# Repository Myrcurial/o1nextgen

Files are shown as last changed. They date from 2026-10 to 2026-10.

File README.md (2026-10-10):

# o1nextgen

A general-purpose Z80 bus interposer for the Osborne 1, built around the
Raspberry Pi Pico 2 W (RP2350 + CYW43439 WiFi), plus the research and
reverse-engineering work it enables — and, downstream, a modern-parts
Osborne 1 reproduction (the "O1 Next Generation").

## Goals

The Osborne 1 places all peripherals in memory-mapped banks and the Z80
has a simple, slow (4 MHz) external bus. A passive/active interposer
between the Z80 and its socket, connected to a Pico 2 over USB, enables:

1. **Bus analyzer** (passive): cycle-accurate capture of address/data/
   control traffic, streamed over USB — hardware equivalent of emulator
   machine-state introspection.
2. **Peripheral synthesizer** (active): emulate period hardware —
   RT-60A real-time clock, SCREEN-PAC 80/104-column video, IEEE-488
   "Drive C" ramdisk/storage, CoPower-88 mailbox interface.
3. **CPU emulation shim**: virtual CoPower-88 (8088) so original SWP
   software runs on machines without the (rare) physical board.

### Networked peripherals (Pico 2 W)

C64 Ultimate-style: rich browser UI on the Pico 2 W's HTTP server, plus a
small CP/M-side utility for in-machine control — no local mods required.

4. **Floppy interposer / image library** (Gotek / FlashFloppy analogue):
   interrupt the Shugart bus between motherboard and drives; mount
   `.IMD`/`.HFE` images to either drive bay, or to "Drive C" as a
   persistent RAM disk. Image library managed over WiFi (browser) or via
   a CP/M `MOUNT.COM` talking to the Pico through a mailbox port.
5. **WiFi modem** (Zimodem-style): Hayes-compatible AT command set +
   telnet, presented via the Osborne's memory-mapped 6850 ACIA registers
   (bank 2). Works with period comm programs (Kermit, XMODEM, etc.).
   **Extended scope (#56):** SSH transport (ESP32-class Zimodem fork) and
   baud-rate buffering — also designed as a *severable module* usable
   standalone on the MODEM (P1) port. Ref: https://github.com/bozimmerman/Zimodem
6. **Virtual printer**: capture Centronics-mode output on the IEEE-488
   port and render to PDF emulating a period 9-pin Epson MX-80 —
   two fonts, double-wide, italics, bold, underline; *no* graphics
   printout (ESC K/L) support. PDFs served over the HTTP interface.

> Timing note: CYW43 radio activity adds jitter. Bus capture and MFM
> floppy emulation run pinned to core1/PIO with WiFi IRQs fenced off,
> or WiFi is gated during capture/flux windows.

## Projects this supports

- **SWP CoPower-88 driver recovery for Osborne 1** — Kaypro and Zorba
  drivers exist; the Osborne version does not. Diff the known drivers,
  extract the host↔8088 protocol, port to the Osborne BIOS.
- **IEEE-488 mass storage** — Pico-based GPIB device emulating the
  "Drive C" ramdisk / period hard-disk products, with an updated O1
  boot disk.
- **Real-time clock** — emulate the RT-60A so original software works
  on unmodified machines.
- **USB keyboard adapter (#47)** — standalone RP2040 board on the P4
  keyboard connector: plug in any USB HID keyboard, no other mods.
  Doubles as the matrix-injection firmware for the interposer's
  web-KVM personality (#45).
- **O1 Next Generation (#49/#52)** — modern-parts Osborne 1
  reproduction running original ROMs/software, in two form factors:
  a 1:1 mainboard replacement for a stock chassis, and a ~8 cm thick
  "lunchbox" portable (O1A blue/grey industrial design, 8" 4:3 LCD,
  USB-C PD / 18650 power). See `hardware/o1ng/`.
- **FATCOPY (#51)** — native CP/M↔MS-DOS FAT12 (360K) file-copy
  utility; a PIP sibling for exchanging files with PC diskettes.

## What's changed since this README was first written

Phase 0 research (#1) has largely landed; see `docs/` and `research/`:

- **O1 mainboard memory + I/O map extracted** from the Rev E schematic
  (#40/#41) — `docs/o1-memory-io-map.md`.
- **Rev E schematic set indexed and extracted** (#64): the 12-page scan is
  actually *two* drawings — disk electronics (DWG 1A3004) plus the mainboard
  (DWG 1A2011-00 Rev E, sheets 1–9). The Z80 socket and the P8 floppy connector
  are now read from the primary source, and a native-resolution region renderer
  makes the rest readable — `docs/o1-mainboard-schematic.md`.
- **The O1 runs headless as an oracle** (#64): MAME's `osborne1` driver plus a
  small Lua harness boots CP/M and reads the screen straight out of video RAM,
  and `tools/check_o1_map.sh` goes further — it interrogates the running machine
  over its own bus and asserts the documented memory and I/O map. That is how we
  found that the bank latch does not persist across instruction fetches —
  `docs/o1-mainboard-schematic.md` §6–7a.
- **MODEM (P1) port documented** (#57): it is **TTL, not RS-232** —
  DE-9P feeding the 6850 ACIA directly, with an asymmetric *bipolar*
  RXD input — the clean attach point for the WiFi modem module.
- **P4 keyboard pinout corrected** (#48): O1A plug has 24 holes (inner
  20 mate); **pin 19 = +12V** via jumper J6 + R21 — power source for
  the USB keyboard adapter.
- **Logic family settled** (#54): all O1s are NMOS Z80s → **74AHCT/HCT**
  level shifting (replaces the earlier 74LVC245 note below). Interposer
  gets its **own dedicated 5 V feed** (sized for WiFi bursts).
- **Clocking documented** (#55): one-oscillator design + the "2x
  business turbo" option (and why baud buffering in #56 matters).
- **Disk tooling built** (#2/#34): TD0 decompressor + CP/M filesystem
  extractor in `tools/`; Kaypro CoPower-88 disks extracted; CoPower-88
  host protocol inferred from Kaypro vs Zorba (#36). Upstream cpmtools
  kpiv misread tracked in #35.
- **Peripheral analyses done**: Drive C GPIB ramdisk (#33), RT-60A RTC
  (#37), OCC1 ACT-1982 Z80-interposer winchester (#32).
- **Interposer prior-art survey** (#31) and **photo survey** of the
  host machine (#38) complete.
- **Osborne1FloppyAdapter KiCad project archived** with provenance (#50)
  — `research/osborne1/floppy-adapter/`.
- **Lunchbox concept render** (#53) — `docs/design/`.
- New scope filed: web-KVM console (#45), char-gen ROM capture (#44),
  G2 multi-format diskette support (#30), 1:1 replacement board +
  lunchbox case/power research (#52), FATCOPY (#51), SSH modem (#56).

## Repository layout

- `research/` — collected documentation, disk images, schematics
  - `research/copower88/kaypro/` — Kaypro CoPower-88 CP/M + MS-DOS disks,
    extracted CP/M contents + disassemblies
  - `research/copower88/zorba/`  — Zorba SWP disks, schematics (611-0003),
    system guide, advertisement
  - `research/drive_c/`          — Drive C IEEE-488 ramdisk image + manual
  - `research/rtc/`              — RT-60A real-time clock disk + manual
  - `research/harddisk/`         — OCC1 hard disk driver disk image
  - `research/osborne1/`         — O1 Technical Manual, mainboard schematic
    (Rev E), modem/serial + keyboard pinout sources, archived
    Osborne1FloppyAdapter KiCad project
  - `research/screenpac/`        — SCREEN-PAC service manual
  - `research/pictures/`         — high-res photos of the host machine
    (mainboard w/ double-density upgrade, SCREEN-PAC, CoPower-88 top/bottom,
    interposer)
- `docs/` — working notes and analysis: O1 memory/I/O map, modem/serial
  pinouts, CoPower-88 protocol + schematics, Drive C protocol, RT-60A
  register map, OCC1 hard disk analysis, interposer prior-art survey,
  photo survey, research-gap decisions, lunchbox concept renders
- `hardware/` — hardware device definitions (see `hardware/README.md`):
  Z80 interposer, front-panel UI pod, USB keyboard adapter, severable
  WiFi modem module, floppy adapter, O1 Next Generation reproduction
- `firmware/` — on-device firmware, one folder per component (see
  `firmware/README.md`): RP2350 interposer personalities (bus analyzer,
  RTC, printer, floppy, Drive C/GPIB, ScreenPac video, KVM, CoPower-88
  shim, web UI), ESP32 Zimodem fork, RP2040 keyboard matrix
- `software/` — Osborne-side CP/M software (see `software/README.md`):
  MOUNT.COM, FATCOPY, CoPower-88 driver, updated boot disk; plus the
  no-new-code deliverables (existing period drivers/configs, docs only)
- `tools/`   — disk image pipeline: TD0 decompressor + CP/M filesystem
  extractor (`cpmfs.py`, `edsk2raw.py`, `extract_all.sh`);
  `tools/trace-analyzer/` (planned) host-side bus trace capture;
  `tools/research/` for keep-worthy research/one-off code

## Hardware notes

- Z80 @ 4 MHz; RP2350 samples synchronously off the CPU clock via PIO.
- Target board: **Pico 2 W** (RP2350 + WiFi) — networked peripherals
  need the radio; the analyzer/synth personalities work on either.
- Level shifting: Z80 bus is 5V, RP2350 is 3.3V. **Settled: 74AHCT /
  74HCT** — all O1s are NMOS Z80s (production ended 1983; CMOS Z84C00
  didn't ship until 1985). AHCT/HCT is correct in both directions
  against NMOS I/O; 74LVC-class is marginal on tired NMOS outputs.
- Power: interposer gets its **own dedicated 5 VDC feed** near the Z80
  socket, sized for Pico 2 W WiFi bursts (~300 mA+).
- Filter /RFSH refresh cycles from traces.
- Must be stackable/coexist with SCREEN-PAC and CoPower-88 interposers
  on the fully-loaded machine.

## Sources

Full per-file provenance: `research/README.md`.

- Osborne 1 schematics and technical/service manuals: bitsavers.org (`pdf/osborne`)
- Drive C, RT-60A, OCC1 hard disk, diagnostics, Osmosis, Nuevo DD manual: bitsavers.org (`bits/Osborne/Osborne1/`)
- Shipped application library (14 disks): Dave Dunfield's ImageDisk archive, `dunfield.classiccmp.org`
- ROM images (stock revisions, vid8): Don Maslin's archive, retroarchive.org/maslin
- ROM 1.44 + CBIOS source, OZROM 1E, ScreenPac Rev A: github.com/BrettHallen/Osborne_1
- Adaptec ACB-4000 hard-disk software: archive.org/details/md-utilities-adaptec-4000-controller-ver.-1.93-osborne
- Kaypro CoPower-88 images: retroarchive.org/maslin
- Zorba SWP docs/schematics: zorba.z80.de/swp.htm (ZEPS)
- Osborne 1 Technical Manual (interface pinouts): kev.pulo.com.au
- GPIB reference implementation: NODISKEMU (nils-eilers) / cbmSD (cbmsteve.ca)

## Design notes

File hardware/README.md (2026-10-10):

# hardware/

Hardware device definitions for the o1nextgen project. Each subfolder is
one physical device contemplated in the GitHub issues, holding its
interface spec, design decisions, and (eventually) KiCad design files.
Status ranges from "concept definition" to "ready for schematic entry" —
no PCB layouts exist yet (Phase 1, issue #11).

## Devices

| Folder | Device | Issues | Status |
|---|---|---|---|
| `interposer/` | Z80 bus interposer — the core board. **Rev A engineering sample** (`interposer/reva/`, 2-off, SMD): active interposer w/ SMT Z84C00, /BUSRQ bus mastering (memory R/W + code injection), Pico 2 + ESP32-C3, W25Q library flash. Rev 0 passive probe superseded (kept for record) | #11, #12, #13, #15 | Rev A ES schematic generated, ready for KiCad capture review + routing |
| `front-panel-ui/` | Front panel faceplate & UI pod — SD/USB storage, VGA/HDMI out, OLED, FlashFloppy-style controls, modem LED bank | #14 | Concept |
| `usb-keyboard-adapter/` | Standalone RP2040 USB-HID → P4 keyboard adapter ("jam a USB keyboard into an O1"); two power variants: internal +12V (J6) or external powered-hub for no-open-case use | #47 | Reference design defined; spec validation pending |
| `wifi-modem-module/` | Severable WiFi modem (ESP32 Zimodem fork: telnet + SSH, baud buffering) for the MODEM (P1) TTL port; ships with COMM PAC-look case STLs for the left storage pocket | #56, #21, #57 | Concept; P1/DE-9 pinout + levels documented |
| `floppy-adapter/` | Switchable Gotek/physical-drive daughter card on the mainboard floppy connector — both physical drives *or* Gotek-as-drive-A + physical B, remote switch, switched Gotek 5 V; no cable cutting | #62, #20, #30 | Rev A schematic captured (`floppy-adapter.kicad_sch`); open questions settled (design doc §8); ready for footprint/routing review |
| `o1ng/` | O1 Next Generation — modern-parts Osborne 1 reproduction: faithful 1:1 replacement mainboard (socketed DIP-40 Z80, interposer as upgrade path; block-level KiCad skeleton in `o1ng/o1ng-lff/`) + fully integrated "lunchbox" portable (8 MHz turbo-capable, onboard flash library), shared USB-C PD power architecture | #49, #52, #53, #55 | LFF schematic skeleton generated; concept render exists |

## Cross-cutting decisions (settled)

- **Level shifting:** 74AHCT/74HCT for anything touching the Z80 bus —
  all O1s are NMOS Z80s (research-gaps #2, resolved 2026-10-09).
- **Interposer power:** dedicated 5 VDC feed near the Z80 socket, sized
  for Pico 2 W WiFi bursts (~300 mA+).
- **Stacking:** the interposer must coexist with SCREEN-PAC and
  CoPower-88 interposers on the fully-loaded host machine.
- **MODEM port (P1) is TTL, not RS-232** — but its RXD is a bipolar
  input; the modem module must swing TX-toward-O1 negative for a clean
  mark. See `docs/o1-modem-serial.md`.
- **P4 keyboard connector:** pin 19 = +12V via jumper J6 + R21 — usable
  to power small adapter boards (see `usb-keyboard-adapter/`).

## Conventions

Each device folder contains a `README.md` with: purpose, host
interfaces, electrical/mechanical constraints, open questions, and links
to the tracking issues and supporting docs. KiCad projects land in the
same folders as `<device>.kicad_pro` when design begins.

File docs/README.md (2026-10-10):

# docs/ — the analysis

Everything we have **concluded** about the Osborne 1, one Markdown document per
area. This file is the index and the house style for the directory.

## The three-way contract

| Where | Holds | Test |
|---|---|---|
| `research/` | **sources** — manuals, ROMs, disk images, photographs, with provenance | "would we lose the ability to do this work if the upstream link died?" |
| `docs/` | **conclusions** — what we worked out, and how we know | "can someone build against this without re-reading the raw material?" |
| GitHub issues | **work** — what is left, who is doing it, what closes it | "is there a unit of work here that can be finished and verified?" |

A doc should cite the `research/` files it derives from and the issues it
serves. An issue should cite the doc that will carry its result. Nothing should
exist in only one of the three.

## House rules

1. **Cross-references must resolve on the branch being merged.** If you cite
   `docs/foo.md` or `research/bar/`, that file has to exist on the branch the PR
   merges from — see AGENTS.md. Do not cite a doc you are about to write in a
   different PR.
2. **Never duplicate the archive.** Link into `research/` rather than copying
   scans, ROMs or images into `docs/`. The archive is provenance-tracked; a copy
   here is just drift.
3. **Say how you know.** Distinguish *measured* (a MAME run, a byte comparison),
   *read from a primary source* (schematic, ROM source, manual) and *inferred*
   (naming, convention, someone's forum post). The Z80 pinout table in
   `o1-memory-io-map.md` §6 was wrong for a day because an inference was written
   down as a fact.
4. **Cite the issue numbers** you serve, in the text (`#40`, `#62`), so the
   issue and the doc point at each other.
5. **Mermaid is welcome** for bus/state/timing diagrams.
6. **Tables beat prose** for pinouts, port maps, register maps and inventories —
   and give units and addresses in the same base throughout.

## Status vocabulary

Each doc should carry a one-line status near the top, using these words, so the
gap review (`research-gaps.md`) and the issues can be cross-checked quickly:

| Status | Means |
|---|---|
| **Solved** | The question is answered and the answer is checkable from the doc |
| **Partially solved** | The main shape is known; a named sub-question is not |
| **Open** | Not answered |
| **Superseded** | The question stopped mattering (better route found, hardware decision taken) |

## The docs

| Doc | Answers | Issues | State |
|---|---|---|---|
| `o1-memory-io-map.md` | Memory banks, I/O decode, bank switching, interrupts, connector pinouts, free I/O windows | #40, #62, #64, #72 | Solved (port map confirmed by the ROM source; decode *granularity* is schematic-level) |
| `o1-mainboard-schematic.md` | Sheet-by-sheet index of the Rev E schematic set, device list, pinouts, the machine-level oracle | #62, #64 | Solved |
| `o1-rom-variants.md` | Every ROM image, CRC32s, the three MAME machines' ROM requirements, third-party ROM survey | #70, #44 | Solved |
| `o1-rom-source.md` | Index of the ROM 1.44 / CBIOS source, and the port map and interfaces it confirms | #72, #40 | Solved |
| `mame-emulation.md` | Running the three machines, ROM requirements, boot-disk compatibility, headless testing | #79, #24, #29 | Solved |
| `drive-c-protocol.md` | Drive C (IEEE-488 RAM disk) command set and handshake | #6, #22 | Partially solved — command set from `DCL`/`DFD.SPR` still to finish |
| `occ1-harddisk-analysis.md` | The Osborne 1 hard-disk products: interface, files, command set | #8 | Partially solved — two distinct products now identified; controller command sets open |
| `copower88-protocol.md` | CoPower-88 host protocol from the Kaypro + Zorba drivers | #3, #4, #5, #23 | Partially solved — residual doorbell/IRQ semantics |
| `copower88-schematics.md` | Walkthrough of SWP drawing 611-0003 (4 sheets) | #5 | Solved |
| `rt60a-analysis.md` | RT-60A register map, reconstructed from the manual | #7, #18 | Partially solved — needs a read against real hardware |
| `o1-modem-serial.md` | MODEM (P1) and RS-232 (P2) interfaces, 6850 ACIA | #21, #56 | Solved |
| `floppy-adapter-design.md` | Switchable Gotek / physical-drive daughter card | #20, #62 | Design |
| `interposer-survey.md` | Prior art: open-source Z80 bus interposers, sniffers, ICEs | #11, #17 | Survey |
| `virtual-peripherals-block-diagram.md` | Bus and address-space allocation for the virtual peripherals | #12, #16 | Design |
| `photo-survey.md` | Index of the project's own machine photographs | #9, #39 | Reference |
| `research-gaps.md` | **The status review**: every gap, where it stands, what is left | #1 | Living document |

## Subdirectories

| Path | Holds |
|---|---|
| `design/` | Generated artefacts — the "lunchbox" concept PDF/SVG (#52) |
| `mame-screens/` | Evidence screenshots from MAME runs, referenced by `mame-emulation.md` |

## Adding a doc

1. **Check whether an existing doc owns the area.** Extend it rather than adding
   a near-duplicate; `docs/` grew one document per *area*, not per question.
2. **Name it `<device>-<kind>.md`** — `protocol` (the contract a device speaks),
   `analysis` (what we worked out from a source), `design` (what we intend to
   build), `survey` (prior art). Kebab-case, lower case.
3. **Open with the status line**, then what the doc answers, then the sources.
4. **Add a row to the table above** in the same PR.
5. **If it closes a gap**, update `research-gaps.md` in the same PR.

## Relationship to the book

`#75` is the plan to assemble these documents into one coherent Osborne 1
reference once the research issues are closed. These docs stay the working
notes; the book is a consolidation pass, not a second source of truth. Write
them so they can be lifted into it — self-contained, sourced, and honest about
what is still unknown.

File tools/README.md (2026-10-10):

# tools/ — disk images, CP/M filesystems, scanned schematics, machine checks

## Pipeline

```
.td0 --[SAMdisk 4]--> .dsk (EDSK) --[edsk2raw.py]--> .raw --[cpmfs.py]--> files
.imd --[disk-analyse]--> .raw --[cpmfs.py]--> files
```

Run everything: `tools/extract_all.sh [path-to-samdisk]`

## Components

- **edsk2raw.py** — EXTENDED CPC DSK (SAMdisk output) to raw CP/M
  sector image. Sorts sectors by R id (handles interleave and Kaypro's
  side-continuous sector numbering: side0 = 0-9, side1 = 10-19).
  `--pad SECTRK,SECLEN` emits fixed-geometry images from partial dumps
  (missing sectors -> 0xE5).
- **cpmfs.py** — read-only CP/M 2.x list/extract (`ls`, `get`,
  `getall`). Explicit geometry presets: `osb1sssd` (Osborne 1 SD:
  40x10x256B FM, boottrk 3, 2K blocks), `kp2x`/`kpiv` (Kaypro DSDD:
  80 logical trk side-per-track x 10 x 512B, boottrk 1, 2K blocks).

## Reading scanned schematics (`schematic_render.sh`, `schematic_atlas.sh`)

Renders sheets — or a zoomed region of one sheet — from a scanned schematic
PDF. The archive schematics are 600 dpi bilevel scans; scaled to a screen the
pin numbers are unreadable, and the PDF's own text layer is a 1990s OCR pass
full of garbage, so they have to be read one region at a time at native
resolution.

```
tools/schematic_atlas.sh PDF [OUTDIR]                     # overview + tile grid, all sheets
tools/schematic_atlas.sh PDF build/atlas --sheet 5 --cols 3 --rows 3
tools/schematic_render.sh PDF --info                      # sheet size in px, page count
tools/schematic_render.sh PDF OUTDIR --sheet 12 --dpi 600 # one sheet, native res
tools/schematic_render.sh PDF OUTDIR --sheet 12 --dpi 600 --crop X Y W H
```

`schematic_atlas.sh` writes `OUTDIR/index.md` mapping every tile to the pixel
box it covers, plus `OUTDIR/sheet-NN/overview.png` and `rRcC.png` tiles. It
defaults to `build/atlas/` — gitignored, because the tiles are regenerable and
the *coordinates* are the durable part, so a region found by eye once can be
re-rendered exactly with `schematic_render.sh --crop`. Both tools require
poppler (`pdftoppm`, `pdfinfo`) — already needed by `ocr_pdf.sh`.

**Part numbers must be read at native resolution.** At 300 dpi `LS00`/`LS08`
and `LS138`/`LS139` are indistinguishable; an overview pass over the O1
mainboard got both wrong. The sheet index, the regions read this way, and what
that caution means for the device lists are in
`docs/o1-mainboard-schematic.md`.

## Machine checks (`check_o1_map.sh`)

Boots an Osborne 1 headlessly under MAME and interrogates it over its own bus,
then asserts what `docs/o1-memory-io-map.md` claims — which pages are RAM,
where the ROM is and how it mirrors, what the bank-switch ports do, and which
bank-2 I/O windows answer.

```
tools/check_o1_map.sh                    # 12 checks, exits non-zero on failure
O1_ROMPATH=... O1_FLOPPY=... O1_MACHINE=... O1_SECONDS=180 tools/check_o1_map.sh
```

`tools/o1_mame_probe.lua` holds the assertions and the method (RAM is told from
ROM by writing back the complement of the byte that was there and restoring it).

Requires `mame` and a ROM path. If the ROMs sit loose in one directory rather
than in an `osborne1/` directory or an `osborne1.zip`, the wrapper builds a
temporary rompath containing an `osborne1` symlink rather than making you
rearrange them.

**The boot image's name is a label, not a driver.** The `52-`/`80-`/`104-`
prefix records the video mode an image was prepared for, but it does **not** gate
what the image can boot: measured against MAME, all three of
`emulator-setup/floppies/*.imd` boot on `osborne1`, `osborne1sp` **and**
`osborne1nv`. What gates bootability is the CBIOS on the disk. The wrapper still
derives the machine from the prefix (52 → `osborne1`, 104 → `osborne1sp`,
80 → `osborne1nv`) and warns when it selects anything but the stock machine, but
pass `O1_MACHINE` explicitly when it matters. The measured matrix, and why the
Nuevo system disk is a separate problem, are in `docs/mame-emulation.md` §4.

It is the counterpart to `check_schematics.py`: that one checks our own boards,
this one checks our *understanding of the machine* against the machine. It has
already earned its keep — see `docs/o1-mainboard-schematic.md` §7a.

## Emulator setup (`emulator-setup/`)

The ROM sets and blank boot images the MAME checks need, committed so the
harness is reproducible without hunting for dumps:

- `emulator-setup/roms/` — **one `osborne1.zip` serves all three machines**
  (`osborne1`, `osborne1sp`, `osborne1nv`): `rev1.40.ud11`, `rev1.43.ud11`,
  `3a10082-00rev-e.ud11`, `char.ua15`, `7a3007-00.ud15`,
  `monrom-rev1.51-12.ud11`. `mame osborne1nv -verifyroms` reports *good*;
  `osborne1` and `osborne1sp` report *best available* because the only missing
  ROMs are the four BIOS revisions that have never been dumped (A, 1.2, 1.2.1,
  1.3). Per-machine requirement table: `docs/mame-emulation.md` §3; CRC
  inventory: `docs/o1-rom-variants.md`.
- `emulator-setup/floppies/` — `52-blank.imd`, `80-blank.imd`, `104-blank.imd`.
  Despite the name they are **not blank**: each is a double-density CP/M 2.2
  system disk (CBIOS 1.4, MBASIC, SYSGEN, PIP, SETUP, XDIR, XREF …), and the
  three differ by exactly two bytes in the boot area. All three boot on all
  three machines — see the correction above.

The ROMs duplicate `research/roms/` deliberately: `research/` is the
provenance-tracked archive, this directory is a working rompath. If the two
ever disagree, `docs/o1-rom-variants.md` is the tie-breaker.

Full setup, launch, disk-tool and headless-testing instructions:
**`docs/mame-emulation.md`**.

## Schematic checking (`check_schematics.py`)

Regenerates each board's netlist with `kicad-cli` and asserts the electrical
invariants the design depends on. Run it before committing any `.kicad_sch`
or `gen_*_sch.py` change:

```
python3 tools/check_schematics.py          # all boards
python3 tools/check_schematics.py -v       # per-net detail
```

Why it exists: a schematic can pass structural ERC and still be electrically
wrong. The interposer generators placed every pin mirrored (`y + py` where
KiCad needs `y - py`), and reva had a '595 sitting directly on top of a '165 —
ERC reported only `label_dangling` / `pin_not_connected`, nothing that named
the fault. Reading the netlist pin by pin found both. What it checks:

- **Datasheet pinouts.** Z80 DIP-40 (pin 11 = +5V, 29 = GND, 30 = A0) on every
  connector/CPU that mates with the O1's socket.
- **Connector pin usage.** The Gotek header carries exactly Loxley's 11 signal
  lines and never a power rail or 4 MHz; drive B is never switched.
- **Sheet geometry.** No two symbol bodies overlap, and no two differently
  named labels sit on the same point (that is a short).
- **No `NC` net.** Labelling unused pins "NC" ties them all together — on reva
  that joined four unused 74AHCT595 totem-pole outputs. Use no-connect flags.
- **ERC budget.** Per-type ceilings; any new violation type or any increase
  fails, so regressions cannot hide in the warning noise. Keyed on the type
  only — KiCad renames checks and moves them between error and warning across
  releases (KiCad 9's `label_dangling` error is KiCad 10's `isolated_pin_label`
  warning), so a severity-keyed budget would pin the gate to one KiCad version.
- **Generator drift.** Regenerates each board and compares netlists, so a
  committed `.kicad_sch` cannot silently diverge from its generator.

CI runs it on every change to `hardware/**/*.kicad_sch` or `gen_*_sch.py`
(`.github/workflows/schematic-check.yml`). Requires `kicad-cli` (KiCad 7+);
set `KICAD_CLI` if it is not on PATH. Standard library only.

## Tool evaluation notes (why this exists)

- **SAMdisk 4** (Simon Owen; built from source, macOS: cmake) —
  decodes TeleDisk TD0 including advanced compression. Cannot write
  IMD; refuses raw output for non-sequential sector ids -> we bridge
  via EDSK. `samdisk copy in.td0 out.dsk`.
- **disk-analyse** (Keir Fraser, Disk-Utilities) — does NOT read TD0,
  but converts IMD -> raw img cleanly and reports per-track format
  (great for unknown disks).
- **libdsk dsktrans** — failed on the Kaypro TD0 ("Bad format" after
  decompression checks) and on SAMdisk EDSK output.
- **cpmtools 2.23** (homebrew cpmls/cpmcp) — worked perfectly for
  Osborne SSSD (`osb1sssd`) raws, but silently misread the Kaypro DSDD
  image (stock `kpiv` def has blocksize 2048 vs actual directory
  structure; even corrected defs produced garbage, cause not fully
  diagnosed — possibly sides/boottrk handling). cpmfs.py replaces it
  for extraction; cpmtools remains handy for quick probes.
- **z80dasm 1.2.0** (brew) — OK for spelunking; linear sweep misaligns
  around data tables.

## Disk format cheat sheet (learned during #2)

- Osborne 1 SD: FM, 40 cyl, 10x256B sectors, R=1..10, boottrk 3,
  dir 64 entries (2K blocks).
- Kaypro 2X/4/10: MFM, 40 cyl x 2 heads, 10x512B per side, R 0-based
  continuous across sides (0-9 / 10-19), physical interleave in R,
  dir at logical track 1 (= cyl 0 head 1), 64 entries, 2K blocks.
- RT-60A.TD0 (bitsavers) is a DAMAGED dump: 27 no-id sectors ignored
  by SAMdisk, most tracks fragmentary; filesystem extraction fails.
  Needs a re-dump (see #7).

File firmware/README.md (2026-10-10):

# firmware/

Firmware deliverables for the o1nextgen project, one folder per
component. Three target platforms: **RP2350** (Pico 2 W on the
interposer), **ESP32** (WiFi modem, shared between the severable module
and the interposer-onboard option), and **RP2040** (keyboard matrix
injection, shared between the standalone adapter and the KVM/second-
keyboard path).

See `software/` for code that runs on the Osborne itself (CP/M) and
`tools/` for host-side utilities.

## Components

| Folder | Platform | Component | Issues | Difficulty |
|---|---|---|---|---|
| `bus-analyzer/` | RP2350 | Passive cycle-accurate bus capture → USB/WiFi; includes the shared memory-map snoop/poke engine all personalities build on | #17 | Hard (timing-critical) |
| `rt60a-rtc/` | RP2350 | RT-60A real-time clock register emulation | #18, #37 | Easy |
| `virtual-printer/` | RP2350 | Virtual Epson MX-80: Centronics-on-IEEE-488 capture → on-device 9-pin raster → PDF (with tractor-feed page edges) over HTTP | #19 | Medium |
| `floppy-emulator/` | RP2350 | MFM flux interposer + `.IMD`/`.HFE` image library ("Drive C" RAM disk option) | #20 | Hardest |
| `drive-c-gpib/` | RP2350 | Drive C IEEE-488 ramdisk/storage device personality, incl. the **TurboPac** variant (Drive C as cache in front of a Trantor hard disk) | #22, #6 | Medium |
| `occ1-harddisk/` | RP2350 | ACT 1982 Z80-interposer winchester personality — original driver set already in hand, no Osborne-side code needed | #8, #32 | Medium |
| `screenpac-video/` | RP2350 | SCREEN-PAC 80/104-col video + HDMI/VGA out; char-gen socket tap, reads installed font ROM at init | #24, #44 | Medium-hard |
| `kvm-console/` | RP2350 + RP2040 | Web KVM: video snoop (reuses screenpac-video) + keyboard matrix injection (reuses keyboard-matrix) | #45 | Medium (composition) |
| `copower88-shim/` | RP2350 | Virtual CoPower-88: 8088 emulation + host mailbox protocol so SWP software runs without the physical board | #23, #3-#5 | Hardest; sequence last |
| `web-ui/` | RP2350 | C64 Ultimate-style HTTP interface: image library, modem, printer PDFs, status, control | #16, #27 | Medium |
| `zimodem-fork/` | ESP32 | Zimodem fork: Hayes/telnet baseline + SSH + double-sided baud-rate buffer | #21, #56 | Medium (fork-and-extend) |
| `keyboard-matrix/` | RP2040 | TinyUSB HID host → 8×8 matrix injection; shared by the standalone adapter, KVM, and front-panel USB port | #47, #45, #14 | Easy-medium |

## Project rule

**If we hold the drivers for a piece of period hardware, we plan a
personality for it.** Existing drivers mean zero Osborne-side software
work and a known-good test suite — these personalities are pure win.
(Current examples: Drive C, ACT/OCC1 hard disk, RT-60A.)

## Cross-cutting constraints

- **Radio jitter:** CYW43 activity adds jitter — bus capture and MFM
  flux emulation run pinned to core1/PIO with WiFi IRQs fenced off, or
  WiFi is gated during capture/flux windows.
- **One modem codebase:** the ESP32 Zimodem fork serves both the
  severable module and (leaning) an interposer-onboard ESP32; see
  `hardware/interposer/README.md` for the decision record.
- **Level shifting** is a hardware concern (74AHCT/HCT) — firmware
  assumes clean 3.3 V logic at the RP2350 pins.

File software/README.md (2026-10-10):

# software/

Software that runs on the Osborne 1 itself (CP/M 2.2, 64 KB Z80) plus
its packaging. Host-side tooling lives in `tools/`; on-device code
lives in `firmware/`.

## Components

| Folder | Component | Issues | Difficulty |
|---|---|---|---|
| `mount-com/` | `MOUNT.COM` — mount disk images from the Pico-hosted library via mailbox port | #27 | Medium |
| `fatcopy/` | `FATCOPY.COM` — CP/M ↔ MS-DOS FAT12 (360K) file copy, PIP-sibling syntax | #51 | Medium |
| `copower88-driver/` | Osborne 1 host driver for CoPower-88 (real board or interposer shim) | #26, #3-#5 | Hard |
| `rt60a-clock/` | RT-60A host software replica: CLOCK.COM/CLKSET reimplemented from the manual (original TD0 dump is damaged) | #7, #37 | Medium |
| `boot-disk/` | Updated O1 boot disk: storage + RTC integration, G2 multi-format DPBs, bundled utilities | #28, #30 | Medium (integration) |

## No-new-code deliverables (documentation only)

Where existing period software does the job, the deliverable is a
setup/usage doc shipped in `docs/` and on the boot disk — not new code:

- **Drive C ramdisk / interposer hard disk on native CP/M** — the
  original Drive C driver and OCC1 hard disk driver work as-is once the
  corresponding personality is running (#22, #8); write usage notes.
- **Stock Zimodem** — until the fork (`firmware/zimodem-fork/`) lands,
  stock ESP32 Zimodem covers telnet; document known-good config.
- **FlashFloppy/Gotek** — publish a known-good `FF.CFG` for the O1 and
  the switchable floppy adapter (`hardware/floppy-adapter/`).
- **cpmtools / disk-analyse recipes** — image in/out workflows for
  development (upstream kpiv fix tracked separately as #35).

## Constraints

- 64 KB Z80 CP/M 2.2: tiny TPA footprint; assembly or compact C
  (e.g. z88dk/Hi-Tech) only.
- Everything must fit the updated boot disk (#28) alongside the
  period drivers.
- Utilities use the BIOS disk path and must coexist with the G2
  multi-format disk-table changes (#30).

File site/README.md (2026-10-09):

# site/ — project blog (GitHub Pages)

Source for the project's GitHub Pages site: the story of how this
project came to be, hardware-mod write-ups for the author's Osborne
machines, and the ongoing build log.

## Publishing

Jekyll, minimal config. Two supported ways to publish (pick one in
repo Settings → Pages):

1. **GitHub Actions** (recommended): the standard "Deploy Jekyll site"
   workflow with the source directory set to `site/` — publishes on
   every merge to `main`.
2. **Branch deploy**: an Action (or manual step) that pushes `site/` to
   a `gh-pages` branch.

(The usual `/docs` Pages source is unavailable — our `docs/` is the
engineering-notes tree and stays as-is.)

## Layout

- `_config.yml` — Jekyll config (title, theme, permalinks)
- `index.md` — landing page
- `_posts/YYYY-MM-DD-title.md` — blog entries
- `assets/` — images; keep photos reasonably sized and prefer links to
  `research/pictures/` where the same photo already exists in-repo

## Planned articles (tracking issue)

- My first computer
- How I met Lee Felsenstein
- Finding the CoPower-88
- My battery-powered Osborne 1
- Modification to support Gotek drives with 3D-printed floppy-disk
  faceplate
- Why this project at all
- Build log (1/n)

Also planned: write-ups of the hardware modifications made to two of
the author's three Osborne machines (one extensive).

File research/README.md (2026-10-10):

# Research archive — sources and safety copies

This directory is the project's **research archive**: the documentation,
disk images, and photographs that the reverse-engineering and design work
under `docs/` and the GitHub issues depend on.

**These files are reserved as safety copies of the documentation necessary
to complete this project.** They are committed in-repo on purpose: upstream
archives move, go offline, or drop files, and this project cannot finish
without these specific documents. If an upstream link dies, the in-repo
copy is authoritative. Please do not "clean up" large PDFs or disk images
from this tree — their presence here is the point.

Where each item was sourced is recorded below, so provenance is preserved
alongside the copies.

**OCR convention:** most of the scans here have no text layer. When a
document is OCR'd for research, the text is committed **adjacent to the
PDF** as `<filename>.ocr.txt` (e.g.
`drive_c/Drive_C_Users_Manual.ocr.txt`) so it never has to be
regenerated. Regenerate with `tools/ocr_pdf.sh` if a better pass is
needed.

## osborne1/ — Osborne 1 mainboard documentation

| File | What it is | Sourced from |
|---|---|---|
| `2F00153-01_Osborne1TechnicalManual_1982.pdf` (19 MB) | Osborne 1 Technical Manual, 1982. No text layer — image-only scan. Theory of operations, banking, I/O, video, disk, keyboard. | [bitsavers](https://bitsavers.trailing-edge.com/pdf/osborne/osborne1/2F00153-01_Osborne1TechnicalManual_1982.pdf) |
| `OCC1_1A2011-00_Schem_RevE.pdf` (1.2 MB) | **Two drawing sets in one 12-page scan.** Pages 1–3: DISK ELECTRONICS, DWG 1A3004-00/01 Rev C (sheets 1–3 of 3 — the *drive's* own board). Pages 4–12: MAIN PC BOARD, DWG 1A2011-00 Rev E (sheets 1–9 of 9). 600 dpi bilevel; the embedded text layer is a useless early-90s OCR pass. Indexed, and the Z80 socket and P8 floppy pinouts extracted, in `docs/o1-mainboard-schematic.md` (#62). | [bitsavers](https://bitsavers.org/pdf/osborne/osborne1/OCC1_1A2011-00_Schem_RevE.pdf) (also mirrored as `Osborne_1_Schematics_1A2011-00_Rev_E.pdf` on RetroTechCollection/Internet Archive) |
| `OCC1_1A2011-00_Schem_RevE.ocr.txt` | OCR text layer for the above (per the convention below), generated 2026-10-10 at 400 dpi. Good enough to grep for component references; **not** reliable for pin-level detail — read sheets visually with `tools/schematic_render.sh`. | — |
| `keyboard/osborne_keyboard_pinout.html` + `keyboard/PROVENANCE.md` | Verbatim capture of the pinouts.ru Osborne 1 keyboard page: P4 pinout (incl. pin 19 = +12V via J6+R21) and the full key matrix map. Used by #45/#47. | [pinouts.ru](https://old.pinouts.ru/InputCables/osborne_keyboard_pinout.shtml), captured 2026-10-08 (provenance in the folder) |
| `floppy-adapter/` (README, LICENSE, `.sch`, `.kicad_pcb`, PROVENANCE.md) | Snapshot of WayneVisser's Osborne1FloppyAdapter KiCad project — passive Gotek adapter documenting the O1's "Shugart-like" floppy interface (power over the cable's unused pins). Used by #20/#49. | [github.com/WayneVisser/Osborne1FloppyAdapter](https://github.com/WayneVisser/Osborne1FloppyAdapter), captured 2026-10-09 (provenance in the folder) |
| `modem/o1techman-interface-extract.pdf` (1 MB, 10 pp) | Chapter 4 "Osborne 1 Interface Design" extract of the O1 Technical Manual: §4.1 IEEE-488 (P3), §4.2 RS-232 (P2), **§4.3 MODEM (P1)**. Authoritative source for the MODEM DE-9P pinout — **TTL levels, not RS-232** — incl. pin 4 MSB, pin 5 CTS, pin 8 MCB, pin 9 RI, pin 7 +12V via 22Ω. Used by #56 (and #21/#12). | [kev.pulo.com.au/osborne1](https://www.kev.pulo.com.au/osborne1/documents/o1techman.pdf), captured 2026-10-09 |

Basis for `docs/o1-memory-io-map.md` (#40) and
`docs/o1-mainboard-schematic.md` (#62). Both scans are image-only; extraction
is manual — OCR for text pages, and for schematics a native-resolution region
render (`tools/schematic_render.sh`) read by eye. The mainboard map is
independently cross-checked against the running machine in MAME; see
`docs/o1-mainboard-schematic.md` §7 (#64).

## inspired-by/ — adjacent projects

`inspired-by/README.md` — other Osborne 1 reinventions (MAME cyberdeck,
Raspberry Pi brain transplant, Loxley's Gotek mod): what they did, and
what we take from each. Contrast defines the project: **we keep the
original machine intact**.

## mx80/ — Epson MX-80 printer references

| File | What it is | Sourced from |
|---|---|---|
| `mx80/Epson_MX-80_Operations_Manual.pdf` | Epson MX-80 operation manual; Appendix 4 (PDF p. 97+) has the character-font tables (6×9 matrix) and ESC code reference. | [Internet Archive / manualsbase](https://dn790002.ca.archive.org/0/items/manualsbase-id-381505/381505.pdf), captured 2026-10-09 |
| `mx80/EPSON_MX-80_Fonts_v1.0.zip` + `mx80/fonts/` | Michael Walden's MX-80 font pack (CC BY-NC-SA 4.0). Convenience cross-check; see the folder README for the double-strike/2×-width caveat. | [mw.rat.bz/MX-80](https://mw.rat.bz/MX-80/), captured 2026-10-09 |

Also: `drive_c/Drive_C_Users_Manual.ocr.txt` — OCR text layer for the
image-only Drive C manual scan (generated 2026-10-09 per the OCR
convention above; source of the TurboPac details used by
`firmware/drive-c-gpib/`).

References for the virtual Epson MX-80 printer personality (#19).

## screenpac/ — OCC ScreenPac (80-column upgrade)

| File | What it is | Sourced from |
|---|---|---|
| `2F00040_service_2ndEd_1983.pdf` (12 MB) | Osborne Field Service Manual, 2nd Edition, 1983. Covers the ScreenPac upgrade (Z80 + char-gen socket taps, dual-port video RAM). §6.12 documents the ScreenPac IC-harness fly-lead solder connections (used by `firmware/screenpac-video/`). | [bitsavers](https://bitsavers.trailing-edge.com/pdf/osborne/2F00040-00_Service2ndEdition_1983.pdf) |
| `2F00040_service_2ndEd_1983.ocr.txt` | OCR text layer (per the convention above), generated 2026-10-09 | — |

The ScreenPac is the mechanical/electrical template for the interposer and
for the video-output (HDMI) personality (#24, #9 photos).

## copower88/ — SWP CoPower-88 (Z80-coprocessor board being reverse-engineered)

| Path | What it is | Sourced from |
|---|---|---|
| `zorba/Co-Power-88guide.pdf`, `zorba/Co-Power-88advert.pdf`, `zorba/611-0003-1..4.pdf` | SWP CoPower-88 user guide, advertisement, and SWP technical document scans (Zorba-flavored set) | [zorba.z80.de](http://zorba.z80.de/files/swp/) — the Zorba Portable Computer archive site |
| `zorba/*.td0`, `kaypro/*.td0` | TeleDisk images of CoPower-88 CP/M-86 / DOS boot disks (Zorba and Kaypro versions) | zorba.z80.de (exact path not recorded in repo history) |
| `zorba/extracted/`, `kaypro/extracted_cpm/`, `*/disasm/` | CP/M files extracted from those images by the project pipeline (#2), and disassemblies of the CoPower RAM-disk/DOS drivers | Derived in-project — not external sources |
| `swp/Copower_User_guide.pdf`, `swp/Swp_ad.jpg` | Fuller CoPower-88 user guide (4.7 MB, not the Zorba set) and an SWP advert scan | [kayprojournal.com `Swp_copower_88`](https://kayprojournal.com/index.php/Swp_copower_88) — `File:Copower User guide.pdf`, `File:Swp ad.jpg` |
| `swp/1600px-73356_8088_card.jpg`, `swp/1600px-73356_mem_card.jpg`, `swp/866px-73356_cpu_card.jpg` | Board photographs of the CoPower-88 8088 card, memory card and CPU card — held as MediaWiki thumbnails (1600 px / 866 px) of `File:73356 8088 card.jpg`, `File:73356 mem card.jpg`, `File:73356 cpu card.jpg` | Same page: [kayprojournal.com `Swp_copower_88`](https://kayprojournal.com/index.php/Swp_copower_88) |

The whole `swp/` set is from that one page. Confirmed 2026-10-10 by querying the
wiki's API (`list=allimages` and `prop=images&titles=Swp copower 88`) and matching
all five `File:` names exactly — not by reading the rendered page text. The wiki
also carries `File:Copower sch 1..4.pdf`, a second copy of the SWP schematics we
hold from zorba.z80.de.

Basis for #3/#4/#5 (CoPower-88 protocol analysis). The board's own 8088 ROM is
`roms/swp-p88.rom` — see `roms/` below and #70.

## drive_c/ — Drive C (IEEE-488 ramdisk, #6)

| Path | What it is | Sourced from |
|---|---|---|
| `Drive_C_Users_Manual.pdf` | Drive C user manual (IEEE-488 virtual disk drive) | [bitsavers `bits/Osborne/Osborne1/Drive_C/`](https://bitsavers.org/bits/Osborne/Osborne1/Drive_C/) (upstream name `Drive_C_-_Users_Manual.pdf`) |
| `DRIVE_C.IMD` | ImageDisk image of the Drive C utility disk (label comment `Drive C for the Osborne 1 computer`) | same folder — **not** imaged in-project; corrected 2026-10-10 |
| `Drive_C_disk_label.jpg` | Photo of the physical disk label | same folder (15 044 B, byte-identical) — **not** a project photo; corrected 2026-10-10 |
| `extracted/` | Files extracted from `DRIVE_C.IMD` by the project pipeline (#2) | Derived in-project |

## rtc/ — RT-60A real-time clock (#7)

| Path | What it is | Sourced from |
|---|---|---|
| `RT-60A_Manual.pdf` | RT-60A RTC manual (JG Communications) | [bitsavers `bits/Osborne/Osborne1/Osborne_1_Real_Time_Clock/`](https://bitsavers.org/bits/Osborne/Osborne1/Osborne_1_Real_Time_Clock/) (upstream name `RT-60A_Real_Time_Clock_Manual_-_Osborne_1.pdf`) |
| `RT-60A.TD0` | TeleDisk image of the RT-60A utility disk — **a damaged dump** (27 no-id sectors); filesystem extraction fails, see `tools/README.md` | same folder |

## harddisk/ — ACT/OCC1 hard disk (#8)

| Path | What it is | Sourced from |
|---|---|---|
| `OCC1_HARDDISK.IMD` | ImageDisk image of the OCC1 hard-disk system disk (label comment `act-osborne / hard disk software / rev 2`) | [bitsavers `bits/Osborne/Osborne1/_floppy_images/`](https://bitsavers.org/bits/Osborne/Osborne1/_floppy_images/) — **not** imaged in-project; corrected 2026-10-10 |
| `extracted/` | Files extracted from the image, incl. `hardbios.hex` | Derived in-project |

## adaptec/ — Adaptec ACB-4000 hard-disk software (2026-10)

Raw Osborne 1 SSSD floppy images (102 400 B = 40 tracks × 10 sectors × 256 B,
**no IMD header**) each with a photo of the disk's label. Source: Internet
Archive, [`md-utilities-adaptec-4000-controller-ver.-1.93-osborne`](https://archive.org/details/md-utilities-adaptec-4000-controller-ver.-1.93-osborne).

| File | What it is |
|---|---|
| `MD Utilities Adaptec 4000 Controller Ver. 1.93 Osborne.img` | Adaptec ACB-4000 utilities |
| `MD Utilities Adaptec 4000 Controller Ver. 1.93 Osborne - MD-10 MD-20.img` | Same, for the MD-10/MD-20 drive pair |
| `Osborne Hard Disk Control Software Version 2.01 (1984).img` | Osborne's own hard-disk control software |

Together with `acb4000a.rom` (Maslin's archive) this identifies the controller
behind `harddisk/OCC1_HARDDISK.IMD` — issue #8.

## diagnostics/ — Osborne 1 confidence tests (2026-10)

| File | Label comment |
|---|---|
| `DIAG_2.04.IMD` | `2.04 / diagnostics` |
| `OCC1_DIAG_2.1.IMD` | `occ diag / ver 2.1 / 12/31/84` |

Source: [bitsavers `bits/Osborne/Osborne1/_floppy_images/`](https://bitsavers.org/bits/Osborne/Osborne1/_floppy_images/).
These are the known-good boot images the validation matrix (#29) needs.

## nuevo/ — Nuevo Electronics double-density upgrade (2026-10)

| File | What it is | Sourced from |
|---|---|---|
| `Nuevo_Electronics_DD_Upgrade_Manual.pdf` (13 MB) | DD upgrade manual | [bitsavers `bits/Osborne/Osborne1/`](https://bitsavers.org/bits/Osborne/Osborne1/) (13 810 755 B, exact match) |
| `OS1NUEVO.IMD` | `Osborne 1 with DD and 80 col mods` boot disk, re-imaged 2026-10-10 with Disk-Utilities | derived in-project |

> **Removed 2026-10-10: `NUEVO151.BIN`.** It was a byte-identical duplicate of
> `tools/emulator-setup/roms/monrom-rev1.51-12.ud11` — same 4096 bytes, SHA-256
> `aec8f5be127fdff5d30cae0b7f45ee48d13a8c1d5745a262b944b9ba67778906`, CRC32
> `298da402` — verified with `cmp` before deletion. It carried no provenance of
> its own, so the tracked emulator-set copy, which has a recorded source, is the
> one we keep. The BIOS strings are unchanged by this: `COPYRIGHT 1983, OSBORNE
> COMPUTER CORP. / COPYRIGHT 1984, NUEVO ELECTRONICS CORP.`

Nuevo shipped **two** products — a DD upgrade and an 80-column board — and
neither matches Osborne's own implementation of that function; see #73.

`OS1NUEVO.IMD` **is** the Nuevo 80-column system disk: its system area carries
`CBIOS vers 1.5` and the text *"THIS IS AN EIGHTY (80) COLUMN DISPLAY FOR THE
OSBORNE ONE"*. It does **not** currently boot under MAME — it prints the CBIOS
banner and stops (measured over 260 emulated seconds; the pristine upstream copy
behaves the same), which blocks validating the Nuevo video path in the emulator.
See #79 and `docs/mame-emulation.md` §4.

## osmosis/ — Osmosis Computer upgrades (2026-10)

Source: [bitsavers `bits/Osborne/Osborne1/Osmosis_Upgrades/`](https://bitsavers.org/bits/Osborne/Osborne1/Osmosis_Upgrades/) — all seven files byte-for-byte identical.

`Osmosis_CPM_Disk_Emulator.pdf`, `Osmosis_80_Column_Board.pdf`,
`Osmosis_SSDD_Upgrade.pdf`, `OSMO-EMU.TD0`, `OSMOS-DD.TD0`, plus two disk-label
photos. Osmosis likewise shipped two products (a CPM disk emulator and an
80-column board). **The 1983 CPM Disk Emulation System is direct prior art for
this project** — see #73 and `inspired-by/`.

## gotek/FF/ — working Gotek configuration (2026-10)

`FF.CFG` + `IMG.CFG` — the project's own Gotek configuration for the O1:
`interface = shugart`, `pin02`/`pin34` = `nc`, and an `IMG.CFG` default of
40 cylinders × 1 head × 16 × 128 B, FM, 125 kbit/s — i.e. O1 SSSD. Captured
from the physical Gotek, so these are primary sources, not downloads.
Used by #62 and #20.

## roms/ — ROM images (2026-10)

Canonical inventory, CRC32s and the third-party ROM survey are tracked in #70.
Files here come from two sources:

- `os1-143.rom`, `os1-144.rom`, `os1-vid8.rom`, `os1vid80.rom`, `swp-p88.rom` — [Don Maslin's ROM archive](http://www.retroarchive.org/maslin/disks/roms/) on retroarchive.org
- `OZROM-1E/OZROM_1E.BIN`, `OZROM-1E/OZROM_1E_Manual.pdf`, `OCC1_ScreenPac_RevA.BIN` — [github.com/BrettHallen/Osborne_1](https://github.com/BrettHallen/Osborne_1) `ROM/`

`swp-p88.rom` is **8088 code, not Z80**: the SWP co-processor board's own ROM.
The board and interposer card are common to every host machine (only the driver
varies), so this is the 8088-side firmware of the CoPower-88 family — #3/#4/#5.

`OZROM-1E/OZROM_1E_Manual.ocr.txt` — OCR text layer for the OZROM manual
(image-only scan; generated 2026-10-10 at 300 dpi with `tesseract`, per the OCR
convention above). Good enough to grep for the technical appendices — which is
how the IEEE-488 removal and the 3 KB video window were found (#81) — but not
reliable for exact code or pin detail.

## shipped-software/ — the shipped application library (2026-10)

Fourteen ImageDisk images of the disks that shipped with (or were published
for) the Osborne 1. The ImageDisk label comment is quoted because it is the
disk's own identity. Source: **Dave Dunfield's ImageDisk archive**
(`dunfield.classiccmp.org`, which rotates its directory to discourage deep
links) — `d/osborne1.zip` and `d/o1ddsys.zip`, byte-identical to these copies.

| File | Label comment |
|---|---|
| `O1CPM.IMD` | `Osborne-1 CP/M System Disk / Double Density` |
| `O1CBMB.IMD` | `Osborne 1 - CBASIC/MBASIC / Double Density` |
| `O1SCALC.IMD` | `Osborne 1 - SuperCalc 1.12 / Double Density` |
| `O1WSMM.IMD` | `Osborne 1 - WordStar/MailMerge 2.26 / Double Density` |
| `OS1SYSD.IMD` | `CP/M-2.2 system disk for Osborne 1 w/ DD drives / SSDD 1024 byte sector` |
| `OS1SYSS.IMD` | `CP/M 2.2 System Disk for Osborne 1 / SSSD 256 byte sector` |
| `OS1BASIC.IMD` | `CP/M 2.2 Basic Disk for Osborne 1` |
| `OS1DBASE.IMD` | `dBase II for the Osborne 1 on sysgened disk` |
| `OS1DIAS.IMD` | `CP/M 2.2 Diagnostics Disk for Osborne 1` |
| `OS1MCAL.IMD` | `CP/M 2.2 Mocro-Call Disk for Osborne 1 (Communications)` |
| `OS1MDM7.IMD` | `Modem 740 communications for Osborne 1` |
| `OS1UTLS.IMD` | `CP/M 2.2 Utilities Disk for Osborne 1` |
| `OS1XUTLS.IMD` | `Extended utilities for Osborne 1 w/ 80 column video card` |
| `OS1WRDST.IMD` | `CP/M 2.2 WordStar 3.0 Disk for Osborne 1` |

The corpus for the image library (#20), the updated boot disk (#28) and the
validation matrix (#29). Dunfield also publishes a 2005 single-density set
(`O1CPMS.IMD`, `O1CPMU.IMD`, …) which is deliberately **not** copied here.

## source-code/ — Osborne's own firmware source (2026-10)

| Path | What it is | Sourced from |
|---|---|---|
| `BIOS-144-source/` (18 files) | **The original Osborne ROM source**: `rom144.asm` (DOUBLE DENSITY ROM REV 1.44, Roger W. Chapman, 2/4/1983), `occbio05..95.asm` (OCC CBIOS Rev 1.41), `occram15/25.asm`, `occtxt6.ast` (ACT80 assembler equates), `bios141.gen`, `release.txt`, `tran.txt`. Basis for #72. | [github.com/BrettHallen/Osborne_1](https://github.com/BrettHallen/Osborne_1) `ROM/Source_Code_v144/` (all 18 file sizes match) |
| `OCCCBIOS.IMD`, `OCCROM.IMD`, `OCCUTIL.IMD`, `OSBIOSSR.IMD`, `OSBROM.IMD`, `OSROM13.IMD`, `OSUTLSRC.IMD` | OCC engineering **source disks** (1981–82): CBIOS, ROM rev B, utility programs, ROM 1.3. The ImageDisk comments carry the OCC part numbers (`4d2007-00 occbi00a.asm`, `rev b 9/12/81`). | bitsavers |

**Licensing:** `release.txt` is Osborne's 1985 letter permitting the First
Osborne Group to reprint the schematics and the BIOS listing, on condition that
any money goes to the non-profit FOG and that the trademark/copyright notices
are retained. FOG is long defunct and this material is already public in
several places — this copy came from a public GitHub repository. The notice is
retained verbatim; if the terms ever need re-examination, that is the file.

## pictures/ — machine photographs

`IMG_4856.jpeg` … `IMG_4871.jpeg` — disassembly/mainboard/upgrade-board
photos of the project's own machines (mainboard, double-density upgrade,
ScreenPac, CoPower-88). Taken in-project for #9; these are primary sources,
not copies. Further photo sets are tracked in #39.

## Provenance

The two long-standing **provenance gaps are closed**: the Drive C manual and
the RT-60A manual/TD0 both come from bitsavers'
[`bits/Osborne/Osborne1/`](https://bitsavers.org/bits/Osborne/Osborne1/)
(`Drive_C/` and `Osborne_1_Real_Time_Clock/`), as does `OCC1_HARDDISK.IMD` and
the two diagnostic disks (`_floppy_images/`). Four rows that had been recorded
as in-project work or as unknown URLs were corrected on 2026-10-10.

**Both remaining TODOs are closed (2026-10-10, #74):**

- `copower88/swp/` — kayprojournal.com's
  [`Swp copower 88`](https://kayprojournal.com/index.php/Swp_copower_88) page; all
  five files matched by `File:` name through the wiki API (CoPower-88 table above).
- `nuevo/NUEVO151.BIN` — removed as a byte-identical duplicate of the tracked
  `tools/emulator-setup/roms/monrom-rev1.51-12.ud11` (nuevo/ table above).

No provenance TODOs remain.

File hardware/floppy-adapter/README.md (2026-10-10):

# floppy-adapter — switchable Gotek/physical-drive daughter card

A daughter card that mounts over the mainboard / double-density board
floppy connector and makes **three drives available, two active**: both
original drives, *or* drive A + Gotek, selected by a user-accessible
switch. All interception happens at the mainboard-end connector — the
OEM floppy IDC cable is never cut or modified.

Inspiration (not a copy): Richard Loxley's Osborne restoration series —
[part 14](https://www.richardloxley.com/2018/04/24/osborne-restoration-part-14-usb-floppy-emulator-a-semi-permanent-solution/)
and [part 15](https://www.richardloxley.com/2018/04/25/osborne-restoration-part-15-usb-floppy-emulator-finishing-off/)
(also a YouTube series) — which proved the concept with a spaghetti of
hand-cut Dupont cables, an extension cable with a severed drive-select
line, and a DPDT switch + 5 V relay soldered onto the Gotek itself.
This design moves all of that work onto a PCB at the connector end of
the cable, where it belongs.

Tracking: **#62** (design spec + schematic). Feeds #20 (floppy
interposer personality) and #30 (G2 multi-format support). Prior art
archived by PR #50. Full design in
[`docs/floppy-adapter-design.md`](../../docs/floppy-adapter-design.md);
its seven open questions were **settled 2026-10-10** (§8 there) and the
**Rev A schematic is captured** (below).

## Design

- **Mezzanine mount:** plugs onto the mainboard (or DD-board) 34-pin
  floppy header; the OEM floppy cable re-plugs into a pass-through
  34-pin connector on the daughter card. Fully reversible, no
  modifications to the machine or its cables.
- **Second 34-pin connector:** routes the floppy bus out to a Gotek
  (FlashFloppy) mounted in one of the floppy storage pockets.
- **Switching:** drive-select A (pin 10) is routed on-card either to
  the OEM-cable pass-through (physical drive A) or to the Gotek
  connector. The remote switch lead carries only a low-current logic
  select line to an on-card switch element (relay or 74CBT-class bus
  switch) — the switch itself is a plain panel-mount SPST, trivially
  mounted next to the Gotek in the storage pocket.
- **Gotek power:** dedicated 5 VDC connection on the Gotek connector,
  fed via an on-card switch so the Gotek can be fully depowered in
  "both physical drives" mode. Both +5 V **and** GND are switched —
  switching one rail alone fails (`docs/floppy-adapter-design.md` §4.2).
- **Drive B is never switched** — it stays on the pass-through, so the
  machine always boots from a physical disk if desired. The Gotek takes
  drive A's place.
- **DS-A pull-up:** the O1's 150 Ω term pack lives on drive A, so the
  card adds a pull-up on the Gotek-side DS-A net (1 kΩ default) —
  `docs/floppy-adapter-design.md` §4.5.

## Signals carried to the Gotek

(Per the blog's audit — 11 lines plus power; the card routes the full
bus to be safe.)

| 34-pin | Signal |
|---|---|
| 8 | Index |
| 10 | Drive select A (**switched**) |
| 18 | Direction |
| 20 | Step |
| 22 | Write data |
| 24 | Write gate |
| 26 | Track 0 |
| 28 | Write protect |
| 30 | Read data |
| odds | Ground |
| — | +5 V (switched, on-card) |

## Lessons from the reference build (designed in, here)

- **Power-switching a Gotek is subtle.** Switching only +5 V fails —
  the O1's pulled-up signal lines parasitically power the board;
  switching only GND makes the *other* drive unreliable (shared +5 V
  reference with floating ground). The blog's fix was switching both
  rails with a DPDT plus a 5 V relay for drive select. We solve this
  properly on-card: high-side load switch for Gotek 5 V and a
  bus-switch/relay for drive select, so the remote switch handles no
  power at all.
- **Gotek physical fit:** with its top cover removed a Gotek fits a
  floppy storage pocket; top-facing headers make it too tall — plan a
  right-angle/side connection or direct-wire pads on the ribbon.
- **Cable egress:** a 34-pin ribbon won't pass the pocket ventilation
  slots; the daughter card should output the Gotek run on a slimmer
  cable (only the needed signals + power) that does.
- OLED display mods and FlashFloppy display-detect quirks are the
  user's Gotek-side choice, out of scope for the card.

## KiCad capture (Rev A)

- `floppy-adapter.kicad_sch` (+ `.kicad_pro`) — structural Rev A schematic.
- `gen_floppy_adapter_sch.py` — generator; edit the net tables and re-run
  (`python3 gen_floppy_adapter_sch.py`), then open/re-save in KiCad to
  normalise.
- **J1** female 2x17 socket (O1 logic-board P8), **J2** pass-through header to
  the OEM cable, **J3** Gotek signal header, **J4** switched Gotek power,
  **J5** panel switch, **K1** 4PDT relay, **D1/R1** flyback + coil pull-down,
  **R3/R4** DS-A pull-up, **R2+D2** optional indicator.
- Validated with `kicad-cli sch export netlist` (netlist matches the design
  doc's net table) and `kicad-cli sch erc` (0 errors).
- Layout follow-ups: the relay pin numbers are **DIP-14 logical placeholders**;
  assign footprints at layout (KiCad ships no G6A-434P footprint).

## Settled decisions (2026-10-10)

The seven design questions are closed — see
[`docs/floppy-adapter-design.md`](../../docs/floppy-adapter-design.md) §8 for
the evidence behind each. Highlights:

- O1 floppy header is **male** (logic-board P8), so **J1 is a female socket**.
- **Relay** (not solid-state) for Rev A.
- Switch **DS-A + both power rails** only — Loxley's proven minimum.
- **1 kΩ** DS-A pull-up default, **150 Ω** alternative footprint.
- Gotek drive-select jumper: **S1 first, S0 fallback** (bench-verify).
- Gotek sits in the **right-hand** pocket on a reduced ~12-line pigtail.

## Open items (not blocking capture)

- Mounting: piggyback footprint vs. standoffs over the DD board; confirm
  keep-outs against the mainboard schematic
  (`research/osborne1/OCC1_1A2011-00_Schem_RevE.pdf`) and host photos
  (`research/pictures/`).
- Interaction with the interposer's floppy personality (#20): document
  which device owns the bus in each configuration.
- G2 upgrade (#30): believed BIOS/DPB-only, nothing at the connector —
  confirm.

## References

- `research/osborne1/floppy-adapter/` — archived Osborne1FloppyAdapter
  KiCad project (connector/pinout prior art; **not** this design)
- `research/osborne1/OCC1_1A2011-00_Schem_RevE.pdf`
- Richard Loxley, Osborne Restoration parts 13–15 (concept origin)

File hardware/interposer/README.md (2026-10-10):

# interposer — Z80 bus interposer (core board)

The centerpiece of the project: a board that sits between the Osborne 1's
Z80 and its socket, carrying a Raspberry Pi Pico 2 W (RP2350 + CYW43439).

Tracks: #11 (Phase 1 hardware design), #12 (electrical/mechanical
interface spec), #13 (Rev A schematic + PCB), #15 (Rev B SMD).

## Personalities hosted (firmware, Phase 2 #16)

- Passive bus analyzer (#17) — cycle-accurate capture → USB/WiFi
- RT-60A RTC emulation (#18)
- Virtual MX-80 printer, IEEE-488 Centronics capture → PDF (#19)
- Floppy interposer + image library (#20)
- WiFi modem via 6850 ACIA snoop (#21)
- Drive C / IEEE-488 storage device (#22)
- Virtual CoPower-88 8088 emulation shim (#23)
- SCREEN-PAC 80/104-column video + HDMI (#24; taps the char-gen socket
  UA15, reads whatever font ROM is installed — #44)
- Web KVM console (#45): video snoop + keyboard matrix poke

## Electrical definition (settled decisions)

- **CPU interface:** standard Z80 DIP40 socket + socket-safe pin header;
  4 MHz bus sampled synchronously via PIO.
- **Level shifting:** 74AHCT (or 74HCT) both directions — all O1s are
  NMOS Z80s; AHCT/HCT matches NMOS I/O thresholds. (Decision
  2026-10-09, research-gaps #2; supersedes "74LVC245-class".)
- **Power:** own dedicated 5 VDC feed from a rail near the Z80 socket,
  sized for Pico 2 W WiFi bursts (~300 mA+). (Decision 2026-10-09.)
- **Modes:** passive-tap vs active-drive switching; mode jumpers.
- **Stacking:** must coexist with SCREEN-PAC and CoPower-88 interposers
  on the fully-loaded machine; pass-through height matters.

## Modem: personality vs. onboard ESP32 (decision to make)

Two ways to deliver the WiFi modem (#21/#56) from the interposer:

- **(a) Pure firmware personality:** the Pico 2 W's CYW43439 provides
  WiFi; the modem is a Zimodem-style reimplementation on the Pico SDK /
  lwIP, snooping/driving the memory-mapped 6850 ACIA. Fewer parts, but
  SSH is not realistic on the Pico 2 W and the radio shares the RP2350
  with timing-critical PIO work (WiFi IRQ fencing needed).
- **(b) Onboard ESP32 adjacent to the Pico 2 W:** the interposer
  carries the same ESP32 module as the severable modem
  (`../wifi-modem-module/`), running the Zimodem fork with SSH +
  baud buffering; the Pico 2 W just bridges ACIA traffic to it. More
  BOM, but SSH works today, the modem firmware is shared with the
  severable module, and RP2350 timing stays clean.

Current leaning: **(b)** — one modem firmware codebase across both
devices, SSH capability, and cleaner real-time behavior. Confirm
before Rev A schematic (#13).

## Onboard storage: built-in diskette library

**Decision: include onboard library flash in addition to removable
media.** SD/USB (via the front-panel pod) is the bulk store, but the
interposer should carry enough onboard flash to hold a **built-in
library — at minimum the boot diskette** — so the machine is useful
with no card or stick inserted (and the o1ng lunchbox can boot
"factory" images out of the box).

- Option A: SPI NOR flash (W25Q-class, 16–64 MB) — trivially enough for
  dozens of O1 images (a DD image is ~400 KB); cheap, easy.
- Option B: eMMC or a second SD — overkill; not needed at O1 image
  sizes.
- Leaning: **A** — a handful of SOIC-8 flash chips' worth of library is
  effectively free. Exact sizing settled with #20's image format.

## Mechanical / revision plan (revised 2026-10-09)

- **Rev 0 "test probe"** — **superseded** (kept in `rev0/` for the
  decision record, incl. the '165 snapshot front end that Rev A
  inherits). Parts lead time for a passive probe was within days of an
  engineering sample of the active board, so the passive step is
  skipped.
- **Rev A engineering sample (`reva/`, 2-off, almost all SMD):**
  active interposer — SMT Z84C00 on board (pull the original CPU, drop
  the interposer in), /BUSRQ bus mastering, 595/165 shift-register
  drive+capture fabric, Pico 2 module + castellated ESP32-C3 for WiFi,
  W25Q library flash. Design goal: **the dev partner controls the
  hardware** — memory R/W, ROM dumping (incl. the CoPower-88 monitor
  ROM, resolving research-gaps #4 by direct read), code injection +
  execute. See `reva/README.md`.
- Rev A production (#13): incorporates ES errata.
- **Rev B (#15) — a separate product, not a revision:** Rev A is the
  mastering/debug instrument; Rev B is the **live-cycle personality
  engine**. Full RP2350B pin allocation in `revb/README.md`. The
  enabling decisions:
  - **Zero direct address pins:** a 74AHCT688 window comparator
    (595-programmable match) + **/WAIT cycle stretching** — the
    period-correct slow-peripheral mechanism — replaces 16 direct
    address lines with 2 (ADDR_HIT, /WAIT drive).
  - Timing-critical direct set is only: D0–7, /MREQ, /IORQ, /RD, /WR,
    /M1, CLK, DATA_OE/DIR — 13 pins.
  - **HSTX is fixed to GP12–19** on RP2350 → HDMI there, either/or
    with VGA on the same range.
  - **Status/LED bank moves to the ESP32** (charlieplexed or I²C
    expander); SD on SPI (4-bit SDIO-via-PIO deferred); I²C pair
    reserved for front-panel OLED/encoder/expansion.
  - The Rev A 595/165 fabric carries over wholesale and remains the
    pressure-relief valve for any slow line.
- Ribbon-cable header to the front-panel UI pod (`../front-panel-ui/`),
  which also carries the second-keyboard USB-A path (see
  `../front-panel-ui/`).
- Optional second tap: 24-pin char-gen socket (UA15) for the video
  personality — pinout confirmation from ScreenPac install pages +
  mainboard schematic (research-gaps #3).

## Open questions

- Exact free I/O decode windows — resolved in `docs/o1-memory-io-map.md`;
  verify chosen peripheral port bases against it.
- /RFSH refresh-cycle filtering strategy for traces.
- Physical 2×5 IDC orientation for the modem P1 connection (same
  validation class as the P4 keyboard pinout).

## References

- `docs/o1-memory-io-map.md`, `docs/interposer-survey.md`,
  `docs/virtual-peripherals-block-diagram.md`, `docs/research-gaps.md`
- Host machine photos: `research/pictures/`

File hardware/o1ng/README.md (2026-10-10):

# o1ng — O1 Next Generation (modern-parts Osborne 1 reproduction)

A new PCB built from currently-available components that runs the actual
Osborne 1 ROMs and (nearly) all original software — with a Cherry MX
mechanical keyboard, the interposer's floppy/modem/printer/storage
personalities onboard, and composite video out (HDMI optional).

Tracks: #49 (feasibility + build), #52 (case + power research),
#53 (concept render: `docs/design/o1ng-lunchbox-concept.*`).

**Verdict from #49: feasible, medium complexity.** The O1 is almost
entirely memory-mapped commodity MSI/LSI — no custom silicon. CPUs are a
non-issue: CMOS **Z84C00 is in current production** (the replica
deliberately uses modern CMOS silicon where the interposer interfaces
AHCT to the original NMOS part).

## Machine decomposition (by difficulty)

| Block | Approach | Difficulty |
|---|---|---|
| CPU + RAM + ROM | Z84C00 (new), 64 KB SRAM (replaces 16× 4116 DRAM + refresh), 27C128/Flash BIOS | Trivial |
| Video | Char-gen + CRTC-class logic; composite out, HDMI option (interposer video personality reusable) | Moderate |
| Floppy | 360K half-height drive + onboard DD data separator (enables PC 360K MFM reads → FATCOPY, #51) | Moderate |
| I/O (serial/GPIB/RTC) | 6850 ACIA, IEEE-488, RTC — interposer personalities onboard | Moderate |
| Keyboard | Cherry MX matrix; O1-compatible scan encoding | Low–moderate |

## Shared power architecture (#52)

- **USB-C PD trigger board** as primary input: 15 VDC (or 19–20 V) PD →
  clean on-board +5V and +12V rails. Replaces the entire original PSU —
  and gets the RIFA caps out of the mix.
- **Battery option:** a ~15–19 V input rail suits an 18650 pack (4S).

## Form factors (share the power design)

1. **1:1 mainboard replacement** — drops into an otherwise-stock O1/O1A
   chassis. **As true to the original as possible**: a faithful
   reproduction of the stock machine, including a **40-pin DIP socketed
   Z80** (Z84C00) — deliberately socketed so the **interposer
   (`../interposer/`) is the upgrade path**: anyone wanting the advanced
   features (bus analyzer, virtual peripherals, WiFi modem, Gotek
   switching) installs the interposer onto this board exactly as they
   would on a 1982 original. **L-shaped board**: skinny arm services
   left-hand-side ports (front-left screw boss); chunky short side
   mounts front/rear right bosses. Stock port locations (front ports,
   power, internal video, floppy connectors) and only **four mounting
   screws** constrain layout.
2. **"Lunchbox" (O1 Next Generation)** — Dolch / Compaq Portable III
   idiom in **O1A blue/grey** industrial design; "keyboard seals the
   unit" aesthetic retained. Unlike the 1:1 board, this is a **fully
   integrated single board** — the interposer's capability set (video,
   storage, modem, keyboard input) is thoroughly grafted in rather than
   stacked on, following the original design language. One reason:
   integration keeps the timing margins needed for the **clock-doubled
   8 MHz "business turbo"** (#55) — limited usefulness, but everyone
   will be fine with it. **Onboard library flash** (SPI NOR, per
   `../interposer/` decision): a built-in diskette library with at
   least the boot diskette, so the lunchbox boots "factory" images with
   no SD/USB inserted; removable media remains the bulk store.
   ~8 cm thick: mainboard + 8" 4:3 LCD
   (composite/HDMI in) + 18650 pack, detachable flip-up keyboard.
   Optional rear "backpack" for a physical 5.25" half-height drive.

## Open questions

- Final video pipeline choice (discrete TTL vs small FPGA helper).
- LCD panel + input board sourcing for the lunchbox.
- Chassis fabrication route (sheet metal vs printed) for the lunchbox.
- Which interposer personalities are *onboard* vs *optional modules*.

## References

- `docs/design/o1ng-lunchbox-concept.pdf` / `.svg` (#53)
- `docs/o1-memory-io-map.md` (the machine's whole address space)
- Issues #49 (reproduction), #52 (case/power), #51 (FATCOPY)

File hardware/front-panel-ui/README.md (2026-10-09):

# front-panel-ui — faceplate & UI pod

COMM-PAC-style faceplate covering one floppy storage pocket, providing
local physical UI for the interposer without opening the case.

Tracks: #14.

## Contents

- SD card / USB stick socket (disk-image library media)
- **Second USB-A port: keyboard input via the interposer** — a USB HID
  keyboard plugged in here is injected into the O1's keyboard matrix by
  the interposer (reusing the `../usb-keyboard-adapter/` RP2040 matrix
  firmware, #45/#47). The **original keyboard stays plugged in and fully
  functional**; the USB keyboard is an optional second input that just
  works, both live simultaneously.
- VGA or HDMI video out (SCREEN-PAC personality, #24)
- Small OLED status display
- Rotary encoder or 5-way d-pad (FlashFloppy-style menu UI)
- Hayes/USR-style LED bank: CTS/RTS/TX/RX/RING etc. (modem personality)
- Ribbon cable back to the interposer (`../interposer/`)

## Constraints

- Must route through the existing front-panel ventilation / IEEE-488
  openings — no case cutting on the host machine.
- All electronics on the interposer side of the ribbon where possible;
  the pod is mostly connectors + display + LEDs to keep the cable
  simple and the front end 5 V/3.3 V logic only.

## Open questions

- OLED controller choice (I²C vs SPI over the ribbon).
- Exact pocket geometry vs. COMM-PAC faceplate dimensions (measure
  against host machine photos, `research/pictures/`).
- Whether video out is HDMI (RP2350 HSTX/DVI) or VGA (resistor DAC) —
  decided with the #24 firmware personality.

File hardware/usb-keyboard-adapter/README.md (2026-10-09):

# usb-keyboard-adapter — RP2040 USB-HID → P4 adapter

**A USB port on the Osborne 1 you can jam a normal USB HID keyboard into
and have it work.** Standalone, always-on upgrade: no interposer, no
WiFi, no BIOS changes. Also the matrix-injection firmware base for the
interposer's web-KVM personality (#45).

Tracks: #47 (split out of #45). Target: PCBway build.

## Reference design

- **MCU:** RP2040 running a USB HID host stack (TinyUSB host mode) →
  8×8 matrix state. Chosen over Pico 2 W deliberately: no radio needed,
  lowest cost, standard chip for retro USB-HID-host adapters.
- **I/O:** watch 8 host row-drive lines (inputs), drive 8 column lines
  open-collector (matching the stock 74LS05 stage) — 16 GPIO.
- **Level shifting:** O1 keyboard lines are 5 V TTL; RP2040 is 3.3 V.
  Rows need 5 V-tolerant input handling; columns driven via open-drain
  buffer (74LVC07-class) so the adapter never fights the host.
- **Power (variant A — internal):** from **P4 pin 19 = +12V** (wired
  through jumper J6 + R21 22Ω; bridge J6 — a documented, reversible
  mod). On-board 12V→5V (or 12V→3.3V) buck; the 22Ω drop is negligible
  at RP2040 currents (~25–60 mA). Do **not** draw logic power from the
  column pull-ups.
- **Power (variant B — no-open-case):** powered from outside the
  machine so it works for users who don't want to open their Osborne 1
  at all. The adapter's USB-A port pairs with a **powered USB hub** (or
  a power-tee / 5 V feed on the adapter's upstream side): the RP2040
  draws its 5 V from the hub's external supply rather than from P4.
  J6 stays factory-open; the machine is untouched. The design should
  expose a power-source jumper (P4-12V vs external 5 V) so one PCB
  serves both variants. Note: in variant B the column lines are driven
  against a machine the adapter doesn't share power with — ensure
  common ground comes through P4 pins 1/20 and the open-drain column
  drivers tolerate the unpowered-machine / powered-adapter (and vice
  versa) states.

## Host interface — P4 keyboard connector (O1A)

Later O1A "blue/grey" machines: coiled cable, 24-hole plug, only the
inner 20 pins mate. Documented pinout (O1 Technical Manual via
pinouts.ru, 4/4 corroborating reports; corrected by #48):

- 1 = GND; 2–9 = rows A4, A0, A3, A6, A2, A5, A1, A7
- 10–17 = columns D0–D7; 18 = NC; **19 = +12V (via J6+R21)**; 20 = GND

## Spec validation required BEFORE layout

- [ ] Confirm pinout against `research/osborne1/OCC1_1A2011-00_Schem_RevE.pdf`
      and continuity-check a real O1A (rows vs columns, GND, pin 19
      +12V with J6 bridged; J6/R21 present on target board revisions).
- [ ] Confirm rows are driven low one-hot via open-collector inverters,
      columns pulled up to +5V via a 3.3K resistor pack.
- [ ] Scan timing: measure stock scan rate to size the RP2040 polling
      loop / PIO snoop.

## References

- `research/osborne1/keyboard/` (pinout source + provenance)
- `docs/research-gaps.md`, issue #45 (KVM personality reuse)

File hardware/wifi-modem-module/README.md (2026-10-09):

# wifi-modem-module — severable WiFi modem (ESP32, Zimodem fork)

Hayes-compatible WiFi modem for the Osborne 1, designed as a **severable
module**: usable standalone on the MODEM (P1) port, or as part of the
interposer (where the Pico 2 W personality #21 does the same job via
memory-map snooping instead).

Tracks: #56 (extension of #21). Physical interface documented by #57.

## Definition

- **Base:** Zimodem fork targeting **ESP32** (not ESP8266) — the ESP32
  build already carries the SSH client (`INCLUDE_SSH`), SD shell, FTP,
  SLIP/PPP; ESP8266 lacks the headroom.
- **New O1-specific work on top:**
  1. **SSH as first-class transport** — keys, host verification, session
     management via the web UI; `ssh` from the O1 into a modern host.
  2. **Baud-rate buffering/correction** — decouple O1-side ACIA rate
     from the far-end link rate; makes the 2× business turbo (#55)
     usable and quietly corrects the factory 600/2400 → 650/2600 quirk.

## Host interface — MODEM port (P1, DE-9P)

**TTL levels, not RS-232** — the port feeds straight into the 6850 ACIA
(status `2A00H` / data `2A01H`), bypassing the RS-232 level shifters.

- 1 GND · 2 TXD (TTL) · 3 NC · 4 MSB (open-collector) · 5 CTS ·
  6 RXD (**bipolar input**, −0.5…−10 V = 1) · 7 +12V via R21 22Ω ·
  8 MCB (TTL, low = suppress output) · 9 RI (TTL)
- **Asymmetric levels:** TXD/MCB/RI are plain TTL, but **RXD is bipolar**
  (LM1458 + 1N5231B zener front-end) — the module must swing
  TX-toward-O1 **negative** for a clean mark. Needs in-hardware
  validation; a small charge-pump or transistor level stage is expected.
- On-board P1 header carries DE-9 pin numbers straight through
  (schematic sheet 7); 2×5 IDC orientation to be confirmed on a real
  board (same validation class as #47's P4).

## Power

+12V available on DE-9 pin 7 (via R21) — same power trick as the
keyboard adapter; on-board regulator to 3.3 V for the ESP32.

## Enclosure

The module ships with STLs for a **"COMM PAC-look" case** that fits in
the **left floppy storage pocket** — period-authentic Osborne
industrial design so it reads as original kit, not a modern dongle.
Deliverables: `case/*.stl` (top/bottom shells, LED light-pipe window)
alongside the PCB. Case design should accommodate the DE-9P pigtail and
leave the pocket usable with the keyboard closed.

## References

- `docs/o1-modem-serial.md` (authoritative pinout + levels)
- `docs/o1-memory-io-map.md` §"6850 ACIA detail"
- Upstream: https://github.com/bozimmerman/Zimodem

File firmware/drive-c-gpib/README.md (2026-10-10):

# drive-c-gpib — Drive C IEEE-488 storage personality (RP2350)

Pico-based GPIB device emulating the "Drive C" ramdisk and period
IEEE-488 hard-disk products. When this personality runs, the **original
period driver works unmodified** on the CP/M side — no new Osborne-side
code beyond usage docs (`software/README.md` no-new-code list).

Tracks: #22; protocol from #6 / `docs/drive-c-protocol.md`; OCC1 hard
disk analysis `docs/occ1-harddisk-analysis.md` (#8/#32).

## Definition

- Implement the Drive C GPIB device state machine per
  `docs/drive-c-protocol.md` (extracted from `DRIVE_C.IMD`, #33).
- Storage backing: RAM disk (persistent where possible) and/or image
  files from the library, shared with `../floppy-emulator/`.
- Reference GPIB implementation: NODISKEMU (nils-eilers) / cbmSD
  (cbmsteve.ca).
- Optionally present the OCC1 ACT-1982 winchester behavior as a second
  personality once its protocol write-up is complete (#8).

## Variant: TurboPac (Drive C + Trantor hard disk)

Per the Drive C user manual (`research/drive_c/Drive_C_Users_Manual.pdf`,
OCR stored alongside as `Drive_C_Users_Manual.ocr.txt`): **TurboPac** is
the Drive C / Trantor hard-disk system in which *Drive C becomes a
hi-speed cache buffer in front of the hard disk* — "increasing the hard
disk throughput by as much as five times."

- The hard disk attaches to the Drive C **PRINTER/HARD DISK/8088 port** —
  no mechanical modifications to the O1.
- **192K TurboPac:** all of Drive C is cache. **384K TurboPac:** 256K
  cache + 128K fixed print buffer.
- CP/M parameters differ: 8K blocks, 512 directory entries per logical
  drive, 10/20/33 MB capacities (manual §7-3).
- Detaching the hard disk returns Drive C to normal portable
  RAM-disk/print-buffer operation.

Emulation note: a TurboPac personality = this Drive C emulation **plus**
a hard-disk backing device on the downstream port, with the cache layer
implemented in firmware (or trivially: serve the hard disk image
directly and treat "cache" as a no-op — we have no rotational latency
to hide; but implement the software-visible partitioning faithfully so
the original TurboPac software behaves).

## Deliverables

- GPIB device emulation module (snoop/poke engine)
- Backing-store integration + web-UI controls
- Compatibility test notes against the original Drive C driver disk
  (`research/drive_c/`)

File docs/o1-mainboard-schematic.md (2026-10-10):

# Osborne 1 mainboard schematic — extraction, sheet index and pinouts (#64)

`research/osborne1/OCC1_1A2011-00_Schem_RevE.pdf` is the primary source for
the O1's logic board. Until now it was read by eye, page by page, in a PDF
viewer: the scan is dense, the PDF's own text layer is unusable, and the 12
pages are actually **two different drawing sets**, which is easy to get wrong.
This document is the map of that archive item: what is in it, how to read it,
and what has been extracted from it so far.

## 1. What the file actually contains

12 pages. Each page is a single 1-bit JBIG2 scan at roughly 600 dpi
(6582 × 5137 px on a 785 × 610 pt sheet) — genuinely high quality; every pin
number is legible at native resolution.

Each page *also* carries a text layer, but it is an early-1990s OCR pass and is
garbage: the disc-controller sheet's title reads `J'U~ I 'IIS IO/OO-tOOnl`.
Ignore it. (It is left in the PDF; the fresh pass in §3 is the one to search.)

The 12 pages are **two drawing sets**:

| Pages | Drawing | Rev | Sheets |
|---|---|---|---|
| 1–3 | **DISK ELECTRONICS**, DWG 1A3004-00/01 | C | 1–3 of 3 |
| 4–12 | **MAIN PC BOARD**, DWG 1A2011-00 | E | 1–9 of 9 |

This distinction matters. The disk-electronics set (1A3004) is the *drive's
own* board — read amplifier, data separator, write driver, head connectors.
The mainboard set (1A2011) is the machine this project extends. Notes in this
repo have cited "DWG 1A3004" for mainboard facts, including the floppy
connector pinout; that citation is wrong (§5).

`research/README.md` describes the split as "sheets 1–3 are the disk analog
board (DWG 1A3004), sheet 4+ the main logic board" — correct in outline; the
exact drawing numbers and sheet counts are as tabulated above.

## 2. Sheet index

Titles are the drawing's own title-block text (sheet 1 of the mainboard set
has no block title; its function is read off the circuit).

| PDF page | Drawing / sheet | Function | Devices read off the sheet |
|---|---|---|---|
| 1 | 1A3004 1/3 | Disk read electronics: head pre-amp and peak detection, ALC, head connectors P1/P2 | U9, U10, U15, U16, U18, U19, U20 |
| 2 | 1A3004 2/3 | Disk data separator: index/sector, read data, drive connector P2 | U8, U12–U22 |
| 3 | 1A3004 3/3 | Disk write driver, erase, motor control, ±12 V/+5 V rails | U1, U2, U3, U6, U11, U12, U13 |
| 4 | 1A2011 1/9 | CPU clock (4 MHz), reset, data buffers, power entry | UD11, UD13, UE3, UE20, UC7, **UC11 = 74LS161** clock counter, UA6, UA8, J5, P6 (battery) |
| 5 | 1A2011 2/9 | Address decode, ROM/RAM/I-O select, WAIT generation | UC1, UC2, UD1, UD2, UD3, UD9, UD12, UE3, Q1/Q2 (reset timing) |
| 6 | 1A2011 3/9 | **CPU**: Z80-A, monitor EPROM, address latches | **UC11 = Z80-A**, **UD11 = 2732**, UD4, UD6–UD10, UE6, UE10, UE11, UA4 |
| 7 | 1A2011 4/9 | **RAM** array, address multiplex/buffer, **character generator ROM and its serialiser** | **UA15 = 2716** char-gen ROM and **UA14 = 74166** pixel serialiser (§4a), **UA18 = 74LS273** character latch (drives UA15 `A0–A6`), UA17/UA18 and the UA23–UA48 array (2114/2112 static RAMs per sheet 1's parts list), UE13–UE15 (74LS244), UE16–UE18 (74LS153), UD16 (74LS374) |
| 8 | 1A2011 5/9 | **VIDEO**: PIA, scan counters, video timing, brightness/contrast | **UC15 = 6821**, **UD17/UD18 = 74LS161** scan-line counters (preset from PIA `PB0–PB3`, outputs `SCAN0–SCAN3` → UA15 on sheet 4/9), UC16–UC21 (74166/74165), UA11–UA13, UB14/UB15 (74LS161), UE20–UE24 (7406), R40 (brightness), R44 (contrast). **UA14, UA15 and UA18 are on sheet 4/9, not here** — §4a. The rest of this row is still the first pass (§3) |
| 9 | 1A2011 6/9 | IEEE-488 interface (P3): PIA + open-collector bus drivers | **UC7 = 6821**, UD1 (74LS30), UD5 (74LS32), UD6/UD8–UD11 (7406), UE6/UE10 (74LS04), RN7/RN11–RN16 (3.3 K pull-ups) |
| 10 | 1A2011 7/9 | **SERIAL I/O**: ACIA + RS-232 level shifting, modem and CRT connectors | **UC4 = 6850**, UC14 (6551), UD1, UE1 (555), UE2 (1488), UE3 (1489), P1 (MODEM), P2 (9"/12" RS-232 CRT) |
| 11 | 1A2011 8/9 | **KEYBOARD**: row/column matrix, column drivers | UE12 (81LS95), UE13/UE14 (74LS05), RN10 (1.5 K), P4 (KEYBOARD) |
| 12 | 1A2011 9/9 | **DISC CONTROLLER** + the 34-pin floppy header | **UB7 = MB8877**, U7, U8, U9, U10 (7408/7406), U15 (74LS161), UD6 (74LS74), RN2 (150 Ω terminator), **P8** |

Sheets 4–12 are numbered 1–9 of 9 in their title blocks; the mainboard set is
complete in this scan.

> **Read the device lists at native resolution before citing them.** The
> *functions* in the last column are reliable; the part numbers came from a
> whole-sheet pass and at least two are known wrong (§3). `UC11` in particular
> appears twice — as the Z80 (sheet 3/9, verified at 600 dpi) and as a 74LS161
> (sheet 1/9, overview pass); only one can be right.

## 3. How to read a sheet

Whole-sheet views are useless — scale a 6582 px sheet onto a screen and the pin
numbers vanish. Read it one region at a time at native resolution. Two tools:

```
# browse: an overview plus a grid of native-resolution tiles for every sheet
tools/schematic_atlas.sh research/osborne1/OCC1_1A2011-00_Schem_RevE.pdf
#   -> build/atlas/index.md          tile map: page -> tile -> pixel box
#   -> build/atlas/sheet-05/r1c0.png native-res tiles you can just open

# then re-render any region exactly, once the index says where it is
tools/schematic_render.sh research/osborne1/OCC1_1A2011-00_Schem_RevE.pdf /tmp/s \
    --sheet 5 --dpi 600 --crop 2600 1250 1450 1050
```

`tools/schematic_atlas.sh` writes into `build/atlas/` — gitignored, because the
atlas is regenerable and the *coordinates* are the durable part. Its index maps
every tile to the pixel box it covers, so a region found by eye once can be
re-rendered exactly later. `--info` on the render tool prints the sheet size in
pixels at a given dpi. Both need poppler (`brew install poppler`), which
`tools/ocr_pdf.sh` already depends on.

**Read part numbers at native resolution, never from an overview.** At 300 dpi
`LS00` and `LS08` are indistinguishable, and so are `LS138` and `LS139`. The
first pass over this scan was done from whole-sheet views and got both of those
wrong on sheet 2: at 600 dpi it plainly reads **`UC1 LS00`** (quad NAND) and
**`UB1 LS139`** (dual 2-to-4 decoder — its pin numbers 15/14/13 for
enable/A/B and 12/11/10/9 for Y0–Y3 are exactly the second half of a '139).
The §2 device lists came from that first pass: treat the *functions* as
reliable and the part numbers as needing a native-resolution check before
anything is built on them. One conflict is already visible in them — `UC11`
is listed as both the Z80 (sheet 3/9, read at 600 dpi, and it matches a
standard DIP-40) and a 74LS161 (sheet 1/9, overview pass). The Z80 is the
verified one.

`research/osborne1/OCC1_1A2011-00_Schem_RevE.ocr.txt` is a fresh OCR pass (per
the `research/README.md` OCR convention) so the scan is greppable for component
references. It is useful for *finding* things — "which sheet has the MB8877?" —
and not trustworthy for pin-level detail. Everything in §4 and §5 was read by
eye at 600–1200 dpi instead.

`research/osborne1/OCC1_1A2011-00_Schem_RevE.ocr.txt` is a fresh OCR pass (per
the `research/README.md` OCR convention) so the scan is greppable for component
references. It is useful for *finding* things — "which sheet has the MB8877?" —
and not trustworthy for pin-level detail. Everything in §4 and §5 was read by
eye at 600–1200 dpi instead.

## 4. Extracted: the Z80 socket (UC11) is a standard Z80 DIP-40

Read from sheet 3 of 9 (PDF page 6) at 600 dpi. The symbol is drawn as
**UC11, Z80-A**.

| Pin | Signal | Pin | Signal | Pin | Signal | Pin | Signal |
|---|---|---|---|---|---|---|---|
| 1 | A11 | 11 | +5 V | 21 | RD | 31 | A1 |
| 2 | A12 | 12 | D2 | 22 | WR | 32 | A2 |
| 3 | A13 | 13 | D7 | 23 | BUSAK | 33 | A3 |
| 4 | A14 | 14 | D0 | 24 | WAIT | 34 | A4 |
| 5 | A15 | 15 | D1 | 25 | BUSRQ | 35 | A5 |
| 6 | CLK | 16 | INT | 26 | RESET | 36 | A6 |
| 7 | D4 | 17 | NMI | 27 | M1 | 37 | A7 |
| 8 | D3 | 18 | HALT | 28 | RFSH | 38 | A8 |
| 9 | D5 | 19 | MREQ | 29 | GND | 39 | A9 |
| 10 | D6 | 20 | IORQ | 30 | A0 | 40 | A10 |

Read directly off the sheet: A1 = 31 … A10 = 40, A11 = 1 … A15 = 5, A0 = 30,
D0 = 14, D1 = 15, D2 = 12, D3 = 8, MREQ = 19, RFSH = 28, IORQ = 20, WR = 22,
M1 = 27, RD = 21, +5 V = 11, GND = 29, BUSRQ = 25, NMI = 17. The unread rows
are the standard Zilog DIP-40 pinout, consistent with every pin that was read.

**This closes the Z80 half of `docs/research-gaps.md` gap #3 from the primary
source.** The O1's socket is wired as a plain Z80 DIP-40, so any board that
mates with it can use the datasheet pinout — which is what
`tools/check_schematics.py` asserts and what the interposer generators were
corrected to use (#62). It also corroborates that fix: the generators had the
pin table off by one across all 40 pins and were corrected to +5 V = 11 /
GND = 29 / A0 = 30 from the databook — the sheet says exactly that.

**Correction — both halves of that paragraph were wrong.** It read *"the
char-gen socket (UA15) half of gap #3 is still open. UA15 is a 74S244 on sheet
5 of 9."* UA15 is neither a 74S244 nor on sheet 5, and that mis-direction is
why #24's second tap point sat unresolved. UA15 is the **2716
character-generator ROM on sheet 4 of 9** (PDF page 7, title block `RAM`).
Read it at 1200 dpi — §4a.

## 4a. Extracted: the character-generator ROM socket (UA15) — gap #3 closed

Found at 600 dpi on sheet 4 of 9 (PDF page 7), read at 1200 dpi. The socket is
`UA15`, silkscreened **2716**, drawn with the address pins on the left and the
data pins on the right. The pinout is the **standard Intel 2716**, pin for pin:

| Pin | Signal | Where it comes from / goes |
|---|---|---|
| 1–8 | A7–A0 | `A0–A6` = character code (7 bits, 128 chars) from **UA18 (74LS273)**; `A7` = `SCAN0` |
| 9, 10, 11, 13–17 | O0–O7 | the pixel row, to the parallel inputs of **UA14 (74166)** |
| 12 | GND | **bussed with pins 18 and 20, then to ground** |
| 18 | `/CE` | **grounded** — the ROM is permanently selected |
| 19 | A10 | `SCAN3` |
| 20 | `/OE` | **grounded** — the ROM always drives its outputs |
| 21 | (A11 on a 2732) | **strapped to +5 V** |
| 22 | A9 | `SCAN2` |
| 23 | A8 | `SCAN1` |
| 24 | Vcc | +5 V |

### Address map

`SCAN0–SCAN3` arrive as labelled nets (`5C1 — SCANn`): they are the outputs of
the scan-line counters **UD17/UD18 (74LS161) on sheet 5 of 9**, which the video
PIA `UC15` presets from `PB0–PB3`. With `A7 = SCAN0` and the character code on
`A0–A6`, the address is

```
address = (scan << 7) | char       scan = {SCAN3,SCAN2,SCAN1,SCAN0}
        = 128 characters x 16 scan rows = 2048 bytes = exactly one 2716
```

The displayed cell is 8 wide x 10 high (24 rows x 10 = the 240-line video all
three MAME drivers produce), so scan rows 10–15 of every character are stored
but never shown.

### Output path — the assumed one was wrong too

`O0–O7` do **not** leave the sheet as eight parallel `CHAR0–CHAR7` lines. They
drive the parallel inputs of **UA14 (74166)**, an 8-bit shift register on the
same sheet, which serialises the pixel row and exports it as the single net
`VIDEO → 5D4` to the video sheet. UA14 is clocked by `DOT CLK` (from sheet 1/9)
and its `SI` and `/CE` are wired together — the usual trick that shifts in 1s
as the inter-character blank. The video sheet's own `4D1 → VIDEO` reference
(sheet 4, zone D1 — where UA14 sits) corroborates the direction.

This matters to #24: the char-gen socket is a **font source, not a pixel bus**.
Reading the font through the tap is enough — the pixels are re-rendered from
shadow VRAM.

### What the strapping means for a tap

`/CE` (18) and `/OE` (20) are **hard-grounded on the mainboard**, so the ROM is
always selected and always driving `O0–O7`. A socket tap may buffer and *read*
those pins freely, but it cannot tristate the ROM to inject its own font
without intercepting pins 18 and 20 between socket and ROM. Any future
"supply your own font" mode needs that interception, and the pin-21 strap held
at +5 V (the socket is wired 2732-style, so a 4 KiB part would fit physically).

## 5. Extracted: the P8 34-pin floppy connector — and a correction

Read from sheet 9 of 9 (PDF page 12, DISC CONTROLLER) at 600–1200 dpi. Every
pin label on the P8 symbol was read individually:

| Pin | Signal | Pin | Signal | Pin | Signal | Pin | Signal |
|---|---|---|---|---|---|---|---|
| 1 | GND | 10 | DRV SEL 1 | 19 | GND | 28 | WRT PROT |
| 2 | GND | 11 | +12 V | 20 | STEP | 29 | GND |
| 3 | GND | 12 | DRV SEL 2 | 21 | +5 V | 30 | READ |
| **4** | **TG43** | 13 | +12 V | 22 | WRT DATA | 31 | GND |
| 5 | GND | 14 | *(not drawn)* | 23 | +5 V | 32 | SIDE SEL |
| **6** | **EARLY** | 15 | +12 V | 24 | WRT GATE | 33 | GND |
| 7 | *(not drawn)* | 16 | CLOCK (4 MHz) | 25 | +5 V | 34 | LATE |
| 8 | INDEX | 17 | +12 V | 26 | TRACK 00 | | |
| 9 | GND | 18 | DIR | 27 | GND | | |

**Pins 4 and 6 are not ground.** Pin 4 is **TG43** and pin 6 is **EARLY**; both
are driven by the FDC (UB7) through 7406 open-collector buffers (U9/U10) and
routed to the connector. Pins 7 and 14 are not drawn on P8 at all.

This contradicted `docs/floppy-adapter-design.md` §2, which listed
`1,2,3,4,5,6,7,9,19,27,29,31,33` as GND "per DWG 1A3004". Two things were
wrong with that:

- **The citation.** DWG 1A3004 is the *disk electronics* drawing (§1). P8 is on
  the mainboard drawing, 1A2011-00 sheet 9. The right source was being
  overlooked and the wrong one cited.
- **The content.** The transcription that went into the generator and the doc
  came from the archived Wayne Visser adapter
  (`research/osborne1/floppy-adapter/FloppyAdapter.sch`), which ties pins
  4, 6 and 7 to GND. That is safe for a passive Gotek-only adapter — a 7406
  open-collector output pulled low is not damaged and a Gotek ignores TG43 and
  EARLY — but it is not what the machine does, and this adapter switches the
  OEM cable through to the physical drives, so it must not clamp two live
  signals.

**Fixed** in `hardware/floppy-adapter/gen_floppy_adapter_sch.py`: pins 4 and 6
are now `FLP_TG43` / `FLP_EARLY` and pass straight through J1 → J2 like every
other signal. Grounding TG43 is not merely untidy: it is the FDC's track > 43
output, which is the drive's *write-current-reduce* input on 96 tpi drives, so
clamping it low would assert reduced write current permanently.

### The 2-versus-7 discrepancy (harmless, recorded for completeness)

DWG 1A3004 sheet 1 shows connector **P2** — the drive end of the same ribbon
cable — with `GND = 1,3,5,7,9,19,27,29,31,33` and `CASE = 32`, i.e. **pin 7**
grounded and pin 2 not listed. Mainboard P8 shows **pin 2** grounded and pin 7
not drawn. The digits were checked at 1200 dpi against the `27`/`29`/`31`/`33`
glyphs in the same font to rule out a misread, so the two drawings really do
disagree.

It does not matter electrically: neither pin carries a driven signal on the O1
(every signal the interface has is accounted for on other pins), so both are
safe to tie to ground. The adapter ties both, which is correct whichever
drawing is right.

## 6. Running it as a machine

A scan cannot be "run": there is no vector netlist in it, only pixels, so there
is nothing to hand to a simulator. Reading a schematic and *executing* the
machine it documents are two different jobs. The machine itself, however, runs
very well — and it is the better oracle anyway, because it exercises the design
rather than our reading of it.

MAME has an `osborne1` driver, and this machine already has everything needed:

- MAME (`brew install mame`)
- the O1 ROMs in `~/Documents/Osborne1/roms/`, including
  `3a10082-00rev-e.ud11` — the **Rev E** monitor ROM, i.e. the same board
  revision as this schematic (`ROM_DEFAULT_BIOS("ver144")` in MAME's driver)
- a headless harness in the sibling project:
  <https://github.com/Myrcurial/o1prsnt/tree/main/utilities/headless-testing-harness>

That harness is a small Lua library MAME runs via `-autoboot_script`. It
injects keystrokes through MAME's natural-keyboard device and reads the
**screen straight out of video RAM at `0xF000`** (128 bytes/row × 32 rows), so a
test asserts on what the machine is *displaying*. Run it with:

```
cd .../headless-testing-harness
O1_ROMPATH=/tmp/o1roms O1_RUNDIR=/tmp \
  ./run-test.sh mytest.lua ~/Documents/Osborne1/floppies/<image>.imd 90
```

`O1_RUNDIR` keeps MAME's `cfg/`/`snap/` litter out of the repo. `O1_ROMPATH`
must point at a directory laid out the way MAME expects — `rompath/osborne1/`
or `rompath/osborne1.zip` — not a directory of loose ROM files:

```
mkdir -p /tmp/o1roms/osborne1 && cp ~/Documents/Osborne1/roms/* /tmp/o1roms/osborne1/
```

**Verified working, 2026-10-10.** A three-line script (`H.boot_cpm()`,
`H.dump()`, `H.finish()`) booted CP/M headless and reached `A>` in 9 emulated
seconds with this on screen, read out of VRAM:

```
PIP     .COM   8k        Disk A:  1K blocks
SETUP   .COM   6k        Size=  185K, 13 Files, Used=  140K, Space=   45K
SYSGEN  .COM   2k        A>
XDIR    .COM   3k        Loading CP/M
XREF    .COM   7k        Extended Directory version 3.5
```

With `-nothrottle` the 4 MHz Z80 runs at ~20–25× real time, and because MAME
counts *emulated* seconds the timings a test measures are valid 4 MHz Z80
timings. That is what makes this useful for #29: it is a machine-level oracle
for the memory map, the I/O decode and bus timing, available before any
hardware exists.

## 7. Cross-checks against the running machine

The emulator is not just a way to run the O1; it independently confirms parts
of the extraction. MAME's driver
(`src/mame/osborne/osborne1.cpp`) encodes the hardware, and the running machine
agrees with `docs/o1-memory-io-map.md`:

- **Banks.** Driver memory map: `0x0000–0x3fff` a ROM view whose low half is the
  4 KB monitor ROM `.mirror(0x1000)` and whose `0x2000–0x2fff` window is the I/O
  area `.mirror(0x1000)`; `0xf000–0xffff` an attribute-RAM view. That is exactly
  §2 of the map doc (ROM 0000–0FFF mirrored into 1000–1FFF, I/O 2000–2FFF
  mirrored into 3000–3FFF, video at F000).
- **Bank switching.** Driver I/O map is `map.global_mask(0x03)` with a single
  `0x00–0x03` write handler, dispatching exactly as §4 of the map doc says:
  0 → select ROM+I/O bank, 1 → back to main RAM, 2 → map attribute RAM at F000,
  3 → unmap it. The doc's four I/O writes are the four driver cases.
- **I/O decode.** The driver's window tests — floppy `(off & 0x900) == 0x100`,
  IEEE-488 `(off & 0x900) == 0x900`, keyboard `(off & 0xa00) == 0x200`,
  serial `(off & 0xa00) == 0xa00`, video PIA `(off & 0xc00) == 0xc00`,
  ScreenPac `(off & 0xc00) == 0x400` — match the doc's `2100/2900/2200/2A00/2C00`
  bases and show the decode is *partial*: peripherals alias widely and their
  outputs are ANDed together when more than one responds, which is why the doc
  calls it a "memory-mapped I/O window" rather than a decoded bus.
- **Floppy controller variant (gap #11).** The doc says "Fujitsu MB8877 ≡
  WD1793 (UB7)". MAME's driver carries the same uncertainty as a source
  comment: *"Schematics specify a WD1793 floppy controller, but we're using the
  Fujitsu equivalent MB8877 here. Is it known that the original machines used
  one or [the other]?"* Two independent readings of the same drawing, same
  conclusion — the schematic's symbol is a WD1793-compatible part, the fitted
  chip may be either.
- **Rev E alignment.** The BIOS MAME loads by default for this machine is
  `3a10082-00rev-e.ud11` (BIOS 1.44), the Rev E monitor ROM — so the emulator,
  the archived ROM and this schematic are the same board revision.

### 7a. Asking the machine directly — `tools/check_o1_map.sh`

Reading the driver is still reading someone else's model of the hardware.
`tools/check_o1_map.sh` boots the machine headlessly and interrogates it over
its own bus, then asserts what `docs/o1-memory-io-map.md` claims. RAM is told
from ROM by writing back the complement of the byte that was there and restoring
it — a RAM cell follows, a ROM cell does not. Eleven checks, all passing:

```
$ tools/check_o1_map.sh
program space: mask=0xFFFF width=8   io space: mask=0x0003 width=8
booted to A> after 9.0 emulated seconds
PASS  B1    CP/M reaches the A> prompt in the emulated machine
PASS  C1    0xF000 behaves as RAM (video RAM is in the RAM bank)
PASS  C2    0x4000-0xEFFF is RAM (176/176 pages)
PASS  C3    I/O write to port 0x00 selects the ROM bank
PASS  C4    I/O write to port 0x01 selects the RAM bank
PASS  C5    the data byte on a bank-switch write is ignored
PASS  C6    I/O ports 0x04/0x05 alias 0x00/0x01 (only A0/A1 decoded)
PASS  C10   the selected bank is re-derived on instruction fetch, not latched
PASS  C7    I/O port 0x02 maps the 1-bit bank-3 plane over 0xF000
PASS  C8    ROM at 0x0000-0x0FFF mirrors 0x1000-0x1FFF
PASS  C9    nominally-dead bank-2 addresses alias real devices (sloppy decode)
== 11 passed, 0 failed ==
```

The page maps it prints are §2 of the map doc in machine form: in bank 2,
ROM across `0000-1FFF`, devices across `2000-3FFF`, RAM from `4000` up; in
bank 1, RAM across all 64K. Four things it established that the documents do
not currently say:

- **The bank latch is real but does not persist.** `OUT (1),A` puts the machine
  in the RAM bank immediately, and 10 ms of emulated time later it is back in
  the ROM bank — the bank is re-derived on every instruction fetch from the
  M1/IRQACK flip-flops, and the video PIA interrupts at 60 Hz. The map doc §4
  says the selection is "qualified by M1 and IRQ-acknowledge conditions"; this
  is what that means in practice, and it is why a naive peek at `0x0000` while
  CP/M runs returns ROM bytes. Interposer logic that assumes a static bank state
  is wrong.
- **The I/O space decodes two address bits** (`io space: mask=0x0003`), so all
  256 Z80 I/O ports are `0x00-0x03` repeated 64 times — the map doc's "only the
  two low address bits are decoded", measured.
- **The ROM is live while CP/M runs.** Sampling the Z80's PC during a working
  `DIR` finds it inside the ROM (`0x0377-0x0387`, `0x0EF7-0x0EFC`) as well as in
  RAM, so the ROM is paged in and out during normal operation; "the ROM is only
  used at boot" is not true.
- **Bank-2 aliasing is measurable, not theoretical.** `0x2500` reads the floppy
  register that `0x2100` reads, `0x2601` the keyboard row that `0x2201` reads,
  `0x2c04` the video PIA port that `0x2c00` reads. Addresses that decode to two
  devices at once return the AND of both — `0x2301` is keyboard *and* floppy,
  `0x2f00` is video PIA *and* serial ACIA.

## 8. Can the schematic be turned into something runnable?

**Automatically, no — and that is a property of the file, not of effort.** Every
page is a single 1-bit JBIG2 raster at 600 dpi:

```
$ pdfimages -list research/osborne1/OCC1_1A2011-00_Schem_RevE.pdf
page   num  type   width height color comp bpc  enc  x-ppi y-ppi size
   5     0 image    6582  5137  gray    1   1  jbig2  600   600 69.1K
   6     0 image    6592  5150  gray    1   1  jbig2  600   600 86.2K
   ...
```

No vector data at all — no lines, no symbols, no netlist, nothing to walk. The
only text object is a `HiddenHorzOCR` layer from an early-1990s pass that
renders a sheet title as `J'U~ I 'IIS IO/OO-tOOnl`. Whatever "extraction" means
here, it starts from pixels.

**Re-OCRing the labels does not work either.** Tesseract on native-resolution
tiles mangles exactly the tokens that matter — `UC1 LS139` came back as
`uct LSiss`, `LS32` as `L$3e2`, `LS00` as `tS0e` — and a 1200 dpi pass returned
nothing usable at all. A harvested label index would mislead more than it
helped, so the reading stays manual and §3 is about making that fast and
accurate.

**The honest route to a netlist is manual capture**, and the only part worth
capturing is the discrete glue. Most of these sheets are Z80, DRAM, FDCs and
PIAs whose behaviour is already known; the unknowns are the small-scale logic —
above all the **wait-state generator on sheet 2/9** (`UC1`, `UC2`, `UD1`–`UD3`,
`UD9`, `UD12`, `UB1`, `UB7`, `UB12`, `UE1`–`UE3`, `UA4`, `UA5`, Q1/Q2), which is
what MAME does *not* model and what issue #29 needs. Capturing that one sheet
into KiCad gets ERC and netlist checking from the tooling `hardware/` already
has; capturing it into Verilog additionally lets it be *run*.

**What "run it as a machine" can mean, in order of fidelity:**

| Approach | Status | What it validates |
|---|---|---|
| MAME, booting CP/M headless | works (§6) | the machine, behaviourally |
| `tools/check_o1_map.sh` asserting the documented map | works (§7a) | our *reading* of the map, against the machine |
| Hand-captured glue logic as Verilog, simulated | not started | the schematic itself — the wait states MAME omits |
| The above, driven by bus traces logged from MAME | not started | the same, against real Z80 traffic |
| Whole-board gate-level simulation | not sensible | MAME already is the machine |

The last two rows are a design, not a wish: MAME's Lua can log every read and
write through an address space, so a captured decode/wait model can be driven
with real traffic and its chip-select and `WAIT` outputs compared against what
the machine actually did. A disagreement is then either a misreading of the
schematic or a MAME shortcut, and both are worth knowing. It is a multi-hour
careful job, and doing it badly would produce a wrong document — the failure
mode this whole exercise exists to avoid.

## 9. What is not extracted yet

- **What the `CHAR0–CHAR7` nets carry.** They cross to the video sheet carrying
  a `4C1` reference (sheet 4, zone C1 — the RAM array), so they are *not* the
  char-gen ROM's outputs (§4a). Presumably the character-code bus out of video
  RAM; not yet read.
- **What UC16–UC21 do on the video sheet.** The pixel row is serialised by UA14
  on sheet 4 (§4a), so the six shift registers §2 lists on sheet 5 need a
  second look before #24 relies on the phrase "character shifters".
- **Sheet 4 (1A2011 1/9) parts list.** That sheet carries the board's
  REF/DESCRIPTION table. It is partly legible in the scan and is the fastest
  route to a full IC inventory.
- **Per-sheet component inventories** for sheets 4, 5, 7 and 8, which §2 lists
  only from a first pass — see the part-number caution in §3.
- **The wait-state generator (sheet 2/9)** as a captured, simulatable model
  (§8).
- **A net-level extraction** of the whole board — not achievable from this scan
  without manual capture.

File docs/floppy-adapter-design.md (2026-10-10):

# Floppy adapter — switchable Gotek / physical-drive daughter card

Design spec for issue **#62**. Tracks the floppy interposer personality (#20)
and G2 multi-format support (#30). Derived from
`research/osborne1/floppy-adapter/` (Wayne Visser passive adapter + provenance),
Richard Loxley's Osborne Restoration parts 5 and 12–15, and
`hardware/floppy-adapter/README.md`.

> Status: **design settled 2026-10-10; Rev A schematic captured.**
> Open questions are resolved in §8 with the evidence behind each decision.
> Rev A KiCad capture lives in `hardware/floppy-adapter/`
> (`floppy-adapter.kicad_sch`, generated by `gen_floppy_adapter_sch.py`).

## 1. Purpose

Let the user choose, from a front-panel switch, whether the **drive A** position
is served by the physical drive or by a **Gotek** (FlashFloppy) emulator, with
**drive B always present** in both modes. The card sits between the O1
mainboard/DD-board floppy header and the OEM floppy cable; nothing in the machine
or its cable is cut.

Prior art, deliberately **not** copied:

- Wayne Visser's `Osborne1FloppyAdapter` is a **passive** tap — it puts a Gotek
  on the bus alongside the physical drives and switches nothing. We keep its
  pin/rail mapping as the O1 interface reference.
- Richard Loxley's hand-wired build (parts 12–15) proved the concept but needed a
  DPDT switch + a 5 V relay soldered onto the Gotek, plus hand-cut Dupont cable.
  This design moves all of that onto a PCB at the connector end of the cable.

## 2. Osborne 1 floppy interface (34-pin, Shugart-like)

The O1 uses a Shugart-like 34-pin interface, but with **+5 V and +12 V routed to
the drives over otherwise-unused cable pins** — there are no separate drive power
connectors. The pin functions below were first transcribed from the archived
Wayne Visser adapter (`research/osborne1/floppy-adapter/FloppyAdapter.sch`); they
agree with Loxley's signal audit and the standard Shugart ordering for the shared
signals. **Re-read from the O1 mainboard schematic itself, 2026-10-10** — DWG
1A2011-00 Rev E, sheet 9 of 9 (DISC CONTROLLER), the P8 symbol — see §8.2. That
reading corrected two pins and the GND row.

| Pin(s) | Signal | Notes |
|---|---|---|
| 1,2,3,5,9,19,27,29,31,33 | GND | pin 7 is GND on the drive-end drawing instead; neither 2 nor 7 is a driven signal, so both are tied to GND here |
| **4** | **TG43** | **not GND** (corrected 2026-10-10) — FDC-driven; the drive's write-current-reduce input on 96 tpi drives |
| **6** | **EARLY** | **not GND** (corrected 2026-10-10) — FDC-driven |
| 7 | GND (drive-end drawing) | see note on pin 1 row |
| 8 | INDEX | |
| 10 | DS-A (drive select A) | **the switched line** — Gotek replaces drive A |
| 11,13,15,17 | +12 V | power-over-cable (physical drives) |
| 12 | DS-B (drive select B) | not switched — drive B stays present |
| 14 | *(not drawn on P8)* | |
| 16 | 4 MHz | O1-specific clock; not used by Gotek |
| 18 | DIRECTION | |
| 20 | STEP | |
| 21,23,25 | +5 V | power-over-cable (physical drives; tapped for Gotek) |
| 22 | WRITE DATA | |
| 24 | WRITE GATE | |
| 26 | TRACK 0 | |
| 28 | WRITE PROTECT | |
| 30 | READ DATA | |
| 32 | SIDE SELECT | |
| 34 | LATE | |

Pins 4 and 6 carry live FDC outputs, so the card **passes them straight through
J1 → J2** rather than grounding them. The earlier transcription (from the Visser
adapter) tied 2, 4, 6 and 7 to GND; that is harmless for a Gotek-only adapter,
but this card switches the OEM cable through to the physical drives, and
clamping TG43 low would assert reduced write current permanently.
| 34 | LATE | O1-specific |

The Gotek needs only the static/step/data lines plus its drive-select (Loxley's
11-line audit). The card routes that subset to the Gotek header and leaves 4 MHz
and the spare power pins off it.
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

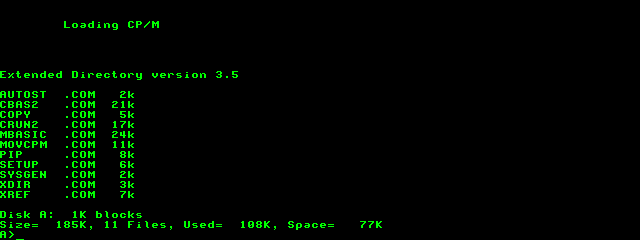
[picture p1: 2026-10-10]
docs/mame-screens/osborne1nv-80col.png

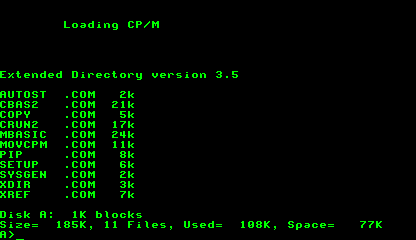
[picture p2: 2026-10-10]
docs/mame-screens/ozrom-1e-52col.png

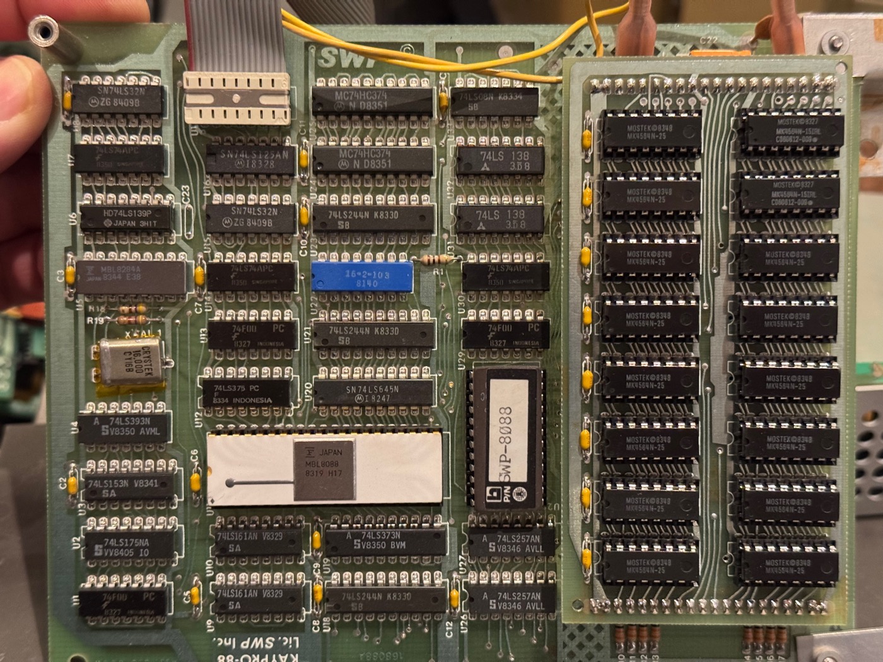
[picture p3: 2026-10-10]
site/assets/swp-8088.jpeg

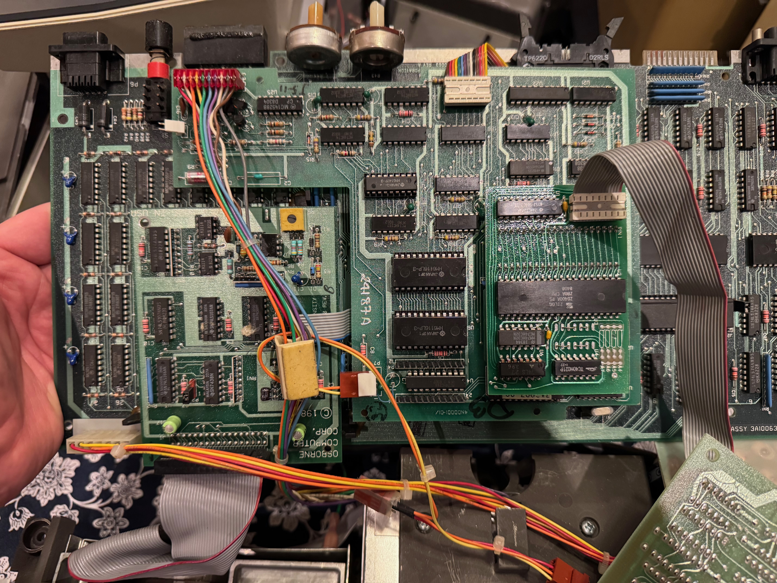
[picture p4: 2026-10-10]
site/assets/stack-of-boards-full.jpeg

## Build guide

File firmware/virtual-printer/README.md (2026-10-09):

# virtual-printer — Virtual Epson MX-80, capture → PDF on-device (RP2350)

The **Virtual Epson MX-80**: captures Centronics-mode output on the
IEEE-488 port and renders it to PDF emulating a period 9-pin Epson
MX-80. PDFs are served from the interposer's HTTP interface — no
external computer required.

Tracks: #19. References archived in `research/mx80/`.

## Definition

- **Capture:** snoop the IEEE-488/Centronics write path, buffer the
  byte stream per print job.
- **Renderer (runs on the Pico 2 W):** emulate the 9-pin printhead into
  a 1-bit raster page buffer — at ~60×72 DPI a full page is ~50 KB,
  well within the RP2350's 520 KB SRAM. Then wrap the bitmap in a
  minimal PDF (plain objects + xref, no compression required).
  - Supported: two fonts, double-wide, italics, bold, underline.
  - **Not supported:** graphics printout (ESC K/L) — period-documented
    limitation of this emulation.
- Written as **portable C** so the same renderer also builds as a host
  tool for development and golden-file testing.
- **Serving:** finished jobs appear in the web UI (`../web-ui/`) as
  downloadable PDFs.

## Page presentation: tractor-feed paper

Not photographic realism — just the hint that you might need to tear
the sides off each page on your screen. Ship a small embedded image
asset (or procedurally-drawn strip) of **fanfold tractor-feed edges**:
perforated margins with sprocket holes along left/right edges, optional
per-page perforation line. Rendered as the PDF page background with the
rasterized print overlaid, so WordStar output looks like it came off
the platen. Keep the asset tiny (1-bit, a few KB) and the effect
subtle; a config toggle in the web UI turns it off for clean PDFs.

## Glyph sources (research/mx80/)

- **Source of truth:** MX-80 operation manual, Appendix 4 character
  font tables (PDF p. 97+) — how glyphs fit the 6×9 matrix.
- **Cross-check:** Michael Walden's MX-80 font pack (CC BY-NC-SA 4.0).

## Open questions

- **Double-strike / density modes:** the Walden font renders ~2× wider
  than expected — hypothesis is a draft vs. high-quality mode where the
  head prints each character twice with a half-pin-width offset for
  density. Resolve against the manual's ESC density codes and Appendix 4
  column counts (and ideally a scan of real output in both modes)
  before locking glyph metrics. (More in `research/mx80/README.md`.)
- Exact ESC subset boundary: which control codes beyond the supported
  feature list get acknowledged-and-ignored vs. treated as errors.

## Deliverables

- Capture module (snoop/poke engine)
- `mx80/` portable renderer library (device + host builds)
- Glyph data transcribed from the manual's Appendix 4
- Tractor-feed page asset + web-UI toggle
- Test corpus: period CP/M print output (WordStar etc.)

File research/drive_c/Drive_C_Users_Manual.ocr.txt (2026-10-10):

Drive C

User's Manual
Drive C USER'S MANUAL
for Osborne 1 Computers

Drive C: 1690 65th Street Emeryvilte, CA 94608
(415) 652-3222 Telex: 75632QDRIVEC UD) _Easylink: 62533500
SECOND EDITION, June 1984

This User's Manual and the software programs it describes are:
Copyright (C) 1984

Drive C:, a joint venture
All Rights Reserved.

The following trademarks used in this manual are the property of these companies:

Drive C Drive C:
TurboPac Drive C:

QuickPac Drive C:

BackPac Drive C:

Trantor Trantor Systems Limited
Osborne 1 Osborne Computer Corp.
Executive Osborne Computer Corp.
cP/M Digital Research Inc.
WordStar MicroPro International Corp.
SuperCalc Sorcim, Inc.

dBASE IL Ashton-Tate, Inc.

ai
Thank You!

We thank you for becoming a Drive C owner.
We've made every effort to make your Drive C simple to learn and easy to use.

This manual is designed to help you learn how to use the many features of your
Drive C as well as how to derive the maximum benefits from your Osborne 1.

Most new computer owners have difficulty working with the apparent complexity of
their computer. It's simple if you take it one step at a time.

The Drive C User's Manual provides step-by-step instructions for installing and
using Drive C. Each step includes an actual practice exercise with your Drive C.

While it may appear that there are a lot of exercises, they take just a few minutes
to do. Just follow the step-by-step instructions and you'll have your Drive C up
and running very quickly.

You'll soon agree the easiest way to learn to use Drive C is simply by using it.

#h*R SPECIAL THANKS ****

This manual and the new Drive C software package were based largely on advice given
us by Drive C owners. We're very proud of all our Drive C products and we hope you
will continue to give us advice and feedback. Thanks to all of you who helped.

aii
2-1
2-2
2-3
2-4
2-5
2-6
2-7
2-8
2-9
2-10
2-11
2-12
2-13

SECTION 3

SECTION 5

Table of Contents

HOW TO USE THIS MANUAL PAGE

What's inside and where to find it......+,
Symbols and conventions used in this manual
Drive C featuresS.-+sereeeeecerececreereres

GETTING STARTED

Mechanical installation of Drive C....
Removing the Drive C unit.
Using display screens with Drive C.
Making your copy of the Drive C software.
For Users of Rev 1.2 Ols
Testing your Drive C installation
Trouble~shooting the Drive C installation.......
Installing Drive C with your printer
Trouble-shooting the parallel printer installation.
Putting your CP/M onto your DC USER Disk.
Testing your printer operation..
Trouble-shooting your printer, Part 2......+
Quick checklist of Drive C installation...

FITTING Drive C TO YOUR NEEDS

The automatic approach.....ss.e0+
The manual approach........
Using it both ways..

40

CP/M TUTORIAL

Operating systems. .secececsccccccccccscccccencecessreneees
Formatting disks+..sseesseseres Corre
Putting CP/M on disks using SYSGEN.....
Files and DIR.
XDIR.
Renaming files
Copying files with PIP.
Erasing files......+
cP/M Error messages.

LEARNING Drive C SKILLS

USING THE RAM DISK

5-1
5-2
5-3
5-4
3-35
5-6
5-7
5-8
5-9

Getting ready. 100 63
Installing the RAM-disk 00 66
Copying files onto the RAM-disk. 67
Saving files from the RAM-disk to floppy. 68
Installing the RAM-disk as drive A:..... +70

Installing Drive C with different drive names 1
Drive C and the RESET button....+sseesee
Renaming the RAM-disk after installation.
Running WS on Drive C - doing it manually...

iv
Table of Contents

USING THE PRINT BUFFER

5-10
5-11
5-12
5-13
5-14

Print Buffer operation....
Installing the Print Buffer.
The Fixed Print Buffer.
The Dynamic Print Buffer.
Using the Dynamic Print Buffer....

USING THE Drive C UTILITY PROGRAM

5-15
5-16
5-17
5-18
5-19
5-20

SECTION 6

DCU - the Drive ¢ Utility Program.
Using DCU S - the SPACE option..
Using DCU 0 - the OPTIMIZE option.
Using DCU to control the Print Buffer.
Using DCU without the menu..

DCU E - erasing the RAM-disk.........+

USING YOUR NEW Drive C SKILLS

USING QUICKPAC

6-1
6-2
6-3

SAVING
6-4
6-5
6-6
6-7
6-8
6-9
6-10
6-11
6-12
6-13

MAKING
6-14
6-15
6-16

SECTION 7

INDEX

iow!
7-2
7-3
7-4
7-5
7-6
7-7
7-8

+100
102
105

Making Drive C automatic.....+++s-
DCQINS - installing the QuickPac options.
Using QUICkPaC..sesssecsseseeeeeeenseenee

Drive C FILES

Gathing Leady, ssn dasoseesersseeyevetaces 109
Programs which copy files.....+- oa 111
UsdngsPIP acdaces ans dadaeascese vers 112
Archives iixasas cagesec ule ea, 113
Archive - choosing which files to store.. 114
Archive - storing files on floppy disk 116

118
119
120
123

The Archive diskette.......+
Using an Archive diskette set
Archive - saving all of Drive C.
RELTLCVes see eeeeeeerersereeecces

IT EVEN MORE AUTOMATIC
Using your function keys.....
The Remote Retrieve command..

ween e el 28
we eeee el 29

Remote Retrieve with QuickPac +130
APPENDICES
Using drive C with Ol System Utilities......... +131
Drive C hardware specifications. t gabeenhts +133
Drive C software specifications. Beene +134
Disk and RAM space usage with Drive C....... +135
Centronics parallel printer cable specifications. +136
Patching WordStar for improved printing. +137
Modifying QuickPac data files..... 2139
Using ZCPR with Drive C..+.....6. +141
142
7m)

How To Use This Manual

1-1 WHAT'S INSIDE AND WHERE TO FIND IT
1-2 SYMBOLS AND CONVENTIONS USED IN THIS MANUAL
1-3. Drive C FEATURES

1-1 WHAT'S INSIDE AND WHERE TO FIND IT

This manual is divided into several sections to make learning to use your Drive C
efficient and easy.

Each section is organized as a learn-as-you-go guide. Please don't try to start in
the middle of a section unless you're completely confident you already understand
all about Drive C.

Definitely read Section 1-2 next. There we explain all the symbols and
abbreviations used throughout this manual.

Section 1-3 gives you an overview of all Drive C features.

Please read Section 2 regardless of your level of skill with your Osborne. If you
follow our simple step-by-step installation procedure, you'll find installation
straightforward and pleasantly painless. There is a checklist/summary of the
installation procedure at the end of Section 2.

In Section 3 we explain how to make Drive C fit the way you use your computer. This
section was largely compiled from advice given us by Drive C users. You'll probably ©
want to re-read this section after you've learned how to use Drive C to “lock in”
what you've learned.

If you are a beginner with your computer or if you do not use CP/M commands and
utilities often, you'll probably want to read Section 4, the CP/M tutorial. If you
already use PIP, XDIR and other CP/M utilities feel free to skip this section.

In Section 5 we explain how to use each of the basic features of Drive C,
the RAM-disk, the Print Buffer and its Utility program.

Section 6 shows how to use QuickPac and our Archive/Retrieve program for fast-
loading and backing up of Drive C.

Section 7 contains several useful appendices. Everyone should read the first
appendix on using COPY, SYSGEN and SETUP with Drive C. Some of the other appendices
are more technical.
A
LN How To Use This Manual

1-2 SYMBOLS AND CONVENTIONS USED IN THIS MANUAL

Below are examples and explanations of the different symbols and conventions used in
this manual. Please acquaint yourself with these since they are used throughout

the manual.

When we refer to your Drive C unit we will use the term - Drive C

When we mean a logical drive name we will use the term - drive C:

THE RETURN KEY
<CR>, <RETURN>

EXPLANATION: Press the RETURN key.

CONTROL C
“¢c

EXPLANATION: Hold down the 'CTRL' key and press the 'C' key.

LOGICAL DRIVE INDICATOR

ES The 141 prope

EXPLANATION: The drive prompt that appears on your screen. The letter indicates
which logical drive is being used.

SINGLE LINE COMMANDS

DOCK CO RN «Install prive ¢ as c:

EXPLANATION: YOUR INPUT is always shown with a WHITE background. The SCREEN
DISPLAY for individual command lines is always shown with a GRAY
background.

In the above example, the A> is initially on the screen. You would
then type DCL followed by pressing the RETURN key.

Your input is always shown literally. If a space is shown in the
command, it must be included when you type the command.

To the right of each input is a brief explanation of the command. For
example, the command DCL<CR> installs the Drive C unit as the third
logical drive, drive C:.
How To Use This Manual

FULL SCREEN INPUTS

EXPLANATION: When a series of inputs are required as part of a program, the entire
sequence of inputs is shown.

Your inputs are shown with a WHITE background. The program display is
shown with a GRAY background.
SYSTEM STATUS ILLUSTRATION

cP/M SYS DISK A: B: WordStar Disk

EXPLANATION: Each System Status Illustration displays information-at-a-glance about
your Osborne, Drive C and floppy disk drives.

The logical drive NAMES for the Drive C unit and the floppy disk
drives are displayed above the floppy drives and below the Drive C
unit.

The diskette TITLES are shown next to the appropriate floppy disk drive.

The arrows on the diskettes indicate whether you should INSERT or
REMOVE a diskette for the next step in the manual.

In the above example, the CP/M Systems and Utilities diskette should
be inserted in your left-hand floppy drive named drive A:. The
WordStar diskette should be removed from drive B:. The Drive C unit
is installed and is named drive C:.

The message ‘Drive C: NOT INSTALLED’ is displayed whenever Drive C is
NOT installed as a third drive. It is NOT necessary to physically
remove Drive C when you see this message.

ee
A) How To Use This Manual

DC USER DISK WordStar Disk
AUTOST —-COM AUTOST —. COM
DCA CoM INSTALL .COM
DcL. -coM MERGPRIN .OVR
peq -coM SAMPLE «TXT
peg DAT ws -COM

WSMSGS -OVR
WSOVLY1 .OVR

DCQAUT —.COM
DCQINS — . COM

DCU +COM XDIR -COM
DFD -SPR
PIP -COM A
PRN -TST
XDIR + COM AUTOST -COM SAMPLE «TXT
DCN COM ws +COM
DCU +COM WSMSGS -OVR
Drive C: «SYS WSOVL1 -OVR
INSTALL .COM =- XDIR -COM

MERGPRIN .OVR
EXPLANATION: The System Status Illustration also lists the files on both Drive C
and the floppy diskettes.
When a specific file or program is being emphasized, the System Status
Illustration may show only that file rather than a complete listing.
TYPING YOUR INPUTS

ALL user inputs in the manual are shown CAPITALIZED. It is NOT necessary for you
to capitalize your inputs. Drive C software will accept both upper- and lower-case
inputs.
\_ ae
How To Use This Manual A

1-3 Drive C FEATURES

Drive C is an integrated hardware and software enhancement designed specifically for
your Osborne 1. Drive C not only dramatically improves performance and adds new
capabilities...it actually improves the way you use your Osborne 1.

RAN-disk
Your Osborne 1 has two floppy disk drives. The Drive C RAM-disk acts as a third
logical drive, drive C:. It is called a logical drive because, to your Osborne,
Drive C looks just like your floppy disk drives. Therefore, you can use Drive C
EXACTLY as you use floppy drives A: and B:.

While floppy disk drives are slow, noisy and prone to mechanical failure, Drive C is
fully electronic, silent and has no moving parts.

It can find information stored on it up to 20 times faster than a floppy disk drive.
As a result, you will experience a dramatic improvement in program performance.

= My ; we

/)

The Drive C RAM-disk is the third logical drive.
It accesses information and communicates with your Osborne much faster
than your floppy disk drives.

This increase in disk speed dramatically affects the way many programs respond.
WordStar frequently stops and starts as the floppy disk drives slowly access files.
With Drive C, WordStar works smoothly without lengthy disk interruptions and a
writer can, for the first time, write in a very natural way.

Drive C also adds additional on-line storage capacity. More programs and data can
be stored on your Osborne. This feature eliminates constantly changing diskettes.

For example, you can easily have WordStar, SuperCalc, text and data files on Drive C
and still have additional programs on your floppy diskettes. Large, complex
programs like dBase II requiring many different files that work together, can now be
resident on your Osborne at the same time.

ae
A How To Use This Manual

Many different programs that

Programs should work together
TOoErnEe cannot be on-line at the
= Ein pale
Your Osborne | has limited rien Checkes Files

disk capacity. The diskettes must

constantly be changed.

avec: mecnncemm ja) vee
cA Paint
Drive C's additional PROGRAMS
capacity lets many MS. ‘came
different programs Pn areas
be on-line at the z TF woraster
same time, working | pve G Text Files
together. ‘aunercale
Data Files

The Drive C RAM-disk acts as one big logical disk drive. As a result, ite full
capacity can be used for one large file.

Programs, documents and databases can be built on the 384K Drive C that are twice as

big as those created on double-density floppy disks and four times the size of those
on single-density disks.

ARAYA. I =mm mse
AU

Very big programs, documents and data bases can be created on your Drive C.

Files this large are not possible on your floppy disks.

While Drive C acts like a floppy disk drive, it does not use actual diskettes.
Files must be moved to and from Drive C using file copying programs like PIP, Sweep
or WordStar. Once files are copied onto Drive Cs, they will remain there until you
turn the power off, EVEN IF YOU PRESS THE RESET BUTTON.

The names of your floppy disk drives can be changed even though 'A’ and 'B' are
embossed on the Osborne front panel. Drive C software allows you to rename both
Drive C and the floppy disk drives. The Drive C RAM-disk, for instance, should be
renamed to drive A: in order to run WordStar.

i.
How To Use This Manual

The red drive indicator light on the front of Drive C works just like the red LEDs
on your floppy disk drives to let you know when the Drive Cé unit is active.

drive C: drive B:
= =F
wr

Copy files
onto Drive C:
(renamed drive A‘)
using PIP.

ARCHIVE AND RETRIEVE

Copy files
onto Drive C:
(renamed drive A:)
using PIP.

Drive C

drive A:

When your Osborne is turned off, Drive C will no longer be powered and files in
Drive C will be lost. Files on Drive C should be saved (backed up) on floppy disk
before turning your Osborne off. This can be done using PIP or file copying options
in programs like WordStar.

ARCHIVE (DCA.COM) automatically stores any or all of the files from Drive C onto
floppy diskettes. Files on Drive C that are larger than a single floppy diskette
can be stored on a set of diskettes. ARCHIVE algo labels and organizes each backup
set.

RETRIEVE automatically reloads and reconstructs the original Drive C files from your
Archival backup set.

BackPac, the optional Drive C power supply/battery backup system, fits in your
keyboard. BackPac maintains the contents of Drive C even if the Osborne is turned
off. Adding BackPac gives Drive C permanent storage capability, in essence letting
Drive C act as an ultra-fast hard disk.

No electrical or mechanical modifications of your Osborne are necessary with
BackPac.
SSS
LN How To Use This Manual

Backup (copy) individual Backup files as large
Drive C files onto as 376K onto a
floppy diskettes set of “Gh
using PIP. Ds] using Archive,

Tae, maximum sce Cl and reconstruct

ive or pores eee Dre the original contents
capacity of your ies y Retrieve
floppy diskette 2 ‘

BackPac supplies coupmyous _ ‘Files are retained
continuous power even when your

to Drive C PoweR —- Osborne is turned off.
BackPac
PRINT BUFFER

The Drive C Print Buffer lets you use your Osborne while simultaneously printing
files. Once installed, Print Buffer operation is automatic.

Your printer normally ties up your Osborne until it has completed printing a file.
The Print Buffer stores the print output from your Osborne at high speed and quickly
returns control of your Osborne to you. You may continue to run programs while the
Print Buffer automatically sends the print output to the printer.

THE PRINT BUFFER WORKS WITH BOTH RS-232 SERIAL AND CENTRONICS PARALLEL PRINTERS.

oe Siow
Print Output

ber

oe >) eum)

Fast
Print Output

‘osbome 1
CPU)

Put Outout —

ET 2

The Print Buffer quickly stores the print output.

Panter

Your Osborne can be used for computing
while the Print Buffer is printing.
How To Use This Manual

The Drive C unit is partitioned by its software into a RAM~disk space and a Print
Buffer space.
You can partition the Drive C for Print Buffer use in two different ways:

The FIXED BUFFER is a space on Drive C that is reserved solely for Print Buffer use.
Eight Fixed Buffer sizes are available, from 16K to 128K.

The DYNAMIC BUFFER uses any space on the Drive C which is not being used as RAM-disk
space. As you add or delete files from the RAM-disk, the Dynamic Buffer
automatically increases or decreases in size. Up to the full capacity of the Drive
C can be used as the Print Buffer using the Dynamic Buffer option.

Drive

er ia
a

Simultaneous use

=
at

wy
FIXED BUFFER DYNAMIC BUFFER
ay see
CPU ‘Printer
‘SS
J __A
aa ae

You can queue any number of files to be printed from both floppy disks and the RAM-
disk. Files to be printed are stacked in the Print Buffer and will be printed in

first-come, first-served order.
ete
A How To Use This Manual

The Drive C Utility program (DCU.COM) gives you a number of helpful tools to use
with the Print Buffer. With DCU you can determine and optimize the space available
for the Dynamic Buffer. You can also pause, restart and clear the Print Buffer.

QUICKPAC

QuickPac makes using Drive C even easier. A single keystroke starts QuickPac.
QuickPac installs Drive C, renames Drive C and installs your choice of Print
Buffers. It can also copy the contents of one or both of your floppy disks to Drive
C and automatically run a program.

The QuickPac Installation program is an easy-to-use, menu~selection program that
lets you choose from the various QuickPac options.
TURBOPAC

TurboPac is the powerful Drive C/Trantor hard disk system. TurboPac software turns
your Drive € into a hi-speed Cache Buffer for the Trantor hard disk.

TurboPac automatically keeps your most frequently used programs and data in the
Drive C Cache Buffer, increasing the hard disk throughput by as much as five times.

The 192K TurboPac system uses all of Drive C as a Cache Buffer. The 384K TurboPac
system partitions Drive € into a 256K Cache Buffer and a 128K Fixed Print Buffer.

The hard disk attaches to the Drive C PRINTER/HARD DISK/8088 port and no mechanical
modifications are necessary.

Drive C can still be used for portable operation by detaching the hard disk and
using the normal Drive C RAM-disk/Print Buffer software.

VERY [Deve C:
‘Osborne 1\ i mK ASTo q| — > Tantor Hard Disk
ao — =p, )
eg
‘Osborne 1
CPU VERY
rast

4 = eqynrr=

FAST =—
PRINT OUTPUT % pe
Aninipe=—__)

10
i”
Getting Started
F

CONTENTS

2-1 MECHANICAL INSTALLATION OF Drive ¢

2-2 REMOVING THE Drive € UNIT

2-3 USING DISPLAY SCREENS WITH Drive C

2-4 MAKING YOUR COPY OF THE Drive C SOFTWARE
2-5 FOR USERS OF REV 1.2 Ols

2-6 TESTING YOUR Drive C INSTALLATION

2-7 TROUBLESHOOTING THE Drive C INSTALLATION
2-8 INSTALLING Drive C WITH YOUR PRINTER

2-9 TROUBLESHOOTING THE PARALLEL PRINTER INSTALLATION
2-10 COPYING YOUR CP/M ONTO THE DC USER DISK
2-11 TESTING YOUR PRINTER OPERATION

2-12 TROUBLE-SHOOTING YOUR PRINTER, PART 2
2-13 QUICK CHECKLIST OF Drive C INSTALLATION

2-1 MECHANICAL INSTALLATION

** DO NOT INSTALL YOUR Drive C UNIT YET **

Housed in a stainless steel case, Drive C is a rugged, solid state device which fits
snugly into the right-hand floppy diskette storage pocket of the Osborne 1.

Drive C has been designed specifically for your Osborne 1. It generates very little
heat and needs no maintenance. Installation does not require any electrical or
mechanical modifications to your Osborne nor are any special tools required.

Two cables attach Drive C to the Osborne. One cable plugs into the Ext. Video edge
connector. The other cable plugs into the IEEE-488 edge connector. You can think
of these cables as “extension cords”.

The Drive C edge connectors located at the end of the “extension cord” cables

duplicate the Osborne Ext. Video and IEEE-488 edge connectors. You don't lose the
use of your Osborne connectors by adding Drive C.

11
7. Y
d J Getting Started
ys)

For instance, if your parallel printer was normally connected to the Osborne IEEE-
488 connector, you would instead connect it to the new edge connector at the end of
the “extension cord” cable on the Drive C, labeled PRINTER/HARD DISK/8088.

CABLE ADJUSTMENT

Drive C works with both brown and blue case Osborne 1's. There are minor mechanical
differences between these machines, but Drive C's design compensates for these
differences.

The Drive C “Extension Cord" cables reach down from the right-hand floppy diskette
pocket to the IEEE-488 and Ext. Video edge connectors on the Osborne 1. The
distance from the right diskette pocket to the edge connectors is different on Brow
and Blue case Osborne is.

Drive ©
SF hig distance
fol the brown case

96 Joe
y€ is Yel" greater
VY ¥ lt on the
bide case.

(EEE 488 Ext. Video

12
Ye
Getting Started d
’

Y ADJUST YOUR CABLE LENGTHS, VIEW YOUR Drive C FROM ITS FOAM COVERED
SIDE AND FOLD THE CABLES AS SHOWN.

BROWN CASE

Base of Drive C
Foam

BLUE CASE

Base of Drive C “SS
Foam

13
,

ry
/ : J Getting Started
be

BROWN CASE POCKET BEIGHT ADJUSTMENT
For owners of BROWN CASE Ols only (NOT for BLUE CASE OWNERS)

The height of the floppy diskette storage pocket varies widely among brown case
Osborne ls.

Two self-adhesive bumpers are enclosed with your Drive C unit. Attached to the top
surface of your Drive C, they provide a snug fit regardless of the height of your
Osborne's pocket.

Please peel the protective covering from each bumper and attach as follows:

ONE BUMPER SHOULD BE PLACED ALONG EACH UPPER EDGE OF YOUR Drive C UNIT

Locate the bumpers toward the rear
for deeper pockets.

Locate the bumpers forward
14 for narrower pockets.
.
Getting Started

yd

Drive C UNIT INSTALLATION
** MAKE SURE YOUR OSBORNE IS TURNED OFF **

Slide the Drive C unit into the right-hand floppy diskette storage pocket until the
Drive C front panel is seated flush with the Osborne 1 front panel.

Connect the short 20-conductor VIDEO "Extension Cord” cable from the Drive C to the
Osborne 1 Ext. Video edge connector.

Connect the long 26-conductor IEEE~488 “Extension Cord” cable from the Drive C to
the Osborne 1 IEEE-488 edge connector. The IEEE-488 cable should fit between the
RESET button and the BATTERY connector.

Enclosed with your Drive C is a self-adhesive plastic cable clamp for the IEEE-488
cable. Remove the protective covering and install the cable clamp between the 01
front panel Keyboard connector and the Brightness control knob. This clamp will
conveniently keep the Drive C signal cable in its proper position.

Se re EN
Ls oO =a

a ci Sa)

;

15
ee

ra
if ) Getting Started

2-2 REMOVING THE Drive C UNIT

To remove your Drive C unit, please follow these steps:
REMOVE the black cable clamp from the Osborne front panel and store for future use.

DETACH the long cable from the Osborne IEEK-488 edge connector. Use pliers (channel
lock pliers work best) to gently pull the black connector body at the Osborne end of
the cable. DO NOT PULL ON THE CABLE ITSELF.

DETACH the short cable from the Osborne Ext. Video edge connector. Use pliers to
gently pull the black connector body at the Osborne end of the cable. DO NOT PULL
ON THE CABLE ITSELF.

GENTLY, so you won't mar either Drive C or your Osborne, pry the front pwel of the
Drive C unit out from the floppy diskette storage pocket. Use a small screwdriver
as a lever until the Drive C unit is about 1/4 inch out of the pocket. Continue
pulling out the Drive C unit by hand, grasping the front panel between the two
“extension cord” cables.

16
Getting Started

IETS nrnEnEE ESI nEIEErEneeeesecmeee ==

2-3 USING DISPLAY SCREENS WITH Drive C

EXT. VIDEO/BATTERY PORT

The Drive C EXT. VIDEO/BATTERY edge connector above the short “extension cord” cable
is an exact duplicate of the Osborne Ext. Video edge connector.

TO USE YOUR OSBORNE INTERNAL MONITOR

Your 5" internal monitor is enabled by attaching the black VIDEO SHORTING PLUG
supplied with your Osborne. This plug has a label which says, "DO NOT REMOVE WHILE
POWER IS ON”.

When the Video Shorting Plug is plugged onto the Drive @ EXT. VIDEO/BATTERY edge
connector, video signals are directed to your internal monitor. With the Video
Shorting Plug installed on your Drive C, your Osborne keyboard can be attached and
the case closed without interference.

Please, DO NOT INSERT OR REMOVE the Video Shorting Plug with power ON.

TO USE THE OSBORNE EXTERNAL MONITOR WITH 52-COLUMN DISPLAY

Attach the cable from the Brown Osborne external monitor to the Drive C EXT.
VIDEO/BATTERY edge connector.

TO USE EXTERNAL VIDEQ MONITORS WITH 52-COLUMN DISPLAY.

Commercial external video monitors require composite video signals. If you have a
composite video monitor then you've been using an adapter connected to your Osborne
Ext. Video edge connector. Drive C has its own built-in video adapter and your
adapter IS NO LONGER NECESSARY.

The VIDEO jack on the front panel of the Drive C unit provides composite video
signals for your external monitor. These signals are always available regardless of
whether the Video Shorting Plug is installed or not.

Attach the cable from your external composite video monitor to the RCA VIDEO jack.
Turn the CONTRAST control on your Osborne 1 all the way UP, and re-adjust the
BRIGHTNESS control on your Ol (if you are using the internal display) to your taste.

You may have to readjust the BRIGHTNESS, CONTRAST and HORIZONTAL SYNC controls on
your external display to get @ clear picture centered in the screen.

If you use an external monitor and DO NOT want your internal monitor on, DO NOT
install the Video Shorting Plug on Drive C.

If you use an external monitor and want BOTH the external and internal monitors on,
DO install the Video Shorting Plug on Drive C.

7
f,
Getting Started
Fy)

TO USE 80-COLUMN DISPLAYS

If you have an 80-column display Adapter (such as Osborne's ScreenPac) installed, DO
NOT attach your external monitor cable to the Drive C VIDEO jack. Continue to use
the 80-column composite video RCA jack supplied with your 80-column upgrade.

Osborne 80-column upgrades require the Video Shorting Plug to be installed on the
Drive C EXT. VIDEO/BATTERY edge connector.

Drive C works with all 80-column upgrades made by independent manufacturers that DO
NOT use the IEEE-488 port. Follow the manufacturers instructions and use the new

80-column RCA jack provided with the upgrade. If any connections to the Osborne
Ext. Video connection were required, use the Drive C EXT. VIDEO/BATTERY connector

instead.
TO USE THE OSBORNE EXTERNAL MONITOR WITH 80-COLUMN DISPLAY
If you have an-Osborne external monitor with the special 80-column adapter, attach

the adapter to the Drive C EXT. VIDEO/BATTERY edge connector and the cable to the
80-column RCA jack.

External Monitor - 52 Column

Video Shorting Plug
(Optional)

External Monitor - 80 Column Osborne External Monitor -
es Sind Ea 52 Column

i ~
Getting Started

LL

2-4 MAKING YOUR USKR COPY OF THE Drive C SOFTWARE

First we'll cover how to check your

sure it contains the correct files.

Turn ON power to your computer.

If either your internal or external
previous Section, 2-3, to make sure

correctly.

#** IMPORTANT *#*

NOTE the Rev Number displayed in the rectangular box after turning on power but

before loading CP/M.

1.44.

Drive C LOADER & ARCHIVE DISK using XDIR to make

display is not just right, please return to the
you have connected and adjusted your display(s)

This number is two or three digits ranging from Rev 1.2 to Rev

You will need a blank diskette and a copy of your Osborne CP/M System and Utilities
diskette for the this Section.

Please label the blank diskette DC USER DISK.

Single density 01's sometimes have two CP/M System disks, one labeled
DISK and the other labeled CP/M UTILITY DISK.

Use the one called the

CP/M SYSTEM
SYSTEM DISK.

DO NOT REMOVE THE WRITE PROTECT TAB FROM YOUR ORIGINAL Drive C LOADER & ARCHIVE

Insert your CP/M system disk in drive A: and the Drive C LOADER & ARCHIVE DISK in

DISK!

drive B:.
ce/M SYS DISK
ASM +COM
AUTOST -COM
COPY -COM
DDT -COM
DUMP -COM
ED -COM
HELP COM
LOAD -COM
MOVCPM -COM
PIP -COM
SETUP COM
STAT -COM
SUBMIT «COM
SYSCEN -COM
XDIR -COM
XSUB -COM

Drive C NOT INSTALLED

LOADER & ARCHIVE

AUTOST
DCA
DCL
peq
beq
DCQaUT
DCQINS
peu
DED
PIP
PRN
XDIR

+COM
COM
+COM
COM
«DAT
-COM
-COM
-COM
«SPR
COM
«TST
-COM

19

f,
Getting Started
F’

Press <CR> to load CP/M. The A> should appear on your screen.

If you have AutoStart on your CP/M Systems and Utilities diskette, a menu will
appear on your screen. Press <ESC> to get the A>.

Run XDIR from A: to check B:

You should see the following screen:

If your LOADER & ARCHIVE DISK is DIFFERENT from this display (except for the version
number of XDIR, which will vary) please write or call Drive C for assistance.

Next, we'll explain how to copy the Drive C LOADER & ARCHIVE diskette using
COPY.COM. Type the Copy command as shown:

CNN ton cove son a:

Remove the CP/M SYSTEM DISK from drive A:.

CP/M SYS DISK A: B: LOADER & ARCHIVE

20
i” Y
Getting Started
F

Insert the DC USER DISK in drive A:.

DC USER DISK Az B: LOADER & ARCHIVE

Blank

Drive C NOT INSTALLED

Select the COPY option which copies All of the diskette (including the System
Tracks) FROM drive B: TO drive A:,

<CR> |
BE CAREFUL NOT to press <CR> when COPY asks if you want to copy another disk or to
return to CP/M. If you do press <CR> at that point you will probably get a boot
error later with this DC USER DISK.
DO NOT SYSGEN OR WRITE PROTECT YOUR DC USER DISK!

Remove your LOADER & ARCHIVE DISK and save it in a safe place for future reference.

DC USER DISK A B: LOADER & ARCHIVE
AUTOST COM
DCA -COM
DCL -COM
Deg + COM
DeQ DAT
DegaUT =. CON
DCQINS COM
Deu COM
DFD +SPR
PIP =COM
PRN -TST
XDIR +COM

Press the [RESET] button.

= 21

T.
Getting Started
F)

2-5 FOR USERS OF REV 1.2 Ols ONLY

If you have a single density computer AND the Rev Number (the number in the
rectangular box after power up or Reset) of your 01 is 1.2, then you MUST put CP/M
onto your DC USER DISK next.

If your Ol's Rev Number is any other number (such as 1.3 or 1.44) please skip this
step and proceed to Section 2-6.

Remove the DC USER DISK from drive A:.

DC USER DISK A: B: NO Diskette

Drive C NOT INSTALLED
Tarn OFF power to your computer, then turn it back ON.

Put your CP/M System Disk in drive A: and your DC USER DISK in drive B:

ce/M SYS DISK A: B: DC USER DISK

Drive C NOT INSTALLED
Getting Started

"|
<)

SECTION 2.5 ONLY FOR USERS OF REV 1.2 Ols (continued)

Press <CR> and, if necessary, <ESC> to boot up to the A>.

S YSGEN: Run SYSGEN from drive A:

You will need to check the set up of your CP/M system so make sure the printer port
is assigned correctly.

| sm Run SETUP from A: to check B:

You should check to make sure your system is setup as follows:

A PRINTER CENTRONICS (Unless you have an RS-232 Serial printer)

B BAUD RATE 1200 (assuming your Serial printer is set to 1200 baud.
Baud rate has no effect on Centronics printer)

C SCREEN 128 (or whatever size you usually use)

D AUTO SCROLL ON

E FUNCTION KEYS: have no effect on this test procedure, don't use them.
F ARROW KEYS CP/M

Save the correct setup configuration onto the DC USER DISK in drive B:.

23

Re ee

wr
d ) Getting Started
t y

2-6 TESTING YOUR Drive C INSTALLATION

** DO NOT INSTALL YOUR PARALLEL PRINTER CABLE YRT **
Just as you cannot use a program like WordStar until you have loaded it into your
Osborne, you cannot use Drive C until you have installed (loaded) the Drive C
software.

With our set of programs called QuickPac installing Drive ¢ as a RAM-disk is very
simple and requires only a single key stroke.

The DC USER DISK should be in drive A:.

DC USER DISK Az B: NO Diskette

Drive C NOT INSTALLED

Press the [RESET] button.

Press <CR> to start QuickPac.

QuickPac will:

1. install the Drive C RAM-disk software

2. rename the Drive C unit to drive A: and the left-hand floppy to drive C:.
3. copy the contents of the DC USER DISK to the Drive C unit using PIP.

4. run XDIR on the Drive C unit, now renamed to drive A:

QuickPac displays messages as it is running. When the QuickPac operation is
completed it will alert you with a beep and a message. The entire operation should
take about one minute.
Sa
é
Getting Started d
F)

DC USER DISK c: B NO Diskette

DCA ~COM DCU +COM
DCLOADED .-SYS Drive C: .SYS
DCN -COM PIP -COM
DCQAUT -COM PRN TST
DCQINS -COM XDIR COM

The Drive C RAM-disk should now be installed as a third logical drive, drive A:.
You should see the following display:

IF YOU HAVE A 192K Drive C UNIT:

25

a ser
’,
Getting Started
>]

IF YOU HAVE A 384K Drive C UNIT:

If your screen shows the correct information, your Drive C is now successfully
installed. Please continue to Section 2-8 to install and test your printer.

If your screen does NOT show the CORRECT information, please continue to the next
Section, Trouble-shooting the Drive C Installation.

26

v.
Getting Started d
F)

2-1 ‘TROUBLE-SHOOTING THE Drive C INSTALLATION
Before trouble-shooting the RAM-disk installation, REMOVE the DC USER DISK from the
floppy disk drive and turn the Osborne's power OFF.

1. Check that Drive C's EXT VIDEO and IEEE-488 cables are securely connected to
the Osborne edge connector contacts.

2. If the contacts on your Osborne edge connectors are not clean, there may not be
a reliable electrical connection between Drive C and your Osborne.

Gently wipe the contacts clean, using a cotton swab slightly wetted with rubbing
alcohol.

3. Osbornes with silver colored (solder coated) edge contacts can become
contaminated with time. This can be a source of continuing electrical problems with
both Drive C and printer cables. Gold-plated replacement contacts are commercially
available to remedy this problem.

4. YOUR CENTRONICS-STYLE PRINTER CABLE SHOULD NOT BE CONNECTED DURING INITIAL RAM-
disk INSTALLATION AND TEST. Disconnect it if it was connected and run the
installation tests again.

5. Make sure that the test was run with the DC USER DISK.

6. If you have a single density 01 with Rev Number 1.2, make sure that you put
CP/M on your DC USER DISK using SYSGEN as detailed in Section 2-5.

7. Make sure your DC USER DISK is NOT write protected with a tab.

8. If you are re-running the DC USER DISK QuickPac test:

First: ALWAYS REMOVE the DC USER DISK and turn OFF the 01 power,
Second: Wait five seconds,

Third: ‘Turn power back ON,

Fourth: Put the DC USER DISK in drive A:

THEN: Press <CR> to restart QuickPac.

If re-running the test still doesn’t work, you should start over by recopying the
Drive C LOADER & ARCHIVE Diek onto your DC USER DISK step by step.

27
eS
i ‘#
d Getting Started
|

SS

2-8 ‘INSTALLING Drive C WITH YOUR PRINTER

IF YOU HAVE A SERIAL PRINTER

Skip this Section and Section 2-9 which cover installing and trouble-shooting
Centronics printers and go to Section 2-10, Putting your CP/M on the DC USER DISK.

IF YOU HAVE A CENTRONICS PARALLEL PRINTER
** DO NOT ATTACH YOUR PRINTER CABLE YET **

Installing your parallel printer with Drive C requires no special software or
hardware. Printers and printer cables, however, are very individualized producte,
often eccentric in their design and even cantankerous in their performance. This
Section will guide you through the installation of your printer with Drive C to make
sure that it is working properly. The Print Buffer will not be installed yet.

Your parallel printer is normally attached to the IEEE-488 edge connector on your
Osborne. The PRINTER/HARD DISK/8088 edge connector on the Drive C duplicates the
parallel port function of the Osborne IEEE-488 port. To use your parallel printer
with Drive C, your printer cable will be connected to the Drive C PRINTER/HARD
DISK/8088 connector instead of the Osborne IEEE-488 connector.

‘** =~ TEEE-488 COMMUNICATIONS PROTOCOL IS NOT SUPPORTED **
ON THE Drive C PRINTER/HARD DISK/8088 EDGE CONNECTOR

Incorrectly wired cables may interfere with Drive C operation. This Section will
test your cable and explain how to easily fix it if is incorrectly wired.

Most Centronics parallel printers change the electrical conditions of the cable when
they are turned OFF, causing problems for the Drive C unit similar to those caused
by incorrectly wired cables.

YOUR CENTRONICS-SYLE PRINTER SHOULD ALWAYS BE ON FOR PROPER Drive C OPERATION IF ITS
CABLE IS PLUGGED INTO THE Drive C. Neither your printer nor Drive C will be harmed
by keeping your printer turned ON during Drive C use.

Also, the printer cable should be attached to or removed from the PRINTER/HARD
DISK/8088 port on the Drive C unit ONLY when your 01 computer's power is OFF.
Getting Started

INSTALLING YOUR CENTRONICS PARALLEL PRINTER CABLE

Remove the DC USER DISK and turn the 01 power OFF.

DC USER DISK A: B: NO DISK

Drive C NOT INSTALLED

Attach the parallel printer cable to the PRINTER/HARD DISK/8088 edge connector.
Connect it in the same way it was connected to the Osborne IEEE~488 port, i.e. with
the pin 1 of the cable to the right.

Turn ON the power to your printer.

Turn ON the power to your Osborne 1 and put the DC USER DISK back in drive A;.

DC USER DISK AD B: NO DISK

Drive C NOT INSTALLED

Press <CR> to run QuickPac again, You should see the same sequence of events as
before when you loaded QuickPac without the printer.

T£ QuickPac completed its operation exactly as before, then skip the next Section
and proceed to Section 2-10, Putting your CP/M on the DC USER DISK. Actual printer
operation will be tested in Section 2-11.

If your QuickPac test did not function exactly as before, or the QuickPac XDIR

display gave different information about the files on the Drive ¢ unit, please
proceed to the next Section, Trouble shooting the Parallel Printer Installation.

29
-
ly J Getting Started

ys

2-9 TROUBLESHOOTING THE PARALLEL PRINTER INSTALLATION

1. Remove the DC USER DISK and turn the Osborne power OFF. This will clear the
results of the previous test.

DC USER DISK A: B: WO Diskette

Drive C NOT INSTALLED

2. If you tested your parallel printer installation with the printer OFF, please
try it again with the printer power ON.

3. Make sure your printer cable is firmly plugged into the Drive C PRINTER/HARD
DISK/8088 port edge connector, AND into the printer.

4. Make sure your printer is ON-LINE (selected).

5. If you have SYSGEN'd the DC USER DISK for Rev Number 1.2 computers as we
instructed in Section 2-5, please check the disk's setup by using your copy of
SETUP.COM (as explained in Section 2-5). Make sure the disk is set up for
Centronics printer, NOT serial or IEEE-488.

6. Drive C works correctly with all Osborne-standard parallel printer cables.
Some parallel printer cables do not conform to standard Osborne specifications and
have an extra unnecessary wire. If you have such a cable, both your printer AND
Drive € will not work correctly.

An incorrectly wired cable is a VERY COMMON problem. To check your parallel printer
cable, open the housing at the PRINTER END of the cable. The housing can usually be
opened with a screwdriver or popped open with your fingernails.

There should NOT be a connection to pin 12 on the 36-pin connector at the printer
end of the cable. If there is a wire attached to pin 12, it must be disconnected.

Disconnecting this wire has no effect on your printer when used either with OR
without Drive C.

DO NOT MAKE ANY MODIFICATIONS TO THE OSBORNE END OF YOUR PRINTER CABLE.

30
7.
Getting Started "Le

7. Replace the cable housing and turn the Osborne power ON.
8. GO BACK TO SECTION 2-8 AND RERUN THE QuickPac TEST.

9. If you stili do not get the proper results, call Drive C for assistance.

31
Getting Started

2-10 COPYING YOUR CP/M ONTO THE DC USER DISK

IF YOU HAVE A REV NUMBER 1.2 OSBORNE 1

If you have a Rev Number 1.2 Osborne 1 you should have already copied CP/M onto your
DC USER DISK back in Section 2-5. If you have not, go back to 2-5. 00 NOT USE THIS
SECTION. If you copied CP/M in Section 2-5, PLEASE SKIP THIS SECTION and go to

Section 2-11, Testing Your Printer Operation.
I YOU HAVE A REV NUMBER 1.3 - 1.44 OSBORNE 1

Before trying the next test you will need to copy CP/M from one of the disks you

normally use to boot up onto the DC USER DISK. For this operation you'll use the

SYSGEN and SETUP utilities. Your versions of these two programs may give a slightly

different display from that shown below, but the procedure to follow is the same.

Remove the DC USER DISK and turn the 01 power OFF.

Dc USER DISK A: B: NO Diskette

Drive C NOT INSTALLED

Turn ON the power to your Osborne 1. Put the CP/M SYS DISK in drive A: and the DC
USER DISK back in drive

DC USEB DISK

CP/M SYS DISK =

Drive C NOT INSTALLED

32
7 Y
Getting Started

r
Press the [RESET] button.
Press <CR> (and, if necessary, <ESC>) to boot up CP/M and get the A>.
Run SYSGEN from A: (get system from B:)

33

v.
d Getting Started
s

You now need to check the setup of your CP/M system on the DC USER DISK to make sure
the printer port is assigned correctly.

Run SETUP from A: to check B:

You should check to make sure your system is set up as follows:

A PRINTER CENTRONICS (or SERIAL if you have an RS-232 Serial printer)

B BAUD RATE 1200 (assuming your Serial printer is set to 1200 baud.
Baud rate has no effect on Centronics printer)

C SCREEN 128 (or whatever size you usually use)
D AUTO SCROLL ON (or OFF if you are using OCC's ScreenPac)
E FUNCTION KEYS: have no effect on this test procedure, don't use them

F ARROW KEYS CP/M (or WORDSTAR if you prefer)

If you have changed the setup please BE SURE TO SAVE THE NEW SETUP ONTO drive B:.

When you have finished checking and saving your setup press CR> to exit to CP/M.

Remove the CP/M SYSTEM DISK from drive A: and insert the DC USER DISK in drive A:.

‘ prompt

DC USER DISK Az B: NO Diskette

Drive C NOT INSTALLED
7. Y
Getting Started
F’

2-11 TESTING YOUR PRINTER OPERATION

Now let's make sure your printer (whether Centronics parallel or RS-232 Serial)
works properly with Drive C.

Make sure:

1. that your printer is ON

2. its cable is connected properly

3. the printer has at least SIX continuous pages of paper
4. it's ready to print (on-line)

DC USER DISK A: B: NO Diskette

— —- oe

Drive € NOT INSTALLED
Press the [RESET] button.

Press <CR> to start QuickPac.

After QuickPac runs XDIR (as before in Sections 2-6 and/or 2-8) and gives you the
cP/M A> prompt, proceed as follows:

To see exactly what the print output should look like, display the file PRN.TST on
your screen by typing this command:

PRN. TST<CR> Display file PRN.TST on screen.

You should see a pattern repeating over and over. The beginning seven lines of this
pattern are shown below:

35
Sane
(A
d Getting Started
t)

To actually print the test file, type this command:

Print PRN.TST using PIP

Your printer should now be printing the same pattern you previously saw onscreen
with the TYPE command.

The PRN.TST file contains approximately three pages of this test pattern.

If you can print even a few lines your installation is working just fine and you can
stop the test if you want to.

To STOP the print test: Type “C to clear PIP back to the CP/M A>.
NOTE: we are not using the Drive C Print Buffer feature for this test, so you will
not see the next A> prompt until the file is completely printed or until you stop
the test with “C. If your printer has an internal buffer or if you are using an
external print buffer box, the printer may keep printing for a while after the
computer has finished sending characters to the buffer.

IF YOUR SYSTEM HAD PROBLEMS PRINTING PRN.TST
I€ you had problems printing PRN.TST go on to Section 2-12, Trouble-shooting your
printer, Part 2.

IF YOUR SYSTEM PASSED THE TESTS

If your system successfully passed all the tests so far, you're ALMOST done with
installation!

DC USER DISK c: B: HO Diskette

Please remove the DC USER DISK and turn OFF the 01 power.
f.
Getting Started d
y

2-12 TROUBLE-SHOOTING PRINTER OPERATION, PART 2

1. Please check that the DC USER DISK is properly configured for your printer
(CENTRONICS or RS-232 Serial) using SETUP.COM, Check your DG USER DISK's setup
against the list at the end of Section 2-10.

2. Check that your printer is on-line and has paper.

3. If you are re-running the DC USER DISK printer operation test:

Firs

ALWAYS REMOVE the DC USER DISK and turn OFF the 01 power,
Second: Wait five seconds,
Third: Turn power back ON,
Fourth: Insert the DC USER DISK in drive A: and press <CR> to rerun QuickPac.
THEN: § Retype the PIP LST:=PRN.TST command to retry the test.
4, I£ you are still experiencing difficulties, please contact the Drive C Service
Department for assistance. We will need to know the following if you call or write
us to get help fixing your problem.
a. Is your 01 in a brown or blue case?
b. Is your 01 eingle- or double~density?
c. What is your Ol's Rev Number (from the rectangular box on the screen)?
d. What is your Drive C serial number?
e. What size is your Drive C (192K or 384K)?
IF YOUR SYSTEM PASSED THE TESTS

If your system successfully passed all the teats so far, you're ALMOST done with
installation!

ERA UTOST.COM<CR> Erase AUTOST.COM from C: (DC USER DISK)

DC USER DISK B: NO Diskette

Please remove the DC USER DISK and turn OFF the 01 power.

37
+

Getting Started

2-13 QUICK CHECKLIST OF Drive C INSTALLATION

This list is for your convenience if you ate already thoroughly familiar with your
computer and CP/M. Please don't use this checklist in place of the step-by-step
installation guide.

The procedures in Section 2 were developed to GUARANTEE a satisfactory Drive C
installation EVERY TIME. To make trouble-shooting easier, this checklist refers to
specific detailed parts of Section 2.

Step 1. Adjust Drive C cable lengths to fit your computer [Section 2-1]
Step 2. Mechanically install your Drive C unit [Section 2-1]
Step 3. Reconnect cables and Video Shorting Plug to your display [Section 2-3]

Step 4. Check files on Drive C ARCHIVE & LOADER Disk supplied with your unit
[Section 2-4]

Step 5. Copy LOADER & ARCHIVE Disk to DC USER Disk [Section 2-4]

Step 6. [Only for ROM Number 1.2 single-density machines] SYSGEN your CP/M system
onto DC USER Disk [Section 2-5]

Step 7. Run QuickPac, i.e. Drive C's AUTOST.COM program which calls DCQ.COM,
DCQ.DAT, PIP.COM and XDIR.COM, to test Drive C installation. [Section 2-6]
If you have problems here, trouble-shoot with (Section 2-7]

Step 8. If you have a Centronics parallel printer, turn off power, reconnect your
printer cable, rerun QuickPac [Section 2-8]
If you have problems here, trouble-shoot with [Section 2-9]

Step 9. Put your version of CP/M onto DC USER Disk using SYSGEN [Section 2-10
Step 10. Check the setup of your DC USER DISK using SETUP.COM [Section 2-10]
Step 11. Test your entire installation by printing PRN.TST from the Drive C unit
using PIP.COM and your version of CP/M [Section 2-11]
If you have problems here, trouble-shoot with [Section 2-12]

The Trouble-shooting Sections (2-7, 2-9 and 2-12) were written to give you the
ability to easily correct the most common installation problems.

If you run into trouble, make sure you go through the detailed installation
procedure step-by-step. 99 times out of 100 you can fix just about any problem you
might encounter very quickly without calling Drive C for help.
Fitting Drive C To Your Needs

CORTERTS

3-1 THE AUTOMATIC APPROACH
3-2 THE MANUAL APPROACH
3-3. USING IT BOTH WAYS

Your Drive C software is very comprehensive. It has been designed for Osborne
owners of all levels of experience, from the first time enthusiast to the
professional programmer. If you are a beginner, you'll find it easy to understand
and simple to use. If you're an old pro, you'll find it versatile and powerful.

Similarly, your Drive C can enhance any application. This section is a brief
overview of how the different Drive C software features can be used. As you learn
about your Drive C in the rest of the manual, you might keep in mind which features
best fit your needs.

3-1 «THE AUTOMATIC APPROACH

QuickPac is the easiest way to use your Drive C. The QuickPac program can install
ALL of the Drive C features, copy files from one or both of the floppy diskettes in
your disk drives onto Drive C and run a program simply by pressing the <RETURN> key.

If you are a relatively new user we suggest you use QuickPac. The QuickPac
Installation program is menu-driven and requires no technical knowledge. It lets
you configure QuickPac to automatically install Drive C with the features you need
each time you start your Osborne.

QuickPac has the unique feature of remembering if it has copied files onto your
Drive C so that if you press the RESET button, QuickPac will re-install the Drive C
features you've chosen (like a new drive name or the Print Buffer) without recopying
files.

If you're a more experienced user who does the same procedures on a regular basis
(like loading your accounting or data base program each day), you'll find it very
convenient to setup and use QuickPac to automatically configure your system. The
QuickPac Installation program creates a data file which QuickPac uses to find out
which Drive C options you want to install (for instance, what program to run).

If you routinely use several programs, you can create a different QuickPac setup for
each diskette set. As an example, one QuickPac setup might rename Drive C to drive
3, copy WordStar and your document files onto your Drive C unit and run WordStar
automatically. A different QuickPac setup might copy your accounting data files
onto Drive C and run your General Ledger program from your floppy disk.

Finally, if you're an experienced Osborne owner working with an inexperienced user

(for instance, a new employee), you might want to setup QuickPac to automatically
configure your system for frequently required jobs.

39

| Ni ae
>.

de Fitting Drive C To Your Needs
¥)

3-2 ‘THE MANUAL APPROACH

The Drive C commands have a very simple structure. ALL the Drive C features can be
installed manually with a one-line statement (maximum length - 9 characters plus
<RETURN>). If you do many different operations with your Osborne or if you are a
programmer, you'll probably find it more convenient to use Drive C manually.

Because the Drive C commands are simple and short, you can put many alternate
Drive C commands on your function keys. For instance, one function key might
install Drive C as drive A: with the Dynamic Print Buffer. A second function key
might install Drive C as drive C: with a 16K Fixed Print Buffer.

THE DCA program (ARCHIVE and RETRIEVE) can store and reconstruct the contents of
Drive C, including files larger than the capacity of a floppy disk. DCA is also
much faster than the standard QuickPac file copy function, which uses PIP.

Storing commonly used sets of files onto an Archive diskette set can be a very
efficient way to use Drive C. The RETRIEVE portion of DCA can be used automatically
so that a single function key will load an Archive set onto Drive C quickly. You
could, for example, make one function key give the command: DCA R B<CR> which
retrieves the contents of the Archive set in drive B: onto the Drive C unit.

40
Sa ae

» |
Fitting Drive C To Your Needs és
4

3-3 USING IT BOTH WAYS

Finally, the most powerful way to use your Drive C is with a combination of
techniques. QuickPac can be started manually by using the DCQAUT command rather
than Autostart. By creating different QuickPac data files for different diskette
sets, you can use QuickPac with your function keys to easily perform complex
routines when you need them.

The remote RETRIEVE command, DCA R B, can be run automatically as part of QuickPac
so that a single function key can start QuickPac and rapidly load new files onto
Drive C using RETRIEVE and Archive sete.

QuickPac can also be custom configured much like a complex Submit file.
Instructions for creating custom QuickPac setups are included in the appendices,

If you are an experienced user, the combination of function keys, QuickPac and DCA

(ARCHIVE and RETRIEVE) will offer you almost unlimited flexibility for using Drive C
with your Osborne 1.

4l

a

, CP/M Tutorial

4-1 OPERATING SYSTEMS

4-2 FORMATTING DISKS

4-3 PUTTING CP/M ON DISKS USING SYSGEN
4-4 FILES AND DIR

4-5 XDIR

4-6 RENAMING FILES

4-7 COPYING FILES WITH PIP

4-8 ERASING FILES

4-9 CP/M ERROR MESSAGES

Many Osborne owners have successfully used their Osborne 1 without learning about
CP/M, the Osborne 1's operating system

If you've never learned to use PIP or DIR or ERA, the following is an easy-to-use
tutorial for using CP/M.

It is essential that you become familiar with a few basic CP/M commands if you are
to use your Drive Cg efficiently and productively. This tutorial will guide you
step-by-step through a number of these commands.

If you have a single-density Osborne, you will need a COPY of your CP/M System
diskette. If you have a double-density Osborne, you will need a COPY of your CP/M

System and Utility diskette.

This diskette will be referred to as the CP/M SYS DISK. The CP/M SYS DISK must NOT
be Write Protected (it should NOT have a tab on it).

You will also need a new, UNformatted diskette. Please label the UNformatted
diskette TEST DISK.

Your Drive Cg, although mechanically installed, will not be used yet.

42
CP/M Tutorial

4

4-1 OPERATING SYSTEMS

Your computer is a combination of HARDWARE and SOFTWARE.

Osborne 1 itself. Software are the programs that run oa the hardware.

you use like WordStar are called APPLICATION programs.

tasks you originally bought your Osborne for, like word processing.

The hardware is the

The programs

They perform the specific

Different computer manufacturers do not design their hardware exactly alike. The
authors of software want their programs to run on as many kinds of computers without
rewriting their programs for each specific machine.

A method was needed that allowed one version of a program to run on many different

kinds of hardware.

Similarly, the manufacturers of peripheral equipment, like printers and monitors,
want their products to work on many different kinds of computers.

A special kind of software has been developed to solve these problems.
software is called the OPERATING SYSTEM.

This special

Picture the operating system software as a buffer between the hardware on one side
and the peripherals and application programs on the other.

Operating
‘System

Butter

Sottware & Peripherals

The side of the buffer that the peripherals and the application programs see always
looks the same, regardless of the type of hardware.

The side of the buffer that talks to the hardware is adjusted by each manufacturer

to work with his specific hardware.

The result 4s that many different brands of hardware using this operating system
look EXACTLY alike to the people who write application programs and build peripheral

equipment.

43
Re eee
Sc CP/M Tutorial

This buffer, the operating system, is obviously very useful. The operating system
you have on your Osborne 1 is called CP/M and is used on many different machines.
Because CP/M is so popular, a great number of application programs are available
that will work on any CP/M equipped computer. Such a wide selection of software is
a major advantage for the Osborne owner.

CP/M must be available so that your application program (like WordStar or SuperCalc)
can work with your hardware, the 01. CP/M, however, is not permanently stored on
your Osborne. Each time you turn power on or press the RESET button, CP/M must be

reloaded into your Osborne.

After turning on your Osborne or pressing the RESET button, a message appears on
your screen asking you to insert a diskette in drive A: and press <CR>. This
message 1s permanently stored in the computer.

When you press <CR>, CP/M is loaded into your Osborne from the diskette in drive A:.
The A> on the screen telle you that CP/M has been successfully loaded.

Your CP/M System and Utilities diskette is NOT the source of CP/M. It simply
contains useful CP/M utility programs.

The CP/M operating system is stored in a reserved area on your diskettes called the
SYSTEM TRACKS. Each of the application program diskettes (like WordStar) that came
with your Osborne has CP/M already stored on its system tracks.

CPIM is stored on

a reserved area on
your diskette called
the system tracks.

When CP/M is placed on a diskette, it is automatically located on the system tracks.
Nothing else but CP/M can be put on the system tracks, so putting CP/M on a diskette
does not waste precious disk data space.

ANY diskette can have CP/M on it and it is wise to put it on every diskette you use
just after you have formatted it.

44
CP/M Tutorial

al

4-2 FORMATTING DISKS

A new, blank diskette must be formatted before your Osborne 1 can use it.
Formatting prepares the diskette ao that data can be written on it and read from it.

Press the [RESET] button.

cP/M SYS DISK A: B: TEST DISK
ASM COM UNformatted
AUTOST COM

COPY +COM

DDT +COM

DUMP +COM

ED «COM

HELP -COM

LOAD -COM

MOVCPM -COM

PIP -COM

SETUP -COM

STAT -COoM

SUBMIT +COM
SYSGEN COM
XDIR -COM
XSUB +COM

Press <CR> to load CP/M. The A> should appear on your screen.

If you have AutoStart on your CP/M Systems and Utilities diskette, the flying "0"

will appear on your screen followed by a Help menu. Presa <ESC> and the A> will
appear on your screen.

The A> is called the 'A' prompt. A> means that your 01 will look for data and
programs on drive A:. You are LOGGED onto Drive A:. Later, when you log onto drive

B;, you’il see a B> on the screen to let you know that you're looking at drive B:
instead of drive A:.

45

a >
( Bs CP/M Tutorial

IF YOU HAVE A SINGLE-DENSITY O1:

Run FORMAT from A:

Follow the menus to format the diskette in B: Single-density.

IF YOU HAVE A DOUBLE-DENSITY 01:

Follow the menus to format the diskette in B: Double-density.

This completes formatting. Any new diskette must be formatted before you use it.
You're now ready to use your formatted diskette for learning about CP/M.
NOTE: The “Copy Diskettes” option of COPY will automatically format a diskette but

it will also transfer all of the files from one diskette to another whether you want
them or not.

46
eee
CP/M Tutorial ps

4-3 PUTTING CP/M ON DISKS USING SYSCEN

CP/M SYS DISK A: B: TEST DISK

SYSGEN +COM

Formatted, blank
without CP/M

The SYSGEN program is used to place CP/M onto each diskette's system tracks. Sysgen
makes a copy of CP/M from a diskette that already has CP/M on its system tracks.
This copy of CP/M is stored in the Osborne memory and can then be put on the system
tracks of a different diskette.

Osborne 1
MEMORY
Sysgen copies CP/M Sysgen copies CP/M
from the system tracks trom the 01 memory
of the source diskette onto the system tracks
into the 01 memory. N CPIM of the destination diskette.
Source Destination

al
= P
o— CP/M Tutorial

The A> ('A' prompt) is still on the screen so you can access any program on the CP/M
System and Utilities diskette in drive A:.

Run SYSGEN from A:

This step loads CP/M into the Osborne memory from the system tracks on the diskette
in drive A:.

<CR>

This step copies CP/M from the Osborne memory onto the system tracks on the diskette
in drive B:.

If you wanted to SYSGEN (it's also a verb) another diskette, you could now replace
one of your diskettes and again direct CP/M from the Osborne memory to the new
diskette by typing 'A' or 'B'.

Instead, press <CR> to terminate SYSGEN and the A> will appear, ready for your next
instruction.

cP/M SYS DISK AS B: TEST DISK

Formatted, blank
with CP/M

48
a
CP/M Tutorial |

Press the [RESET] button,

Press “ (QUOTATION MARKS) to load CP/M. The A> should appear on your screen.
Pressing the " (QUOTATION MARKS) instead of <CR> to load CP/M is an optional feature
of your Osborne. It lets you load CP/M from the RIGHT-HAND floppy drive which is
then named A: instead of the usual B:. This is useful if your LEFT-HAND drive is
not working properly.

ce/M SYS DISK B: A: TEST DISK

Formatted, blank

=p Pl with CP/M
(PS = are)
7° FS

ANY diskette that you prepared using SYSGEN will allow you to load CP/M into your
Osborne. You don't have to (and SHOULDN'T) use the master diskettes that Osborne
Corp. supplied.

Press the [RESET] button.

Press <CR> to load CP/M. The A> should appear on your screen.

If you have AutoStart on your CP/M Systems and Utilities diskette, the flying “O"
will appear on your screen followed by a Help menu. Press <ESC> and the A> will
appear on your screen,

CP/M SYS DISK A: B: TEST DISK

Formatted, blank
with CP/M

49

Ny CP/M Tutorial

4-4 FILES AND DIR

DIR<CR> Run DIR from A: onto A:

A list of the files on the CP/M System and Utilities diskette in drive A: will
appear on the screen. FILES are the different pieces of software on a diskette.
Programs and data and WordStar documents are all files.

The files are listed in columns, with a file name (the FILE NAME) followed by
(usually) another three letters (the FILE EXTENSION). DIR does NOT list the files
alphabetically.

DIR is the built-in DIRECTORY command, a straightforward listing of the files on the
diskette. Much can be learned by studying the DIR screen display.

The first thing to note is that there is no file in the listing called DIR. How did
the Osborne know to respond to the command DIR?

DIR is automatically loaded and available when you load CP/M. Several other built-
in commands like DIR will be explained in this tutorial.

There are a few simple CP/M rules regarding the file names on the DIR screen
display. The necessary way to name a file is FILENAME.FILEEXTENSION. DIR doesn't
show a period (.) between the FILE NAME and the FILE EXTENSION but any time you
explicitly call a file (for instance, in WordStar) you must type it exactly
(FILENAME . FILEEXTENSION) «

The FILE NAME can be no more than eight letters long. The FILE EXTENSION that
follows the name can be up to three letters in length.

The FILE EXTENSION tells the computer what kind of file it is. You can use these
three letters to usefully organize different kinds of files on your diskette.

This tutorial is being drafted with WordStar and has the name CPMTUTOR.DOC (for
DOCument). When WordStar saves this file, it automatically creates a copy of the
file as it was previously, before editing. If a mistake exists in the current
version, the previous version is still available for reference.

WordStar BACKS UP (makes a copy of the old version) and automatically names the
original file CPMTUTOR-BAK (for BAcKup). Although there are now two files on the
diskette named CPMTUTOR the Osborne has no diffficulty telling them apart because
one is a .DOC type file while the other is a .BAK type file.

Finally, you'll notice an A: before each file name. This means that the file is on
the diskette in drive A:. CP/M always refers to the disk drive by the letter (in
this case A) followed by a colon (:). When you want to tell your Osborne 1 to use a
drive (LOG ON) or look for data on a drive, you name the drive with its letter
followed by a colon.

CP/M Tutorial

tal

When you typed DIR you did not refer to a drive name. CP/M assumes the drive name
of the drive you are logged onto UNLESS you name a different drive. Right now
you're logged onto drive A:. The A> below the directory tells you explicitly the
name of the drive on which you're working.

Log onto drive B:

The light will flash on the B: drive and the B> appears on the screen. You're now
logged onto drive B:.

: cP/M SYS DISK A B: TEST DISK

Formatted, blank
with CP/M

Run DIR on B: from B:

The B: prompt

DIR was run from drive B:. It listed the files on the blank diskette in drive B:
since you were logged onto drive B: (the B>). Please note that DIR does NOT tell
you whether CP/M is on the blank diskette's system tracks.

2<CR> Log onto drive A:

Again, by logging onto drive A: and running DIR, the directory of the logged on
drive, At, appears on the screen.

ing the drive designators A: and B: can dramatically improve your efficiency.
Run DIR on B: from A:
No files are listed
The A: prompt
DIR was run from A: but directed to look at B:. This is a standard CP/M convention.

51

—
Ns CP/M Tutorial

The general rule is:

THE PROGRAM NAME followed by a SPACE followed by the DRIVE NAME.

DIR A:<CR> Run DIR on A: from B:

The directory of drive A: will appear on the screen even though you're logged onto
Bs.

Let's take a closer look at using the names of the files.

Run DIR on A: from A: only on files
starting with 'S'

The directory displays only those files that start with the letter S.

The '*' (WILDCARD) is a simple but very powerful tool. You can use it to say "I
don't care". In this case, you told your Osborne "Tell me about all the files on
drive A: that start with the letter S. I don't care about any other letters in the
FILE NAME and I don't care what kind of file it is (the FILE EXTENSION).” CP/M
looks at the FILE NAMES and the FILE EXTENSIONS separately so you need two asterisks
("*"), one for each side of the period (.).

The '*" can help you organize your diskettes. You could name all your text files
with a special FILE EXTENSION like .DOC for DOCument. To find the text files
without searching through all the file names on the diskette, you would type the
command: DIR *.DOC<CR>. The directory would show all the files with the FILE
EXTENSION .DOC (the DOCument files) regardless of the FILE NAME.

52
CP/M Tutorial | >

ty

4-5 XDIR

DIR is very useful and is 'free' since it doesn't occupy any diskette space.
However, it lacks some features that would make it even more useful, A special
directory program which has these extra features was supplied with your Osborne.
This program is XDIR.COM, the EXtended Directory.

The FILE EXTENSION '.COM' in XDIR.COM means command. A command file is an
application program. To use a .COM file, just type the FILE NAME and <CR> but do
not type the FILE EXTENSION '.CoM'.

CP/M SYS DISK A: Br TEST DISK

XDIR COM

Formatted, blank
with CP/M

| Run XDIR from A:

XDIR lists the files alphabetically, a real help. It also provides information
about the use of file space on the diskette. This feature is most important and is
not provided by DIR.

DIR provides the following information:

SIZE OF EACH FILE ~ Next to each file is a number followed by a 'K'. One 'K' equals
1024 bytes. This number tells you how auch space each file occupies.

XDIR therefore tells you how large each file is. Since there is a limited amount of
space on a diskette, the size is really telling you how much space the file
occupies.

SIZE - At the bottom of your XDIR screen, the SIZE indicates how large your diskette
is in K bytes.

Double-density diskettes are about twice as large as single-density diskettes. A
384K Drive (@ is exactly twice as large as a 192K Drive Ce.

USED - The total amount of space which is occupied by files plus the space occupied
by the file directory itself is how much is already USED.

SPACE - The SPACE is how much usable space is left for additional files. SPACE
always equals the SIZE of your diskette MINUS how much has already been USED.

53
Se CP/M Tutorial

The SPACE message is very important because it tells you how close you are to
filling up your diskette.

Instead of the 'NO FILE’ message that DIR gave, XDIR gives you general information
even about a blank diskette.

Please note that XDIR, like DIR, can be directed to look at drive B: while you're
logged onto drive A:.

starting with the letter S$

The '*' (WILDCARD) works with XDIR to list just the files on drive A: that start
with 'S'. XDIR always gives COMPLETE information about the diskette no matter what
files you asked it to display.

CP/M files can be either DIRECTORY files or SYSTEM files. Drive C uses a special
file, Drive C:.SY¥S, which is a SYSTEM file. DIR will not show SYSTEM files. XDIR,
however, will.

Finally, let's use XDIR as an example of another useful CP/M feature.

Log onto B;

run XDIR on B: from A:

While logged onto drive B:, you ran a program (XDIR) on a different drive (A:) by
first typing the name of the other drive (A:XDIR). This is a general CP/M rule and
gives you even more flexibility.

Log onto A:
CP/M Tutorial Ne

4-6 RENAMING FILES

You can rename your files using the built-in CP/M command, REN (RENAME).

;OM<CR> Run DIR from A: on all .COM files
that start with the letter C

cP/M S¥s DISK A: Br TEST DISK

Formatted, blank
with CP/M

The file COPY.COM is on the CP/M SYS DISK in A:.

NAMETEST . FIL=COPY . COM<CR> Change the name COPY.COM to NAMETEST.FIL
DIR<CR>| Run DIR on A:

P/M SYS DISK A: B: TEST DISK

NAMETEST .FIL Formatted, blank

with CP/M

The file COPY.COM has been renamed NAMETEST.FIL.

IN COPY .COM=NAMETEST . FIL<CR>| Change the name NAMETEST.FIL to COPY.COM

R<CR> Run DIR on A:

When using REN, the name on the LEFT becomes the new name of the file on the RIGHT.
You cannot, however, use the '*' (WILDCARD) with REN.

55
ae
[ ‘Bs CP/M Tutorial

4-7 COPYING FILES WITH PIP

You've probably used COPY to copy files from one diskette to another. COPY can only
copy ALL files rather than individual files and both the original and copy diskettes
must be the same size (density).

Run XDIR from A:

cP/M SYS DISK A: B: TEST DISK

Formatted, blank
with CP/M

PIP +COM

On your CP/M SYSTEMS DISK is a utility program called PIP.COM.

PIP can copy individual files and groups of files from one diskette to another.
Since your disk space is limited, it's very helpful to be able to copy only those
files that you need.

‘P_B:=A:XDIR.COM[V<CR> Copy XDIR.COM onto B: from A:

‘A' prompt

Your Drive Select lights will go on and your disk drives will whirr, just like when
you COPY.

MIDIR B:<CR> Run XDIR on B: from A:

The diskette in drive B: is no longer blank. Somehow PIP placed a copy of the file
XDIR.COM on the B: diskette.

cP/M SYS DISK A: B: TEST DISK
XDIR COM
sue [ss | rere)

56
SEER
CP/M Tutorial Ne

The PIP command at first glance appears very complicated.

up into small parts.
THE PIP COMMAND: A>PIP B:=A:XDIR.COM[V<CR>

PIP

XDIR.COM

Iv

It isn't if you break it

Since PIP.COM is a '.COM’ file,
it is used by typing ite name, ‘PIP’

The drive where you want to
‘put’ the copy is always typed
FIRST, on the LEFT.

The drive you 'get' the copy is
always typed SECOND, to the RIGHT

The '=' ALWAYS separates the
SOURCE of the copy on the RIGHT
and the DESTINATION for the copy
on the LEFT

The name of the file to be
copied. This must be EXACT.

A phrase that should be added to
the end of a PIP command to
"verify' that the copy is
without mistakes

Copy the files starting with 'S'
onto B: from A:

Run XDIR on B: from A:

ce/M SYS DISK A: B: TEST DISK

ASM -COM SETUP +COM
AUTOST -COM STAT COM
COPY «COM SUBMIT -COM
DDT +COM SYSGEN -COM
DUMP «COM XDIR +COM
ED COM

HELP COM

LOAD +COM

MOVCPM COM

PIP +COM

SETUP «COM

STAT -COM

SUBMIT -COM

SYSGEN -COM

XDIR «COM

XSUB COM

57
Reg ta ieee
Ny CP/M Tutorial

PIP can use the same ‘*' (WILDCARD) convention as XDIR. This command copied ALL
files on A: that started with the letter 'S' onto B:.

PPIP<CR>: Run PIP from A:
The PIP symbol

When just the name PIP is typed, the PIP prompt '*' appears on the next line. This
‘*' is not the same as the '*' (WILDCARD) which indicates "I don't care”. Both '*'s
can be used in the same line without confusion.

The PIP '*' is used so that you do not have to constantly load PIP to copy a series
of files. As long as the PIP '*' is displayed, PIP is loaded and ready to use.

“As COPY . COM{ V<CR> Copy COPY.COM onto B: from A:
HELP . COM[V<CR>. Copy HELP.COM onto B: from A:

When you are finished with the PIP '*', type “C to clear PIP and return to CP/M.
You can also clear PIP and return to CP/M by typing <CR>.

*¢ to clear PIP
"A' prompt

Run XDIR on B: from A:

B: TEST DISK
COPY +COM
HELP -COM
SETUP -COM
STAT COM
SUBMIT COM

SYSGEN -COM
XDIR «COM

The '*.*' includes ALL files and is the duplicate of the COPY command. This command
copies ALL the files from A: onto B:.

58
Se
CP/M Tutorial | Be

IR_B:<CR> Run XDIR on B: from A:

cP/M SYS DISK

ASM
AUTOST
COPY
DDT
DUMP
ED
HELP
LOAD
MOVCPM
PIP
SETUP
STAT
SUBMIT
SYSGEN
xDIR
XSUB

PIP replaced the files on B: that had the same name.

-COM
COM
+COM
+COM
-COM
«COM
+COM
+COM
«COM
-COM
-COM
«COM
+COM
COM
-COM
+COM

TEST DISK

ASM

AUTOST

COPY

DDT

DUMP
ED
HELP
LOAD
MOVCPM
PIP
SETUP
STAT
SUBMIT
SYSGEN
XDIR
XSUB

the destination disk that have different names.

Therefore, you must have enough space available on the destination disk to
XDIR can always tell you how much space is
left on the destination disk and how much space the files you are copying will

accomodate the files you are copying.

require.

«COM
«COM
COM
COM
«COM
«COM
COM
«COM
+COM
-COM
COM
-COM
+COM
-COM
COM
+COM

PIP does NOT replace files on

59
a ae
Bx CP/M Tutorial

4-8 ERASING FILES

If there isn't enough room on the destination disk, you may want to make room by
ERASING a file.

SERA B:HELP.COM<CR> Erase HELP.COM on B:
The ERA (ERASE) command is a CP/M Utility like DIR. It is always available.
Erase files starting with 'S' on B:
The '*' (WILDCARD) can be used with ERA just as it's used with DIR.
CP/M SYS DISK A: BE TEST DISK
ASM COM
AUTOST — .COM
copy COM
DDT -COM
DUMP COM
ED +COM
LoaD COM
MOVCPM = «COM
PIP COM
XDIR COM
XSUB -coM

Erase ALL files on B:

ERA makes sure that you REALLY want to erase ALL the files on a diskette by asking
explicitly for a Yes or No answer.

The TEST DISK in B: is now blank.

cP/M SYS DISK At B: TEST DISK

Formatted, blank
with CP/M

CP/M Tutorial

4-9 CP/M ERROR MESSAGES

cP/M will display error messages if the diskette you are trying to use cannot be
accessed for some reason.

Some common error messages and the reasons for the errors are:

Unformatted diskette on drive _
Bdos Err Gn _: Select

The diskette is not yet formatted.

The diskette is formatted double-deasity but your CP/M System is
single-density.

The drive is not ready, i.e. the drive door is not closed completely, no disk
in the drive.

‘NO SPACE

CP/M message when there is not enough space on a logical drive for the file you
are trying to copy.

Bdos Err On _: File R/O
CP/M message when trying to erase or to write over a Read-Only (R/O) file.

Bdos Krr On _: Bad Sector

CP/M message caused by a data error on either floppy disk or Drive C. Can be
caused by 1) hardware failure of Ol disk controller or drive, 2) bad
diskette, or 3) hardware data error on Drive C unit.
DISK WRITE ERROR: =FILENAME .FILEEXTENSION
PIP message when copying a file and there is not enough space on the disk.
To EXIT from the Error conditions listed above:
These errors will usually cause CP/M to “hang up", i.e. CP/M will not return to the
A>. You must place a formatted disk in the drive and properly close the door of the
drive specified by the Bdos Error message. Then press “C to return to the A>.
Bdos Err On _: Select
If this message is displayed by itself, a non-existent drive was specified.
You may get this error if you try to access Drive C without running DCL first.
You will have to press the RESET button to EXIT from this error condition.

This completes the section on CP/M basics.

61
Learning Drive C Skills

USING THE RAM-disk
USING THE PRINT BUFFER
USING THE Drive C UTILITY PROGRAM

This section of the manual teaches you how to use the individual features of the
RAN-disk and Print Buffer, as well as DCU, the Drive C Utility program.

Your Drive C has many powerful yet easy-to-use features. The exercises in this
section will familiarize you with how each one works.

Each feature can be run using a simple command. Once you find which features best
fit your needs, you can use them automatically.

The Drive C RAM-disk is installed on your Osborne as a third logical drive with a
single command, DCL. Variations of the DCL command will install Drive C with a new
drive name and also install the Print Buffer. ALL of the Drive C features can be
installed with a one~line DCL command statement.

Your Drive C and floppy drives can be renamed at any time using the DCN command.

Eight different sizes of Fixed Print Buffer and a variable Dynamic Print Buffer can
be installed with your RAM-disk. Once installed, the Print Buffer feature works

automatically.

The DCU Utility program can be used to increase the flexibility of your Print
Buffer.

DCU E is a special feature which allows you to erase the contents of the Drive C
RAM-disk without affecting the Print Buffer.

62
r,
Using The RAM-disk \e

»*

5-1 GETTING READY

5-2 INSTALLING THE RAM-disk

5-3 COPYING FILES ONTO THE RAM-disk

5-4 SAVING FILES FROM THE RAM-disk TO FLOPPY

5-5 INSTALLING THE RAM-disk AS DRIVE A:

5-6 INSTALLING THE RAM-disk WITH DIFFERENT DRIVE NAMES
5-7 Drive C AND THE RESET BUTTON

5-8 RENAMING THE RAM-disk AFTER INSTALLATION

5-9 RUNNING WORDSTAR ON Drive C - DOING IT MANUALLY

5-1 GETTING READY

Before starting the step-by-step instructions for using your Drive C, you will need
another blank, formatted diskette.

This diskette should be labeled “DC DEMO DISK” and will be used for your learning
exercises.

Format the DC DEMO DISK double-density unless you have a single-density Ol.

Turn ON power to your computer.

B: CP/M SYS DISK

DC USER DISK

Drive C NOT INSTALLED

Press <CR> to load CP/M. The A> should appear on your screen.

IP A:=B:SYSGEN. COM[V<CR> Copy SYSGEN.COM onto A:,
the DC USER DISK, from B:

63
S|
[ Using The RAM-disk
4

Dc USER DISK
DC USER DISK

DCA COM,
DCL COM
Deg -COM
cq -DAT
DCQAUT —.COM
DCQINS «COM
DCU «COM
DFD -SPR
PIP COM
PRN -TST
SYSGEN «COM
XDIR COM

cP/M SYS DISK

DC DEMO DISK

Formatted, blank
Single- or Double-
Density

Drive C NOT INSTALLED

“c to clear CP/M

CP/M must be copied onto the DC DEMO DISK.

SYSGENCCR>_ Run SYSGEN from A:

Re

r
Using The RAM-disk \e

»*

\

Run PIP from A:
ICL. COM[V<CR> Copy DCL.COM onto B: from A:
FD. SPR[V<CR> Copy DFD.SPR onto B: from A:

The 'A' prompt

De USER DISK Ar B: DC DEMO DISK

(CP/M on
SYSTEM TRACKS)

DCL com
DED -SPR

DC DEMO DISK A: B: DC USER DISK

(CP/M on

SYSTEM TRACKS)
DCL COM
DFD «SPR

Drive C NOT INSTALLED

Press the [RESET] button.

Press <CR> to load CP/M. The A> should appear on your screen.

CP/M must always be loaded before loading the Drive C software. The 'A' prompt
indicates that CP/M has been successfully loaded onto your Osborne 1.

65

Sa
i
\e Using The RAM-disk
4

5-2 INSTALLING THE RAM-disk
The Drive C LOADER software (DCL.COM) must be loaded (installed) into your Osborne
before you can use Drive C.

DCL<CR> Install the Drive C RAM-disk as C:

The 'A' prompt

Drive C is now installed as the third logical drive on your Osborne, drive C:. It
can be used exactly like your floppy disk drives, drive A: and drive Bi.

Two files were necessary to install Drive C, DCL.COM and DFD.SPR. DCL.COM can be on
either floppy disk drive, but it's simplest to keep it on A:. THE FILE DFD.SPR MUST
BE ON LOGICAL DRIVE A: DURING THE INITIAL INSTALLATION OF THE Drive C RAM-disk.

DC DEMO DISK A: B: DC USER DISK
DCL +COM
DFD «SPR

DCN »COM
Drive Cz: .S¥S

The files DCN.COM and Drive C:.SYS on the Drive C unit were created automatically
when the Drive C unit was installed.

Drive C, unlike a floppy disk, does not need to be formatted to be used. Nor does
CP/M need to be placed on Drive C with SYSGEN. Once installed, Drive C looks
exactly like a formatted diskette ready to accept files.

Log onto C:, the Drive C unit
PIR<CRy Run DIR from C:

The CP/M utilities, like DIR, are available on the Drive C RAM-disk. The file
Drive C:.SYS is a SYSTEM file and will not be displayed by DIR. To check for the
Drive C:.SYS file, use XDIR or STAT.

66
er.
Using The RAM-disk ‘fe

LS

5-3 COPYING FILES ONTO THE RAM-disk

To use the Drive C RAM-disk, files must be copied onto it from the floppy disks.

The simplest way to copy files onto the Drive C RAM-disk is with a copy program like
PIP. Other programs like SWEEP or WASH can also be used.

Copy PIP.COM onto C: from B:

XDIRCCR™ Run XDIR from C:
DC DEMO DISK A: B: DC USER DISK
DCL +COM DCA -CoM
DFD «SPR DCL -coM
DeQ COM
Deg «DAT

DCQAUT +COM
DCQINS -COM

DCU ~COM

DFD «SPR

PIP «COM

c: PRN «TST

SYSGEN +COM

DCN +COM XDIR «COM
peu -COM
Drive C: .SYS
PIP «COM
XDIR +COM

The files DCU.COM, PIP.COM and XDIR.COM were copied onto drive C:, the Drive C RAM-
disk, by using the PIP command from drive B:.

Once you have copied files onto the Drive C RAM-disk, you can use these files just
as you would on your floppy disks.

By logging onto drive C: (C>), programs on drive C:, like XDIR, can be used.

67

Using The RAM-disk

5-4 SAVING FILES FROM THE RAM-disk TO FLOPPY

When your Osborne is turned OFF, the contents of the Drive C RAM-disk will not be
retained.

Files on Drive C which you want to save (backup) will need to be stored onto floppy
disks.

Again, the simplest way to copy files from the Drive C RAM-disk onto your floppy
disks is with a copy program like PIP or SWEEP.

=C DCU «COM, V<CR?. Copy DCU.COM onto A: from C:

Copy PIP.COM onto A: from C:
XDIR. COM[V<CR> Copy XDIR.COM onto A: from C:
PE =< co clear PIP

R_A:<CR> Run XDIR on A: from C:

DC DEMO DISK At B: DC USER DISK

DCL COM

peu «COM

DFD «SPR

PIP COM

XDIR COM

DCN COM
peu -COM
Drive C: .SYS
PIP «COM
XDIR +COM

The files DCU.COM, PIP.COM and XDIR.COM were first copied onto the Drive C RAM-disk,
drive C:, from the floppy disk, drive B:, using the PIP cowmand from drive B:.

The same files were then saved onto the floppy disk, drive A:, by using the PIP
command from drive C;.

Using The RAM-disk \e

aaa

r,

iN

A
DC Demo Disk

TA

To store files
onto floppy disk

B:
DC User Disk

=)

To copy files
‘onto Drive C

69
5-5

i a |
Using The RAM-disk

IMSTALLING THE RAM-disk AS DRIVE A:

The Drive C unit is installed as logical drive A: by adding the drive letter A to

the DCL command.
longer installed after pressing the RESET button but the files remain.

Press <CR> to load CP/M.

Run XDIR on A:, the Drive C unit
from left floppy, C:

70

DC DEMO DISK

DCL COM
DCU -COM
DFD -SPR
PIP +COM
XDIR «COM

EXDIR_A:<CRD)
Dc DEMO DISK
DCL -COM
pcu -COM
DED «SPR
PIP CoM
XDIR -COM

To re-install Drive C, first RESET your Osborne.

Press the [RESET] button.

ee

Drive C NOT INSTALLED

The A> should appear on your screen.

DCN

DCU
Drive C:
PIP
XDIR

-COM
+COM
»SYS
COM
«COM

Drive C is no

DC USER DISK

DC USER DISK
Using The RAM-disk Ke

F

5-6 INSTALLING THE RAM-disk WITH DIFFERENT DRIVE NAMES

The command DCL A is an example of a general rule:

THE LETTER AFTER THE DCL COMMAND WILL BE THE LOGICAL DRIVE NAME OF THE DRIVE C@#
UNIT. THERE MUST BE A SPACE BETWEEN DCL AND THE DRIVE LETTER.

DCL A will install the Drive C unit as drive A:.
DCL B will install the Drive C unit as drive B:.

DCL or DCL C will install the Drive C unit as drive C:,

After installing the Drive C unit as A:, the left-hand floppy is renamed C: and the
C> appears on the screen.

Another general rule is:

IF THE DRIVE Cg UNIT IS INSTALLED AS A: OR B:, THE FLOPPY DISK DRIVE THAT WAS
ORIGINALLY A: OR B: WILL BE RENAMED C:.

If the Drive C unit is named A:, the original A: drive
will be renamed C:.

If the Drive C unit is named B:, the original B: drive
will be renamed C:.

71
Le Using The RAM-disk

4

5-7 Drive C AND THE RESET BUTTON

The RESET button was pressed when Drive C was re-installed as A: in the previous
exercise. The files on the Drive C unit are still present after a RESET.

Log onto the Drive C unit, A:
XDIR<CR>| Run XDIR from A:

DC DEMO DISK Cz B: De USER DISK

DcL CoM

peu -COM

DFD «SPR

PIP COM

XDIR COM

DCN -COM
DCU -COM
Drive C:.SYS
PIP »COM
XDIR -COM

Drive C:.SYS, a zero K (OK), R/O (READ ONLY) file keeps the files on the Drive C:
unit when the RESET button is pressed.

In order to access the files on the Drive C: unit after pressing the RESET button,
you only need to reload Drive C using the DCL command.

Re-installing the Drive C unit with a new drive name does not affect files already
on Drive C.

72
Using The RAM-disk ‘fe.

INSTALL
Drive ¢

~ A

COPY FILES
‘ONTO Drive C

a:

PRESS
[RESET]
BUTTON

—

REINSTALL
Drive C

4

Drive C:.SYS file
is placed on Drive C.

Copy files onto Drive C
using PIP, SWEEP, QuickPac
Retrieve.

Files on Drive C are
kept by Drive C:.SYS.

Re-install Drive C as a
third drive to access the
Drive C files,

73

r Fm
[ Using The RAM-disk
y)

5-8 RENAMING THE RAM-disk AFTER INSTALLATION

The Drive C RAM-disk and the floppy disk drives can be renamed at any time using the
DC NAME (DCN.COM) program.

DCN.COM, like the Drive C:.SYS file, is created and placed on the actual Drive C
unit regardless of its logical drive name.

DC DEMO DISK

B: DC USER DISK

drive At, to Cr

he 1c" proape

The Drive C unit, drive A:, is now renamed drive C:.

Since you did not move to a different drive, DUN returned you to the drive you were
logged onto, the Drive C unit, with the NEW name, drive C:.

The C> prompt therefore appeared after changing the drive names.

14
=

=
Using The RAM-disk ‘fe.

the Drive € unit

DC DEMO DISK A: B: DC USER DISK
DCL COM
pDcU -COM
DFD «SPR
PIP -COM
XDIR «COM

DCN -COM
DCU «COM
Drive C: .SYS
PIP +COM
xDIR »COM

This is an example of a general rule:

THE LETTER AFTER THE DCN COMMAND WILL BE THE LOGICAL DRIVE NAME OF THE DRIVE Cg

UNIT.

DCN A will rename the Drive C unit as drive A:.
DCN B will rename the Drive C unit as drive B:.

DCN C will rename the Drive C unit as drive C:-

715
| a
Za
IF Using The RAM-disk

5-9 RUNNING WORDSTAR ON Drive C - DOING IT MANUALLY

You now have all the tools necessary to run WordStar on the Drive C unit renamed

drive A:.

This exercise will copy and run WordStar MANUALLY.

DC DEMO DISK A:

DC DEMO DISK

DCL -COM
DCU + COM
DFD »SPR
PIP -COM
XDIR COM

| ofc" =e aS Rae
[Bee
(UaSere “as=B:ws* #1 vce

76

c:
DCN COM
DCU -COM
Drive C: +SYS
PIP -COM
SDIR +COM

“C to clear CP/M

DISK

WordStar DISK

AUTOST -COM
INSTALL .COM
MERGPRIN .OVR
SAMPLE -TXT
ws -COM
WSMSGS -OVR
WSOVLYL -OVR:
XDIR +COM

Rename the Drive C umit to A:

Copy the WordStar files onto A:,
the Drive C unit, from B:

Using The RAM-disk

a

F

Le,

»*

The three WordStar files are copied from the floppy diskette in drive B: onto drive
At, the Drive C unit, using PIP.

DC DEMO DISK

DCL »COM
DCU +COM
DFD «SPR
PIP +COM
XDIR +COM

Bisco, worastar trom a:

Bz

AS
DCN -COM = WS COM
peu -COM  WSMSGS = .OVR
Drive C: .SYS WSOVLY1 .COM
PIP -COM - XDIR «COM

WordStar DISK

AUTOST -.COM
INSTALL .COM
MERGPRIN.OVR
SAMPLE .TXT
ws +COM
WSMSGS .OVR
WSOVLY1 -OVR
XDIR +COM

WordStar is now loaded and ready to use on drive A:, the Drive C unit.

DCL A

ws

Install Drive C
as drive A:.

Copy the WordStar files
from floppy disk
conto the Drive C

RAM-disk, drive A:

Run WordStar on Drive C

Using The RAM-disk

Press 'X' to EXIT WordStar.

The 'A' prompt

Run DCU EB (Erase) from A:

Run XDIR on A: from C:

The files on Drive G (with the exception of Drive C:.S¥S) have been erased for the
next exercise.

DC DEMO DISK c: Bz WordStar DISK

Press the [RESET] button.

This completes the section on installing the Drive C RAM-disk.

78
Using The Print Buffer

CONTENTS

5-10 PRINT BUFFER OPERATION

5-11 INSTALLING THE PRINT BUFFER
5-12 THE FIXED PRINT BUFFER

5-13 THE DYNAMIC PRINT BUFFER

5-14 USING THE DYNAMIC PRINT BUFFER

5-10 PRINT BUFFER OPERATION

The Print Buffer feature of your Drive C lets you compute and print at the same
time.

When you print a file, you can not run a program because your printer has control of
your Osborne until the printing operation is completed. Printers are slow and your
O01 can be tied up for considerable lengths of time.

The Print Buffer LOOKS like your printer to your Osborne. The print output is sent

to the Print Buffer just as it would be sent to your printer. But the Print Buffer

temporarily stores the print output at high speed while simultaneously sending it to
the printer at the printer's slow speed.

Your Osborne THINKS it has finished printing a file when all of the print output has
been transferred to the Print Buffer. The CP/M prompt or your program is available
while the Print Buffer continues to print the file.

After the contents of the Print Buffer has been printed, the Print Buffer is
automatically cleared and the space is again available for more print output from
your Osborne.

When the Print Buffer is installed, your Drive C is partitioned into two parts, the
RAM~disk and the Print Buffer.

The Fixed Print Buffer is a space solely dedicated to print buffer operation. Bight
different Fixed Buffer sizes are available:

16K, 32K, 48K, 64K, 80K, 96K, 112K, 128K

The RAM-disk will be decreased in size by the amount of space you choose to allocate
to the Fixed Buffer.

The Dynamic Print Buffer, P, does NOT allocate a specific amount of space for print
buffer operation. Instead, any space not used by the RAN-disk for files can be used
for the Print Buffer.

The Print Buffet is installed at the same time that you install the RAM-disk.

Once installed, print buffer operation is transparent. This means you can send your
print output to your printer using your regular commands and the Print Buffer will
be automatically engaged. No special commands are necessary.

719
SS

JM
\e Using The Print Buffer

4

‘
If the amount of information to be printed is larger than the space available in the

Print Buffer, the computer will print the excess amount at the same speed as if
there were no Print Buffer present, i.e. that is, it will only be able to transfer
additional data to the buffer as quickly as the printer empties the buffer.

‘Osborne 1
CPU

When the Print Buffer isn’t full, itaccepts
data much faster than the printer can print it.

‘sLOW
cewo )UUINCGDI

my

When the Print Buffer is full, it accepts data at
the SAME speed that it prints it.
5-11 INSTALLING THE PRINT BUFFER

The Print Buffer must be installed at the same time that the Drive C RAM~disk is

installed by using the DCL command.

The general rules are:

To INSTALL THE FIXED PRINT BUFFER, THE PRINT BUFFER SIZE FOLLOWS THE DCL COMMAND

WHEN LOADING Drive C.

TO INSTALL THE DYNAMIC PRINT BUFFER, THE LETTER P FOLLOWS THE DCL COMMAND WHEN

LOADING Drive C.

IF YOU USE THE RENAME OPTION WITH THE DCL COMMAND, THE PRINT BUFFER OPTION FOLLOWS

THE NEW DRIVE LETTER.

THERE MUST BE A SPACE BETWEEN THE DCL COMMAND AND THE PRINT BUFFER OPTION.

BUFFER BUFFER RAM-disk NAME |
SIZE TYPE A: Br a) |
16K FIXED | DCL A16 | DCL B16 | DCL 16 |
32K FIXED | DCL A 32 | DCL B 32 | DCL 32
48K FIXED | DCL A 48 | DCL B48 | DCL 48 |
64K FIXED | DCL A 64 | DCL B64 | DCL 64
80K FIXED | DCL A 80 | DCL B 80 | DCL 80 ]
96K FIXED | DCL A 96 | DCL B96 | DCL 96
112K FIXED | DCL A112} DCL B 112| DcL 112 |
128K FIXED | DCL A 128] DCL B 128| Dez 128
VARIABLE | DYNAMIC | DCL A P | DCL BP DCL P |

The Print Buffer is automatically removed when the RESET button is pressed. To
eliminate the Print Buffer or to change the Print Buffer, press the RESET button and
re-install Drive C with a new Print Buffer option.

81
[ Using The Print Buffer
a

5-12 THE FIXED PRINT BUFFER

The Fixed Print Buffer is installed as part of the DCL command.

DC DEMO DISK A: Br DC USER DISK
DCL COM DCA +COM
DCU -COM DCL +COM
DFD +SPR DcQ COM
PIP «COM DCcQ -DAT
XDIR «COM DCQAUT «COM
DCQINS «COM
pcu «COM
DFD «SPR
PIP «COM
Drive C NOT INSTALLED PRN .TST
SYSGEN COM
XDIR + COM

Press <CR> to load CP/M. The A> should appear on your screen.
CL A<CR> Install Drive C as A:
WITHOUT the Fixed Print Buffer

from C:
The SIZE of the Drive C RAM-disk is the SIZE displayed by XDIR. Since the Fixed
Print Buffer is not yet installed, the SIZE will be either 192K or 384K, the total
capacity of the Drive C unit. Next, your Drive C will be re-installed with the 16K
Fixed Print Buffer.

Press the [RESET] button.

Press <CR> to load CP/M. The A> should appear on your screen.

DCL A 16<CR> _ Install Drive C as A: with 16K
Fixed Print Buffer
XDIR A: <CR> Run XDIR on A: from Cs

The 16K Fixed Print Buffer is now installed. This time, XDIR shows the SIZE of the
Drive C RAM-disk to be reduced by 16K (176K or 368K).

82
DC DEMO DISK Cc: B: DC USER DISK

DCL -COM
pcu +COM
DFD +SPR
PIP -COM
XDIR -COM

DCN COM
DCU COM
Drive C: .SYS

The DC Utilities program (DCU.COM) is automatically copied onto the Drive ¢ unit
from drive A: when the Print Buffer is installed.

DCU.COM contains several powerful utilities to use with your Print Buffer. If
DCU.COM is not present on drive A: when you load the Print Buffer, the following

helpful message will appear on the screen:

Note: print buffer utility (DCU.COM) not available

83
Using The Print Buffer

Drive S

Simultaneous use

If you type an incorrect size for the Fixed Buffer, DCL 28 for instance, the Drive
C@ RAM-disk will be installed but no Print Buffer will be installed. The following
message will appear on the screen:

Bad print buffer parameter, not loaded
If you have files on the RAM-disk and re-install a Fixed Buffer which is larger than
the available space on Drive C, the Dynamic Buffer will automatically be installed
instead. The following message will appear on the screen:

Not enough space for fixed print buffer

rr, Fon!
Using The Print Buffer We

5-13 THE DYHAMIC PRINT BUFFER
The Dynamic Print Buffer is installed with the DCL command using the ‘P' option.
Press the [RESET] button

Press <CR> to load CP/M. The A> should appear on your screen.

DCL A P<CR> Install Drive C as A: with
the Dynamic Print Buffer P

PIP _A:=C:XDIR.COM[V<CR> Copy XDIR-COM onto A: from C:

PIP A:=C:PIP.COM[V<CR> Copy PIP.COM onto A: from ¢:
PIP A:=B:DCA.COM[V Copy DCA.COM onto A: from B:

XDIR<CR> Run XDIR from A:

The Dynamic Print Buffer, the 'P' option, is now installed. The Extended Directory
of drive A:, the Drive C unit, does NOT show the size of the RAM-disk to be
decreased (192K or 384K).

The Dynamic Print Buffer constantly changes size as more or less file space is used
in the RAM~disk. The Extended Directory will automatically show the RAM-disk
reduced in size ONLY when the Dynamic Buffer actually contains output for the
printer.

Dave C
SIMULTANEOUS USE

( Using The Print Buffer
4

5-14 USING THE DYNAMIC PRINT BUFFER

This exercise is a demonstration of the Dynamic Print Buffer.

PIP A:=B:PRN.TST(V<CR Copy PRN.TST from B: to A:

Make sure your printer is ON, has paper and is ready co print.

IP LST:=PRN.TST<CR> Print PRN.TST using PIP

Your printer should now be printing the Drive C Print Test. When the entire PRN.TST
file is in the Dynamic Print Buffer, the A> will reappear on your screen. You can
now continue using your Osborne just as if you weren't printing at all.

TYPE THE FOLLOWING COMMAND WHILE YOUR PRINTER IS PRINTING:

xD Run XDIR from A: while
PRN.TST is being printed

The Extended Directory shows that the size of the RAM-disk has been decreased by the
size of the PRN.TST file which is being printed by the Dynamic Buffer (if you have
an internal buffer in your printer, the PRN.TST file may have been transferred from
the Dynamic Buffer to your printer's buffer so quickly that the space was already
returned to the RAM-disk).

The Dynamic Buffer space will be available for use again as RAM-disk only when the
Dynamic Buffer has finished printing the PRN.TST file.

Please wait for your printer to stop printing before continuing with the next step.

K>XDIR<CR> Run XDIR from A: after
PRN.TST has been printed

The Dynamic Buffer is now empty and the Extended Directory will show that ALL of the
Drive C unit is again available as RAM-disk.

Again, as with the Fixed Print Buffer, the DC Utilities program (DCU.COM) is
automatically copied onto the Drive C unit from drive A: when the Print Buffer is
installed.

DCU.COM contains several powerful utilities to use with your Print Buffer. If
DCU.COM is not present on drive A: when you load the Print Buffer, the following
helpful message will appear on the screen:

Note: print buffer utility (DCU.COM) not available
Using The Print Buffer \e

1G

J

Drive C

PRINT

Dynamic Sr PER

or
RAM-disk

Dynamic Print Buffer
is installed.

Drive C

PRINT

Dynamic BUFFER

or
RAM-disk

oe
UOT

Dynamic Print Butter
in use.

Drive ©

PRINT

Oynamic BUFFER

or
RAM-disk

Dynamic Print Buffer has
finished printing.

The Print Buffer space
that was used for printing
can again be used for either
the Dynamic Print Buffer
or the RAM-disk.

87
F, Ke
Using The Drive C Utility Program

CONTENTS

5-15 DCU - THE Drive C UTILITY PROGRAM

5-16 USING DCU S - THE SPACE OPTION

5-17 USING DCU 0 - THE OPTIMIZE OPTION

5-18 USING DCU TO CONTROL THE Drive C PRINT BUFFER
5-19 USING DCU WITHOUT THE MENU

5-20 DCU E - ERASING THE RAM-disk

5-15 DCU - THE Drive C UTILITY PROGRAM

DCU.COM, the Drive C Utility program, provides a number of powerful features to use
with your Print Buffer.

(<C> NNN es vc rom a:

Typing the command DCU will display the DCU menu on the screen.

The type and current status of the Print Buffer will always be displayed at the top
of the screen.

The TYPE indicates whether the Print Buffer is Fixed or Dynamic. If the Print
Buffer is Fixed, TYPE will show the size of the Fixed Print Buffer.

If you do not install the Print Buffer, the TYPE line will be blank.
TYPE Messages
K fixed buffer - Size of Fixed Print Buffer

dynamic - Dynamic Print Buffer P
(BLANK) - Print Buffer NOT installed
7

Using The Drive C Utility Program \e
i v)

The STATUS indicates the current condition of the Print Buffer.
STATUS Messages
normal - installed

NOT INSTALLED - Print Buffer NOT installed
**eWAITING** - Print Buffer has been interrupted

89
7m
\e Using The Drive C Utility Program

4

5-16 USING DCU S - THE SPACE OPTION

The SPACE option 'S' shows how much space is available for use as the Dynamic
Print Buffer.

Please note the amount of SPACE available before returning to CP/M.

The 'X' option returns you to CP/M.

The 'A' prompt

The Extended Directory shows that more space is left on the Drive C unit than the
DCU SPACE option indicated.

There is a good reason for the difference between the amount of space left on Drive
C as shown by XDIR and how much space is left for the Dynamic Print Buffer as shown

by the DCU SPACE option.

The boundary between the Dynamic Print Buffer and the RAM-disk is defined by the
‘last’ file in the RAM-disk. CP/M, however, does not keep the files in the RAN-disk
tightly ‘stacked’ together.

Gaps may exist in the ‘stack' of files in the RAM-disk. These extra spaces cannot
be used by the Dynamic Print Buffer but are included in the space available shown by
XDIR.

The DCU SPACE command will accurately tell you how much space is available for the
Dynamic Print Buffer.
Using The Drive C Utility Program

RAM-disk

Drive ©

AVAILABLE SPACE
FOR THE DYNAMIC
PRINT BUFFER

DCU S tells you how much
SPACE is available for
the Dynamic Print Buffer.

The boundary between the

bg RAM-disk and the available

SPACE for the Dynamic
Print Buffer is determined
by the last file in the RAM-disk.

XDIR includes the GAPS
in the stack of files which
cannot be used
as space for the
Dynamic Print Buffer.

The DCU SPACE option will tell you how much space the Dynamic Print Buffer has (IF
IT IS INSTALLED) or would have (IF YOU RESET AND INSTALLED IT).

PLEASE NOTE THAT THE DCU SPACE OPTION WORKS EVEN IF THE FIXED BUFFER IS INSTALLED OR
IF NO PRINT BUFFER IS INSTALLED.

2
i
\a.

Using The Drive C Utility Program

5-17 USING DCU O - THE OPTIMIZE OPTION

The DCU O (OPTIMIZE) option packs (compresses) the RAM-disk files to eliminate the
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

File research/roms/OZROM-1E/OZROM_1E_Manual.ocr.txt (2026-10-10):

--- page page-01.png
THE O2ZROM 15E
A REPLACEMENT ROM FOR THE OSBORNE 1 COMPUTER
Copyright (C>) 1984 Micro Management, Inc.

GUARANTEE: If you are not completely satisfied with
the OZROM 1E, return it and the accompanying documentation
in reasonable condition within thirty (30) days of: purchase,
and we will refund the purchase price of this product to
you. Proof of purchase required for refund. ve —

WARRANTY : Should the product fail to function due to
electrical or mechanical failure during the first 90 adsys
after purchase, Micro Management, Inc., will replace it fre¢
Cand pay the return shipping charges, if necessary), pro=
vided the defective product is returned with proof of pur-
chase within 100 days of the purchase date. Should the
product fail to function due to electrical or mechanical:
failure after the warranty period, return it to Micro Man<
agement, Inc., with $25.00 and we will replace it. Changes
in the OZROM 1E or documentation may be made without notice.

LIMITATION OF LIABILITY: This product is intended for
use in. accordance with the attached documentation only.
This product is not intended for any other use. It is the
purchaser’s responsibility to determine the suitability for
a particular application.

Micro Management, Inc., shall not be liable for loss or
damage caused, or alleged to be caused, directly or in-
directly by the OZROM 1E or any other computer equipment or
programs sold by Micro Management, Inc., including, but not
limited to, any interruption of service, loss of business,
or anticipatory profits of such computer equipment or compu-
ter prograns.

The preceding statements of warranty and limitation of:
liability are in lieu of all other warranties, guarantees,.
or theories of liability, expressed or implied, including
warranties of merchantability or fitness for a particular
purpose. pa

COPYRIGHT: This manual and accompanying. programs,
including the OZROM 1E, are copyrighted. Purchaser receives
a non-transferable, non-exclusive, personal license to use
the copyrighted materials for their intended purposes. The
materials may not be copied or sublicensed without prior
written consent from Micro Management, Inc., with the excep-
tion that the purchaser may make a copy of the manual and
software for use on his own systen.

Trademarks and Tradenanes: Osborne 1: Osborne Compu-
ter Corporation. WordStar: MicroPro International Corpora-
tion. DBase II: Ashton-Tate. SuperCalc: Sorcim. CP/M:
Digital Research, Inc. Apple: Apple Computer, Inc. SMART~
KEY: Heritage Software, Inc. Manual Rev. A 84/09/01

P.O. Box 165383 Irving, TX 75016 214/256-1960
--- page page-02.png
--- page page-03.png
The OZROM 1E

TABLE OF CONTENTS

What you gain with the OZROM IE ..... cee cer vecevce
What you lose with the OZROM IE .....ccevescvvcceces
BEFORE YOU BEGIN ..... cece cc ccc crn nsec rec cceveseees
Things to remember 2... cw ccccccrcvvcsesseccessessece
FEATURES 2... ccc ccc cece erence cece esse sees eeeescsesens
A blinking CUrSOYr 2... cccccecccccsesncesvessace
A more complete ASCII keyboard .......ccccecees
MyKey -- A redefinable Keyboard .......ccecee0.
MyKey II -- New function Keys .......cccvecsces
Immediate control over system parameters ......
No more parallel port paralysis ......eeceecees
Print your SCKEEN ...cceeccccerevvveveveveveces
Control your printer .. cc eeccccccvcrsvveeseccecs
Time-of-day CLOCK .cccccscccvcvvccccccesereveece
True Clear“SCLEeN 2... cerrecevrvrccccrvvseesevrecece
System crash damage protection .....ccccsessece
A system memory tester ...cccccccnsssvssccceee 10
1200-baud modem operation considerations ..... 11
Additional display control codes ........ee566 $1
"Booting" with the left/right arrow Keys ..... 12
SUPPORT PROGRAMS ...cceccrvvvcccvccveresevece veoeveee 13
MEMORIZE ....ccccccccccvvvvccvcccccccssseseeses 1S
Autostarting with MEMORIZE ......ccccccccsecee 14
TIME ........2. ecm w meme were nner acccccscssssssee 14
ALARM and TIMER eeeevrereereeereeerereeeesevee eevee eereereer eee @ 15
QUIKTIME, CRASH, and SHOW eecrerrevoevoevreveev evr ee eee ee 16
The OZPATCH system patcher .....cccvcvevevveee ITZ
The FK function Key programmer ....ccccccece00 19
The SET util lty cn. cwvvevevvevcvcvveveveesesee af

WOWVUA SCO TWAWWWND ==

APPENDICES
Program PatCheS ...ccccwssccccccccccvvvcccceccescccse Am]
A smoother, faster-scrolling WordStar ....... A-I
A fix for dBase II function Key operation ... A~3
Installing your OZROM 1E ow. ccc cece ccc een r ess nvee Bal
Technical information on the OZROM IE ....-cceeees CHl
Differences between the OZROM 1E and others . C-1!
Truer Televideo 912/920 operation .......222.. C=2
An interrupt hook for programmers ........++. C=2
1793/1797 floppy disk controller operation .. C=-3
Control-shift-Key notes ...ccccccesceneseceee OFS
Damage protection, NZCPR, and CRC checking .. C=-4
The OZROM 1E memory map ..ccccccccceresvecees CH§
The ROM jump table ....ccecccccccccvseccevees CMB
The OZROM IE Keytable ......ccceeveccevevvves CMT
ROM e@€rror COdES ..ccernscccncccsasnsscsescessssese Dol
ASCII table ... ccc ccc ccc cece r neers ven scveseesesese Emi
A quickie control-shift-key reference table ...... E=-2

INDEX eeoeseeveveeneoeoeeeeeeeneoevreeeeeeeeeesennee The Last Page
--- page page-04.png
--- page page-05.png
The OZROM 1E

WHAT YOU GAIN WITH THE OZROM IE:

User-selectable blinking cursor, keyclick and display
of system clock.

A software-redefinable keyboard -~ individual keys can
be redefined almost anytime, even right in the middle of
most programs -- in any program that requires user input.

Eight locally-redefinable functions, similar to the
regular function keys, which can be assigned to any regular
key, or shift- or control-key combination. Each can be up
to 63 characters long.

Local, immediate control over system parameters through
the use of control-shift-keys: you can toggle scrolling,
clock display, cursor blink, and Keyclick; you can select
between 52-, 80-, or 104-column display (with the Osborne
Screen=-Pac); you can free your computer from the “Centronics
printer not connected" lockout (double-density operating
systems only) you can toggle easily between the left 52
columns and the right 52 columns of an 80-column display if
you don’t have an 80-column upgrade.

Memory tester, to verify the integrity of your compu-
ter’s random-access memory. If you have a bad main menory
chip, this routine will even show you which chip on the
board to replace.

Optional drive step-rate speed-up booting.

True, local clear-screen, including attributes Chalf-
intensity, underline, and graphics).

No more phantom lines in WordStar due to a bug in
previous ROMs. Truer Televideo 912/920 emulation.

More keycodes available, including 1Dh and 1Eh ¢*)] and
““, respectively), from the keyboard.

A shorter, saner beep length (about 1/2 as long as the
original).

A 50 per cent faster key repeat.

An operating system patcher program, which adds_ the
following features: a resident print-screen function which
does not affect your screen or program (you choose from the
Keyboard whether you want the "screen dump” to be 80 columns
wide or 128); and the ability to send any non-zero ASCII
character to your printer -- again, in the middle of your
program! ("“Resident” means that once patched, always avail-
able.)

A handful of feature programs, like one to save your
new Dvorak (or whatever) keyboard definition, including any
special new functions you may have defined “locally"; or one
to set the time-of-day clock you now have, as well as other
system parameters, like baud rate and system printer.

WHAT YOU LOSE WITH THE OZROM IE:

Although Centronics parallel printer operation is not
affected (which means printers that use the IEEE~488 port as
a parallel port will work fine), you can no longer use the
port as an IEEE-488 port without additional software.
--- page page-06.png
The OZROM 1E

BEFORE YOU BEGIN

If you are installing the OZROM IE:

For the sake of your safety, BE SURE that you have
disconnected all AC power from your computer before you
install the integrated circuit that we have provided.
(Pulling the power cord plug out of its socket is suffi-
clent.) Refer to APPENDIX B for installation Instructions.

If your OZROM iE is already installed:

For the sake of your sanity, we recommend reading the
rest of this documentation prior to using your Osborne 1
with the new ROM, and refer to the appropriate sections
frequently as you get familiar with each new feature you
try. Also, you should make a backup copy of the supplied
diskette before you do anything else.

THINGS TO REMEMBER

Control-Shift Keys

In the following sections, we will be referring to
“ctrl-shift" Keys. To enter the corresponding “ctril-shift-
key”, hold down the control and shift keys, and press the
key requested. For example, to enter a ctri-shift-A, hit
the A key while holding down both the control and shift
keys. Then release the Keys.

Toggles

A toggle is a switch function, like a push-button
switch. Every time you use it, you reverse the condition
associated with the switch. An example of a toggle is the
control-V (Insert ON/OFF) toggle of WordStar.

No More Vertical Scrolling

Vertical scrolling with the control-up arrow and
control-down arrow keys has been eliminated. These control-
arrow keys now have different functions: control-up-arrow
repositions the window so that the display starts at column
29, and control-down-arrow positions the window to start at
column 76.

This allows those of you who do not have an 80-column
option to quickly “toggle” the screen to see the right-hand
two-thirds of an 80-column screen (the right hand column is
column 80) with the control-up-arrow key combination. Since
this is right next to the left-square-bracket key, you can
hold down the control key with one hand, and with the other
quickly switch back and forth between the first 52 columns
and the last 52 columns of an 80-column screen. CThe left-
square-bracket key in combination with the control key
“homes” the screen window.)

The control-down-arrow combination allows you to view
the remaining portion of the screen.

--- page page-07.png
The OZROM 1E

FEATURES

Although you can use your new OZROM 1E in almost the
sane way as previous Ol ROMs, there are quite a few new
features now available to you.

A BLINKING CURSOR --

Once installed, the OZROM 1E provides you with a very
nice aid in the use of your computer -- a blinking cursor.
When you turn on your computer, the cursor will not be
blinking. You can either toggle the blinking cursor feature
on or off as described below, or, if you like the feature
enough to desire it as a default condition, you can say so
when you run the OZPATCH utility, which serves as a SETUP
program for your new features. You can even change the
blink rate for a faster or slower blink if you wish.

This is not a “hardware” cursor; It will not blink all
the time. It will blink any time a program asks for a
character, which, you will soon find, its a good indication
when your program is ready to take more input. (Some pro-
grams will not ask for a character until one is ready. In
this instance, the cursor will not blink. Examples include
DBASE II version 2.41, a couple of the supplied O01 utili-
ties, like SETUP and COPY, and those programs which supply
thelr own cursor, like SuperCalc and VDO.)

To turn the blink feature on or off, just type ctrl-
shift-B. You will hear a “bip” to tell you that something
has happened, and you should be able to see on the screen
the effect of the toggle.

Note: Some programs, like WordStar, have public-domain
patches available to blink the cursor. This blinking is
done in the program itself. We recommend that you try out a
copy of your original (without the patch), and use _ this
version if the cursor will blink with the OZROM 1E. (Now,
the blinking is being done where it should be -- in the
console input routine in the ROM -- so you will not lose
your cursor on the screen due to some of those patches.) If
you desire that “smoother, faster-scrolling” version of
WordStar, our version is given in one of the appendices.

Remember, ctrl-shift-B is a toggle, reversing the func-
tion of the blink every time you use it. Should you encoun-
ter an application where a blinking cursor is not desired,
you can easily turn it off this way.

A MORE COMPLETE ASCII KEYBOARD --

The OZROM 1E provides more ASCII Keycodes than previous
ROMs. You can now generate 1Dh (*]) and 1Eh (¢**) directly
from the keyboard. The first code is used to select conm-
pressed print in some dot-matrix printers, and the second
code provides the Home Cursor function of a Televideo 920
terminal, which the Osborne 1 emulates.

To get a *), just type ctri-shift-}. To get **, type
Cyou got it) ctrl-shift-*. (The "*" is on top of the 6.)

3
--- page page-08.png
The OZROM IE

MyKey -- A REDEFINABLE KEYBOARD

With the OZROM iE, the characters you get when you type
on your Keyboard are no longer cast in concrete. Bach key
can be redefined to give you any character you wish. (There
is also the capability of assigning a string of characters
to a key; this is discussed in the next section.)

Four Keyboards

Think of your keyboard as actually being four key-
boards: one “normal” keyboard, one “shift" keyboard, one
“control” Keyboard and one “ctril-shift” Keyboard.

The “normal“ Keyboard returns the character printed on
the Key, or the bottom character if there are two. You’1l
note that on this “normal” keyboard, the control and shift
keys do not produce any results when pressed by themselves.

The “shift" keyboard gives you upper-case letters, or
the top characters from the two-character keys, when you
press the shift key in combination with the corresponding
key.

The “control” keyboard returns the “control character”
that corresponds to the key, or a few remaining ASCII char-
acters that are not displayed on your keyboard, like {, }, *
and ~, when you press the control ("ctrl") key in combina-~
tion with another key. You probably have used the “control”
keyboard extensively in WordStar.

Until now, the "“control-shift“" Keyboard on your compu-
ter was limited to one key -- the ctrl-shift-/ key, which
gave you ASCII 7Fh, the DELETE character. If you knew about
this key, you are a rare person, and if you used it, you are
a very rare person indeed. (It can be used while editing in
WordStar to delete the last character -~ but you probably
used “- instead.)

Well, you now have two additional ctri-shift keys,
and *] as discussed earlier. There are many more ctri-shift
keys that are used for functions, like the ctrl-shift~B
described earlier to toggle the blinking cursor on and off.

AA

Key Redefinition

To redefine a key, type ctrl-shift-X. You will hear a
short “bip”. If your cursor was blinking, it will stop. If
you did not have the keyclick enabled, you will now hear
your next two keyboard entries “click”. The first should be
the key you wish to redefine. The second should be the key
definition that you want. (The ORIGINAL key definition will
always apply here.)

For example, you’ve always wanted a double-quote on a
key that you did not have to shift while you were using
SuperCalc. You probably have not used the backslash key at
all in Supercalc. Here, you can make the backslash key a
double-quote key as follows: Just type ctrli-shift-X, fol-
lowed by the backslash (\) key, followed by the double-quote
("> key (the shift of the single-quote (’) key). Your

--- page page-09.png
The OZROM 1E

cursor will start blinking again if you had that option
selected. Now, hit the backslash Key. You’ll see that it
gives you double-quotes!

If you need the backslash key, you can define the
original double-quotes to be a backslash the same way. If
you wish to redefine a key back to its original definition,
just type ctrl-shift-X, followed by the key TWICE.

Three Keyboards are Definable

You can define the entire normal and shift-keyboards,
and almost all the control-keyboard, in this fashion. You
can assign your control-number function Keys to keys on the
“normal” keyboard to get true single-key function Keys. You
can even assign the control-shift functions to regular keys
Clike making the backslash key into a ctrleshift-X key).
AND, after you have come up with your favorite keyboard, you
can use the MEMORIZE program that we’ve provided to save the
Keyboard definition ina file. MEMORIZE creates a progran
file on diskette that you can execute by itself to restore
your keyboard definition.

A word of caution in redefining letter keys: The
second key entered, if it is a letter key, is affected by
the caps-lock key. If you define a Dvorak keyboard, for
example, all your letter keys will be in upper case if you
leave the caps-lock key on (l.e., down). If you find that a
key you defined is in upper case when you wanted lower, just
repeat the ctrl-shift-X sequence after making sure the caps
lock key is up.

Incidently, the caps~-lock function is separate from the
shift function. This means that when the caps-lock key Is
down, the capital letters you get when you press the shift
Key are different than the capital letters you get from. the
“normal” keyboard (which are due to the caps-lock key being
down). This gives you extra keys if you wish, or you can
even have a Keyboard that gives upper-case on the “normal”
keyboard and lower-case letters when you use the shift key!

MyKey does not have the problem that SMARTKEY or the
public-domain QWIKKEY cannot solve -- namely, the fact that
the keyboard is tied to the ROM. For example, the Dvorak
Keyboard requires the letter S to be located where the
QWERTY Keyboard has the semi-colon. Then, when the caps
lock is down, you would still get a lower-case "“s". With
MyKey, however, the caps-lock function will work properly on
any non-control/non-shift Key.

The only Keys you cannot redefine from the Keyboard are
the control-shift keys, and the following control keys:
all ctrl-arrow keys, and ctri-[{, which are used for screen
positioning. (Actually, the screen-positioning keys are
programmable, but not from the keyboard.)

This means you can also assign keys (and functions; see
the MyKey II section following) to the following Keys:
ctril-esc, ctri-tab, ctri-return, ctril-space, shift-esc,
shift-tab, shift-return, shift-space, and shift-any-arrovw-
key, without affecting the normal key definition. Ctrl-
--- page page-10.png
The OZROM IE

semicolon and ctrl-apostrophe can also be reprogrammed in
this manner.

You can use these extra keys for the MyKey II
functions (they’re coming, they’re coming!) or for those
keys that get “displaced”. For example, your apostrophe key
might be pregrammed to be double-quotes (") for SuperCalc,.
Out of deference to your habit of occasionally using the
original double-quotes key, you do not wish to redefine It
to be the apostrophe key, but you use the apostrophe enough

to warrant putting it someplace. You can assign it to ctrl-
tab, for instance, and always have it available without
having to restore the original definition. (The default

keyboard already has ctrl-apostrophe and ctrl-semicolon
assigned to apostrophe and semicolon for just this purpose.)
Although your key definitions will survive warm boots
(that is, if you type a ctrl-C at the CP/M prompt, you won’t
lose your redefined keyboard), pressing RESET will always
restore the original key definitions. Remember, use
MEMORIZE to save those favorite definitions in a file.

Some Welrd Programs...

One more note ~~ If this or any other special function
should not work or should cease working, one of two things
has happened:

1. You are using a program that does not use the normal
BIOS method of console input. In this instance, the progran
will return strange characters instead of executing the
desired functions. If you have to use this type of program,
just don’t use ctrl-shift-X or ctrl-shift-R (discussed in
the next section}. You can, however, redefine your Keyboard
OUTSIDE of this type of program and save the Key redefini-
tions with MEMORIZE. Then, when you load them back in
later, the new definitions will be available to you even
though you can’t change them in the middle of the program.
This only applies to ctrl-shift-X redefinitions.

2. You are using a program that has “walked“ on the
special reserved key-definition space, up in video RAM. The
ROM has a specia! routine to detect this change and restore
control to the Keyboard definitions in ROM. In this in-
stance, you can go through the motions of redefining a key,
but when you attempt to use the redefined Key, you will find
that the Key has its original definition. (The OZROM IE
special features will work with ALL standard CP/M programs,
and with 98 per cent of programs that are specially written
to work with the Gsborne 1. The remaining 2 per cent don’t
use the standard video functions of the Osborne 1; they
wrote their own routines which may walk on the reserved
memory space of the OZROM IE. Please let us know if you
come across one of these programs. In most cases the pro-
gram can be easily modified to stay within the required
limits.>

--- page page-11.png
The OZROM 1E

MyKey II == NEW FUNCTION KEYS

In addition to redefining a key to give youa different
character, you can redefine a key to give you a string of up
to 63 characters, and you can have up to 8 such “function”
keys at a time Cin addition to the regular function keys).

Ctrle-shift-R starts the MyKey II function key defini-
tion. When you press ctrl-shift-R, you will see the botton
line of your Osborne 1 display disappear, to be replaced by
the word KEY: followed by a block cursor. This is a prorapt
asking you for which Key you wish to define. When you type
a key, the prompt will disappear, and the block cursor will
move to the beginning of the line.

Now you can enter your function definition, up to 63
characters in length. The left-arrow key is used in this
mode to backspace and delete the previously-entered charac-
ter. To exit this mode (which will always be indicated by
the block cursor), just type another ctril-shift-R. The
bottom line of your O1 display will be replaced, and your
key has now been redefined to be a function key, just like
your regular ctrl-number function keys.

If you do not enter anything, or if you have backspaced
to the beginning of the line, typing ctrl-shift-R will exit
without redefining the key.

Here’s an example: In generating this documentation,
the writer found it convenient to redefine a key to produce
the phrase “ctri-shift-". Since the underline key was not
often used, it was selected as the “function” key. The key
sequence was:

ctrl-shifte-rR, shift-underl ine, CoteKPal ~,BeHha la fyty=,
ctrl-shift-R.

Now, when the underline key !s struck, it produces the
phrase “ctrl-shift-".

Eight’s the Limit At Any One Tine

You can have up to eight function definitions at one
time. If you redefine a ninth key as a function (Cas de-
scribed above), then the first key that you had defined in
this way will now have the same definition as the ninth key.
To correct this, or to assign a function key back to its
original character value, use ctrl-shift-X. See the techni-
cal notes appendix for an explanation of how these function
keys are generated and interpreted.

These functions are also saved by the MEMORIZE program
when you save your keyboard definitions. You may want to
assign ctrl-shift-R to a single key, like the backslash, to
make it easy to program a quickie function in the middle of
your application.

It is recommended that you do not redefine the left-
arrow key (the backspace key), since only the original
left-arrow definition will be accepted for backspace editing
while using MyKey II.
--- page page-12.png
The OZROM 1E

IMMEDIATE CONTROL OVER SYSTEM PARAMETERS

With the OZROM 1E, you also have immediate control over
some of your system parameters, like automatic horizontal
scrolling, cursor blink, time-of-day clock display, key-
click, and 52-, 80-, or 104-column mode (with Screen-Pac).

As mentioned earlier, ctrl-shift-B toggles cursor blink
on and off. In like manner:

Ctrl-shift-S toggles the automatic horizontal scrolling
feature of the Osborne 1.

Ctrl-shift-T toggles the display of the new time-of-day
clock in the OZROM !1E. (Turning off the display does not
erase what was previously put on the screen.)

Ctrl-shift-K toggles the kKeyclick feature of the OZROM
1E on and off.

If you have the Osborne Screen-Pac 52-80-104 column
option, then the following is available to you:

Ctrl-shift-5 selects the 52-column mode.

Ctrl-shift-8 selects the 80-column mode.

Ctrl-shift-1 or ctrl-shift-O select the 104-column
mode.

NO MORE PARALLEL PORT PARALYSIS

For those of you with printers that use the parallel
port of your Ol: Ever lock up your computer because your
printer was not plugged in and you tried to print something?
Well, if you should ever lock up your system again for this
reason, remember the following -~ otri-shift-escape will
assign your parallel printer to a “null“ device (that is,
any characters you try to print will be thrown away and not

printed). This will allow you to recover control of your
computer. If you are using WordStar, for example, after you
type ctrl-shift-escape, you can then type a P to stop. the
printing. Note: If you have assigned your printer to a

“null” device with ctrl-shift-escape, you can restore your
parallel printer to normal operation by typing ctrl-shift-7.

PRINT YOUR SCREEN (with OZPATCH only)

If you have patched your system with the supplied
OZPATCH program, you also have the ability to print your
screen and send any character to your printer, right in the
middle of your program. Ctrl-shift-P will send a non-
graphics image of your screen’s first 80 columns to your
printer. Ctrl-shift-W will send the entire 24 lines by 128
columns of your screen to your printer. If your cursor was
blinking when you selected either of these functions, it
will stop, until the computer is ready to accept more input.
Graphics characters will be converted into asterisks Cx).

Output will be to the device you have selected to be
the printer in the SETUP program. (You can tell your
computer to print to a different port -- serial, parallel,
or even your Osborne screen can be the “printer” <-- by
changing the IOBYTE with DDT or the SET program provided.)

--- page page-13.png
The OZROM 1E

CONTROL YOUR PRINTER FROM YOUR KEYBOARD (with OZPATCH only)

Ctrleshift-0 tells your computer that the next charac-
ter you type is to be sent to your printer. For example, if
you have a printer that requires a control-O for compressed
print and you want compressed print for your printout, you
can type ctrl-shift-0O, control-O to put your printer In the
compressed mode. If you want to send a formfeed to your
printer, just type ctril-shift-O followed by control-L, which
is the formfeed character for most printers. See the
OZPATCH documentation for more information.

TIME-OF-DAY CLOCK

You now have a time-of-day clock available to you. It
can be displayed anywhere on the first two lines of your
display (see the Technical Notes in the appendix). You can
set the time with the TIME program provided. The clock is
very accurate as long as no disk access takes place. Some
“fudging" has been added to make the clock reasonably accu-
rate even with floppy disk access.

The Technical Notes section of the appendix gives’ the
info you would need if you wished to make use of the clock
in your prograams.

TRUE CLEAR~-SCREEN

You also have the ability to clear your screen any time
your program is expecting Keyboard input. Type ctrl-shift-Z
to zap your screen completely. Use caution with this. one,
though; if you do it in the middle of your WordStar or
SuperCalc program, it will be a while before your screen
“returns to normal.” Ctril-shift-Z will prove most useful
for clearing the screen of garbage from listing WordStar
files, etc., or preparing the screen for a_ screen-print.
Another use is recovering from the graphics mode, or half-
intensity or underline modes, should you accidentally get
stuck in one of these nodes.

Now, any time your program clears your screen by send-
ing a control-Z to your console, the half-intensity and
underline attributes will be reset, also. Should you need
to clear the graphics attribute as well, send an escape
followed by a control-Z; otherwise, the control-Z will be
interpreted as a graphics character.

SYSTEM CRASH DAMAGE PROTECTION

There is a program called CRASH on the diskette we’ve
provided which demonstrates what will happen almost every
time any of your programs should do something wrong. With
the previous ROMs, your same program under the same condi-
tions would have turned on both drives and the bell, which
ran a very good chance of ruining any diskette in the drive.
The OZROM 1E reduces the chance of diskette damage from
about one in two to about one in one thousand.
--- page page-14.png
The OZROM IE

A SYSTEM MEMORY TESTER -~-

The OZROM 1E has a memory tester built in to test your
system RAM. You can execute the memory test program at
power-up or after you push the RESET button. Just press the
TAB key to start the tester going. The display will show:

RAM TEST

XXXX

where XXXX will be a rapidly changing address display,
indicating in hexadecimal which RAM _ location is being
tested. The test is cyclic, starting each time at memory
location O and testing (0, OFFh, OAAh, and 55h) thru OEFFFh.
Video memory is not tested; a problem with video memory will
not only be visible on the display, it will be generally
trapped as an error starting around OCO000h (video RAM is
only 1/4 of one of the 16K banks of RAM).

Should a failure be detected, the address display will
freeze and two sets of binary numbers will be displayed:

XXXX bbbbbbbb
bbbbbbbb

This information can be used to determine which IC on
the main board (Rev. E or later) has failed. Here’s how to
use the information:

XXXX bbbbbbbb <--- what the memory tester wrote
bbbbbbbb <--- what the memory tester read
01234567 <--- the Y value, used below

First, determine which 16K bank of memory (A, B, C, or
D> has the bad chip:

if the value of XXXX is: then the bank is:
0000-3FFF A
4000-7FFF B
8000-BFFF Cc
COOO-EFFF D

Then look at the binary display. There will be a
difference between what the tester program wrote and what it
read. That difference will generally be in one column only.
Here the columns are numbered from left to right, zero thru
seven. If the difference is in the fourth column, then the
corresponding number is 3.

The bad chip will then be at X2Y, where X is the bank
letter and Y is the number obtained from the binary display.
For example, say the display has stopped changing and shows:

402F 00000000
00000100

10

--- page page-15.png
The OZROM 1E

The 402F indicates bank B and the 1 in the sixzth column
says that the Y value is 5. Then we should replace the chip
at location B25 on the main circuit board.

Note: The memory test is continuous and will not stop
unless you either press RESET or turn the computer off.
Some memory chip failures only occur after the chip gets
warm, so it may be a good idea to test your memory AFTER the
machine has been on a while. Run the memory tester any time
your computer does not seem to be acting properly. If your
computer passes the test, at least you have eliminated the
system RAM as part of the problen. (Memory failure can
actually result in Bdos errors, which might lead you to
believe the disk drive had a problem.)

1200=-BAUD MODEM OPERATION CONSIDERATIONS

The new video software routines on your OZROM 1E do not
make use of the entire screen of video RAM in order to give
you the some of the features previously mentioned, like
MyKey and MyKey II. As a consequence, the video screen
cannot be moved down like a window placed over the video
RAM, as discussed in your O1 manual. Instead, when the
cursor is at the bottom of the screen and your program sends
a linefeed character “to the screen", the video subroutines
move the bottom 23 lines of your display up one line, first
the regular video stuff, then the half-intensity stuff.
This is slower than the original ROMs, but most of your
software is memory-mapped or uses cursor addressing, s0 you
will generally not notice.

However, although 300-baud operation is not affected,
1200-baud operation WHERE THE VIDEO SCREEN IS CONCERNED may
be unreliable. (Object file transfer with XMODEM or pro-
grams like MOVE-IT will not be affected.)

Viewing text on the screen at 1200 baud will result in
characters near the beginning of the line being dropped due
to this delay, UNLESS YOUR HOST COMPUTER CAN SUPPLY NULLS
appropriately at the end of each line. When your host
computer says “How many nulls?", reply with 4. That is,
tell the host computer you need four nulls to operate
correctly.

Again, 300-baud operation is not affected.

ADDITIONAL DISPLAY CONTROL CODES

You might have purchased a program that you had to
“install” on your O1 through a lengthy procedure where you
told the program that your computer used ESC >) to turn on
half-intensity, etc. If you ever have to do it again, the
following additional display control codes may prove useful:

ESC j turns on BOTH underlining AND half-intensity

Esc k turns both underlining and half-intensity off

ESC Y¥Y clears from the cursor position to end-of-screen

il
--- page page-16.png
The OZROM 1E

“BOOTING” USING THE LEFT/RIGHT ARROW KEYS

When you boot your computer with the <RETURN> key Cor
the <"> key for the right-hand drive), the OZROM 1E acts
similar to the previous O1 ROMs. If the @rive has trouble
reading the diskette, you will see the message “OH, NO!”
appear on your screen (instead of “BOOT ERROR") and the disk
drive head will be moved to track 5 and then back again for
another attempt. However, there is another way to boot your
diskettes, using the horizontal arrow Keys.

When you first boot using the left or right arrow, your
disk drives are assigned a step rate delay of 12 ms. (The
original step rate delay is 20 ms.) This causes your disk
drives to step from track to track a little faster than

before. (You may have used a FAST program to “speed up”
your drives in this manner.) Some Osbornes, however, cannot
stand the speed-up. The OZROM 1E attempts to read the

system tracks of a diskette with this speed-up, but if the
first attempt fails, then the step rate is set to 20 ms, the
disk drive head is moved out to track 5, and then “homed*
again to try to read the first track again. This is the
case if you frequently see “OH, NO!” appear once before your
system boots.

There are two possible types of problems that can occur
with the drive speed-up. One is a home-sensor-adjustment
problem, and will occur (if at all) only at system boot or
warm boot (i.e., when you type a ctrl-C at the CP/M prompt).
The reason is that the speed-up causes the head to “home” so
fast it actually passes track O before the computer can
recognize that it’s there. The sensor in this instance is
generating the signal too late for the computer to react to
it. Unfortunately, it goes on telling the computer that the
head is at track 0, even though the head is actually past it
-- consequently, the drive head cannot read any valid data
and the computer returns the boot error. THE FIX: Either
get the home sensor adjusted to accommodate the speed-up
(the “stops” may have to be adjusted also), or don’t boot
using the horizontal arrow keys (use the regular <RETURN>D or
<"> keys to boot instead).

In the second possibility, the stepper motor cannot
stand the delay reduction. You may hear a laboring sound
from your @rive (making it sound like an old-time Apple disk
drive), but there will be an increase in the Bdos errors you
get. Sometimes, they will show up after the stepper motor
heats up a bit from use, which means you will probably be
able to boot with the arrow keys, but after a while you will
have problems. If this is the case, then refrain from using
the arrow Keys to boot your diskettes.

12

--- page page-17.png
The OZROM 1E

OZROM 1E SUPPORT PROGRAMS

Several programs are included on the diskette supplied
with your OZROM 1E package. These programs are intended to
make your use of the OZROM 1E more convenient.

MEMORIZE

The main one is the MEMORIZE program. This one allows
you to save the keyboard definitions that you have created
with ctrl-shift-X and ctrl-shift-R. The MEMORIZE program
creates a .COM file on diskette that can be run to restore
your keyboard definition. For example, if you type
MEMORIZE<cr> at the CP/M prompt, your current key defini-
tions and any MyKey II function key definitions will be
saved on a diskette in the default disk drive in a file
called KEYBOARD.COM. At any time thereafter, you can type
KEYBOARD<cr> from the CP/M prompt, which will restore’ the
definitions you had when the MEMORIZE program was initially
run.

You are not limited to the filename KEYBOARD.COM. Just
enter the filename you want after the word MEMORIZE on the
CP/M command line. For example, you have defined a DVORAK
keyboard that you want to save under the name DVORAK.COM.
Just type: ;

MEMORIZE DVORAK<cr>
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

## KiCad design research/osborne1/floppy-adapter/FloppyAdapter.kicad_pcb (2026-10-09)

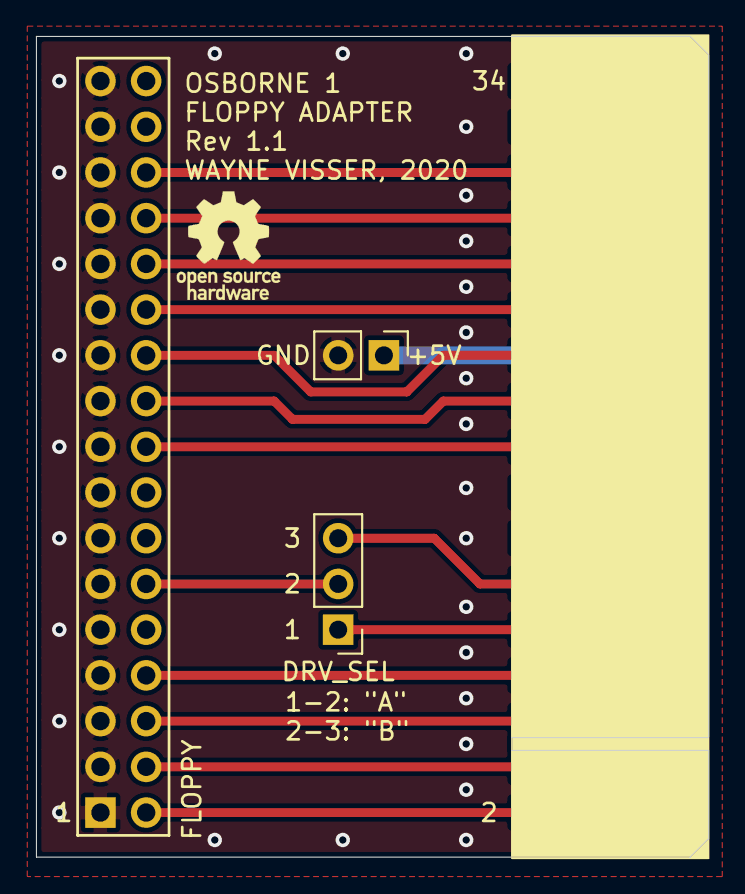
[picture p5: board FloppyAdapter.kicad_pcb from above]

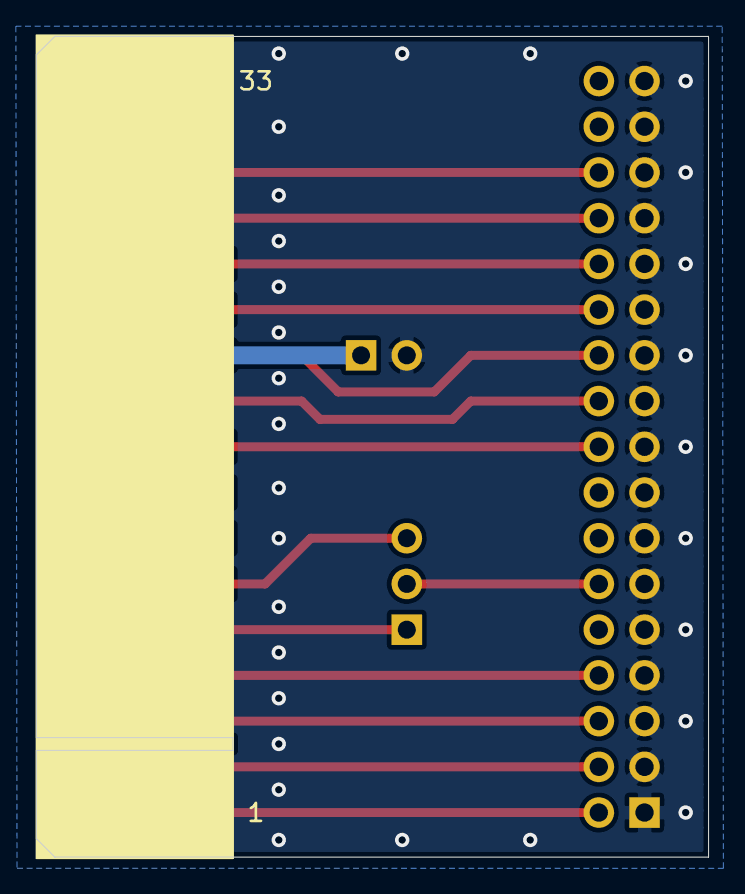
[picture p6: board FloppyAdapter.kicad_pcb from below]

Board: 2 copper layers, 37.3 x 45.6 mm, 37 parts (17 on the bottom side), 16 nets.

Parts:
DRV_SEL: Conn_01x03; Pin_Header_Straight_1x03_Pitch2.54mm
FLOPPY: IDC 34 Pin; PPPC172LJBN-RC
J1, J2, J3, J4, J5, J6, J7, J9, J19, J27, J29, J31, J33: GND; EdgeFinger
J8: INDEX; EdgeFinger
J10: DS1; EdgeFinger
J11, J13, J15, J17: +12V; EdgeFinger
J12: DS2; EdgeFinger
J14: NC; EdgeFinger
J16: 4MHz; EdgeFinger
J18: DIR; EdgeFinger
J20: STEP; EdgeFinger
J21, J23, J25: +5V; EdgeFinger
J22: WD; EdgeFinger
J24: WG; EdgeFinger
J26: TRK00; EdgeFinger
J28: WP; EdgeFinger
J30: RD; EdgeFinger
J32: SS; EdgeFinger
J34: LATE; EdgeFinger
PWR1: Conn_02x01; Pin_Header_Straight_1x02_Pitch2.54mm

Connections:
unnamed: FLOPPY.1, FLOPPY.3, FLOPPY.5, FLOPPY.7, FLOPPY.9, FLOPPY.11, FLOPPY.13, FLOPPY.15, FLOPPY.17, FLOPPY.19, FLOPPY.21, FLOPPY.23, FLOPPY.25, FLOPPY.27, FLOPPY.29, FLOPPY.31, FLOPPY.33, J1.1, J3.1, J5.1, J7.1, J9.1, J19.1, J27.1, J29.1, J31.1, J33.1, PWR1.2
unnamed: FLOPPY.2, J2.1
unnamed: FLOPPY.4, J4.1
unnamed: FLOPPY.6, J6.1
unnamed: FLOPPY.8, J8.1
unnamed: DRV_SEL.2, FLOPPY.12
unnamed: FLOPPY.18, J18.1
unnamed: FLOPPY.20, J20.1
unnamed: FLOPPY.22, J22.1
unnamed: FLOPPY.24, J24.1
unnamed: FLOPPY.26, J26.1
unnamed: FLOPPY.28, J28.1
unnamed: FLOPPY.30, J30.1
unnamed: DRV_SEL.1, J10.1
unnamed: DRV_SEL.3, J12.1
unnamed: J21.1, PWR1.1

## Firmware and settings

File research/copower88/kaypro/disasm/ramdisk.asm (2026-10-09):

; z80dasm 1.2.0
; command line: z80dasm -a -l -g 0x100 -o /tmp/k_ramdisk.asm research/copower88/kaypro/extracted_cpm/ramdisk.com

	org 00100h

	jp l0111h		;0100
l0103h:
	inc c			;0103
l0104h:
	ld e,c			;0104
l0105h:
	nop			;0105
	nop			;0106
l0107h:
	ld a,a			;0107
l0108h:
	ld a,(hl)		;0108
	nop			;0109
	ld a,(bc)		;010a
	nop			;010b
	inc b			;010c
	nop			;010d
	rrca			;010e
	nop			;010f
	inc de			;0110
l0111h:
	ld sp,l09a7h		;0111
	ld hl,(00001h)		;0114
	ld de,0001ah		;0117
	add hl,de		;011a
	ld a,(hl)		;011b
	cp h			;011c
	jp nc,l02dch		;011d
	ld de,l012bh		;0120
	ld c,009h		;0123
	call 00005h		;0125
	jp 00000h		;0128
l012bh:
	dec c			;012b
	ld a,(bc)		;012c
	ld hl,(02a2ah)		;012d
	jr nz,$+116		;0130
	ld h,c			;0132
	ld l,l			;0133
	ld h,h			;0134
	ld l,c			;0135
	ld (hl),e		;0136
	ld l,e			;0137
	jr nz,l019eh		;0138
	ld (hl),d		;013a
	ld l,c			;013b
	halt			;013c
	ld h,l			;013d
	ld (hl),d		;013e
	jr nz,l01aah		;013f
	ld (hl),e		;0141
	jr nz,l01a5h		;0142
	ld l,h			;0144
	ld (hl),d		;0145
	ld h,l			;0146
	ld h,c			;0147
	ld h,h			;0148
	ld a,c			;0149
	jr nz,l01adh		;014a
	ld h,e			;014c
	ld (hl),h		;014d
	ld l,c			;014e
	halt			;014f
	ld h,l			;0150
	jr nz,l017dh		;0151
	ld hl,(l0d2ah)		;0153
	ld a,(bc)		;0156
	inc h			;0157
l0158h:
	ld de,l0163h		;0158
	ld c,009h		;015b
	call 00005h		;015d
	jp 00000h		;0160
l0163h:
	dec c			;0163
	ld a,(bc)		;0164
	ld a,(bc)		;0165
	ld hl,(02a2ah)		;0166
	jr nz,l01ceh		;0169
	ld h,c			;016b
	ld l,(hl)		;016c
	ld l,(hl)		;016d
	ld l,a			;016e
	ld (hl),h		;016f
	jr nz,l01deh		;0170
	ld l,a			;0172
	ld h,c			;0173
	ld h,h			;0174
	inc l			;0175
	jr nz,l01b0h		;0176
	jr nc,l01b2h		;0178
	jr c,$+34		;017a
	ld h,h			;017c
l017dh:
	ld l,a			;017d
	ld h,l			;017e
	ld (hl),e		;017f
	jr nz,l01f0h		;0180
	ld l,a			;0182
	ld (hl),h		;0183
	jr nz,l01f8h		;0184
	ld h,l			;0186
	ld (hl),e		;0187
	ld (hl),b		;0188
	ld l,a			;0189
	ld l,(hl)		;018a
	ld h,h			;018b
	jr nz,l01b8h		;018c
	ld hl,(l0d2ah)		;018e
	ld a,(bc)		;0191
	inc h			;0192
l0193h:
	ld de,l019eh		;0193
	ld c,009h		;0196
	call 00005h		;0198
	jp 00000h		;019b
l019eh:
	dec c			;019e
	ld a,(bc)		;019f
	ld hl,(02a2ah)		;01a0
	jr nz,$+112		;01a3
l01a5h:
	ld l,a			;01a5
	ld (hl),h		;01a6
	jr nz,$+117		;01a7
	ld (hl),h		;01a9
l01aah:
	ld h,c			;01aa
	ld l,(hl)		;01ab
	ld h,h			;01ac
l01adh:
	ld h,c			;01ad
	ld (hl),d		;01ae
	ld h,h			;01af
l01b0h:
	jr nz,l01f5h		;01b0
l01b2h:
	ld d,b			;01b2
	cpl			;01b3
	ld c,l			;01b4
	jr nz,l022ah		;01b5
	ld a,c			;01b7
l01b8h:
	ld (hl),e		;01b8
	ld (hl),h		;01b9
	ld h,l			;01ba
	ld l,l			;01bb
	inc l			;01bc
	jr nz,$+101		;01bd
	ld h,c			;01bf
	ld l,(hl)		;01c0
	ld l,(hl)		;01c1
	ld l,a			;01c2
	ld (hl),h		;01c3
	jr nz,$+107		;01c4
	ld l,(hl)		;01c6
	ld (hl),e		;01c7
	ld (hl),h		;01c8
	ld h,c			;01c9
	ld l,h			;01ca
	ld l,h			;01cb
	jr nz,l01f8h		;01cc
l01ceh:
	ld hl,(l0d2ah)		;01ce
	ld a,(bc)		;01d1
	inc h			;01d2
l01d3h:
	ld de,l01deh		;01d3
	ld c,009h		;01d6
	call 00005h		;01d8
	jp 00000h		;01db
l01deh:
	dec c			;01de
	ld a,(bc)		;01df
	ld hl,(02a2ah)		;01e0
	jr nz,l024eh		;01e3
	ld l,(hl)		;01e5
	halt			;01e6
	ld h,c			;01e7
	ld l,h			;01e8
	ld l,c			;01e9
	ld h,h			;01ea
	jr nz,$+114		;01eb
	ld h,c			;01ed
	ld (hl),d		;01ee
	ld h,c			;01ef
l01f0h:
	ld l,l			;01f0
	ld h,l			;01f1
	ld (hl),h		;01f2
	ld h,l			;01f3
	ld (hl),d		;01f4
l01f5h:
	jr nz,l0260h		;01f5
	ld l,(hl)		;01f7
l01f8h:
	jr nz,$+101		;01f8
	ld l,a			;01fa
	ld l,l			;01fb
	ld l,l			;01fc
	ld h,c			;01fd
	ld l,(hl)		;01fe
	ld h,h			;01ff
	jr nz,$+110		;0200
	ld l,c			;0202
	ld l,(hl)		;0203
	ld h,l			;0204
	jr nz,$+44		;0205
	ld hl,(l0d2ah)		;0207
	ld a,(bc)		;020a
	inc h			;020b
l020ch:
	dec c			;020c
	ld a,(bc)		;020d
	ld a,(bc)		;020e
	ld hl,(02a2ah)		;020f
	ld hl,(02a2ah)		;0212
	ld hl,(02a2ah)		;0215
	ld hl,(02a2ah)		;0218
	ld hl,(02a2ah)		;021b
	ld hl,(02a2ah)		;021e
	ld hl,(02a2ah)		;0221
	ld hl,(02a2ah)		;0224
	ld hl,(02a2ah)		;0227
l022ah:
	ld hl,(02a2ah)		;022a
	ld hl,(02a2ah)		;022d
	ld hl,(02a2ah)		;0230
	ld hl,(02a2ah)		;0233
	ld hl,(02a2ah)		;0236
	ld hl,(02a2ah)		;0239
	ld hl,(02a2ah)		;023c
	ld hl,(00a0dh)		;023f
	ld hl,(l202ah)		;0242
	jr nz,l029ah		;0245
	ld d,a			;0247
	ld d,b			;0248
	jr nz,$+69		;0249
	ld l,a			;024b
	ld d,b			;024c
	ld l,a			;024d
l024eh:
	ld (hl),a		;024e
	ld h,l			;024f
	ld (hl),d		;0250
	ld e,a			;0251
	jr c,l028ch		;0252
	jr nz,$+116		;0254
	ld h,c			;0256
	ld l,l			;0257
	ld h,h			;0258
	ld l,c			;0259
	ld (hl),e		;025a
	ld l,e			;025b
	jr nz,$+102		;025c
	ld (hl),d		;025e
	ld l,c			;025f
l0260h:
	halt			;0260
	ld h,l			;0261
	ld (hl),d		;0262
	jr nz,l0285h		;0263
	jr nz,$+52		;0265
	ld sp,04e2dh		;0267
	ld l,a			;026a
	halt			;026b
	dec l			;026c
	jr c,$+54		;026d
	jr nz,l0291h		;026f
	ld hl,(l0d2ah)		;0271
	ld a,(bc)		;0274
	ld hl,(l202ah)		;0275
	jr nz,l029ah		;0278
	jr nz,l029ch		;027a
	jr nz,l029eh		;027c
	jr nz,l02a0h		;027e
	jr nz,l02a2h		;0280
	jr nz,l02a4h		;0282
	ld h,e			;0284
l0285h:
	ld l,a			;0285
	ld (hl),b		;0286
	ld a,c			;0287
	ld (hl),d		;0288
	ld l,c			;0289
	ld h,a			;028a
	ld l,b			;028b
l028ch:
	ld (hl),h		;028c
	jr nz,l02b7h		;028d
	ld b,e			;028f
	add hl,hl		;0290
l0291h:
	jr nz,$+51		;0291
	add hl,sp		;0293
	jr c,$+54		;0294
	jr nz,$+34		;0296
	jr nz,l02bah		;0298
l029ah:
	jr nz,$+34		;029a
l029ch:
	jr nz,$+34		;029c
l029eh:
	jr nz,l02c0h		;029e
l02a0h:
	jr nz,$+34		;02a0
l02a2h:
	jr nz,$+34		;02a2
l02a4h:
	ld hl,(l0d2ah)		;02a4
	ld a,(bc)		;02a7
	ld hl,(02a2ah)		;02a8
	ld hl,(02a2ah)		;02ab
	ld hl,(02a2ah)		;02ae
	ld hl,(02a2ah)		;02b1
	ld hl,(02a2ah)		;02b4
l02b7h:
	ld hl,(02a2ah)		;02b7
l02bah:
	ld hl,(02a2ah)		;02ba
	ld hl,(02a2ah)		;02bd
l02c0h:
	ld hl,(02a2ah)		;02c0
	ld hl,(02a2ah)		;02c3
	ld hl,(02a2ah)		;02c6
	ld hl,(02a2ah)		;02c9
	ld hl,(02a2ah)		;02cc
	ld hl,(02a2ah)		;02cf
	ld hl,(02a2ah)		;02d2
	ld hl,(02a2ah)		;02d5
	ld hl,(00a0dh)		;02d8
	inc h			;02db
l02dch:
	ld de,l020ch		;02dc
	ld c,009h		;02df
	call 00005h		;02e1
	ld hl,00080h		;02e4
	ld a,(hl)		;02e7
	or a			;02e8
	jr z,l0300h		;02e9
	ld b,000h		;02eb
	ld c,(hl)		;02ed
	inc hl			;02ee
	add hl,bc		;02ef
	ld d,h			;02f0
	ld e,l			;02f1
	inc de			;02f2
	ld bc,00005h		;02f3
	ld (hl),00dh		;02f6
	ldir			;02f8
	ld hl,00082h		;02fa
	ld (l0961h),hl		;02fd
l0300h:
	call sub_08ceh		;0300
	dec c			;0303
	ld a,(bc)		;0304
	ld a,(bc)		;0305
	ld d,b			;0306
	ld l,h			;0307
	ld h,l			;0308
	ld h,c			;0309
	ld (hl),e		;030a
	ld h,l			;030b
	jr nz,$+99		;030c
	ld l,(hl)		;030e
	ld (hl),e		;030f
	ld (hl),a		;0310
	ld h,l			;0311
	ld (hl),d		;0312
	jr nz,l0389h		;0313
	ld l,b			;0315
	ld h,l			;0316
	jr nz,$+104		;0317
	ld l,a			;0319
	ld l,h			;031a
	ld l,h			;031b
	ld l,a			;031c
	ld (hl),a		;031d
	ld l,c			;031e
	ld l,(hl)		;031f
	ld h,a			;0320
	jr nz,$+115		;0321
	ld (hl),l		;0323
	ld h,l			;0324
	ld (hl),e		;0325
	ld (hl),h		;0326
	ld l,c			;0327
	ld l,a			;0328
	ld l,(hl)		;0329
	ld (hl),e		;032a
	ld a,(00a0dh)		;032b
	inc h			;032e
l032fh:
	call sub_08ceh		;032f
	dec c			;0332
	ld a,(bc)		;0333
	ld b,h			;0334
	ld (hl),d		;0335
	ld l,c			;0336
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

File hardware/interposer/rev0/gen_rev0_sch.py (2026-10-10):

#!/usr/bin/env python3
"""Generate the Rev 0 'test probe' KiCad 7 schematic.

Structural schematic for routing: Z80 pass-through (plug + socket),
4x 74AHCT165 PISO snapshot front end, Pico 2 W module, 5 V input, decoupling.
Buses are connected by net labels (standard practice), so re-mapping
GPIO assignments later is a label edit, not a re-route.

Regenerate: python3 gen_rev0_sch.py  (writes rev0.kicad_sch)
KiCad is not required to generate; open/re-save in KiCad 7+ to normalize.
"""
import uuid, datetime

def uid():
    return str(uuid.uuid4())

def prop(name, value, x, y, hide=False):
    fx = '(effects (font (size 1.27 1.27))' + (' (hide yes))' if hide else ')')
    return f'    (property "{name}" "{value}" (at {x} {y} 0) {fx})\n'

class Symbol:
    def __init__(self, lib, name, ref_letter, w, h):
        self.lib_id = f'{lib}:{name}'
        self.name = name
        self.ref_letter = ref_letter
        self.w, self.h = w, h
        self.pins = []  # (number, pinname, side, offset_from_top)
    def add(self, num, pname, side, off):
        self.pins.append((num, pname, side, off))
        return self
    def pin_pos(self, num):
        """symbol-local connection point, in KiCad symbol space (Y up).

        `off` counts down from the TOP of the box, so the symbol-space Y is
        `+hh - off` (top edge = +hh).  The sheet is Y-down, so a placed
        symbol's pin lands at `(x + px, y - py)` -- see place().
        """
        for n, p, side, off in self.pins:
            if n == num:
                hw, hh = self.w/2, self.h/2
                if side == 'L': return (-hw, hh - off)
                if side == 'R': return ( hw, hh - off)
                if side == 'T': return (-hw + off, hh)
                return (-hw + off, -hh)
        raise KeyError(num)
    def lib_sexpr(self):
        s = f'  (symbol "{self.lib_id}" (pin_names (offset 0.508)) (in_bom yes) (on_board yes)\n'
        s += prop('Reference', self.ref_letter, 0, -self.h/2 - 2.54)
        s += prop('Value', self.name, 0, -self.h/2 - 5.08)
        s += prop('Footprint', '', 0, 0, True)
        s += prop('Datasheet', '', 0, 0, True)
        hw, hh = self.w/2, self.h/2
        s += f'    (symbol "{self.name}_0_1"\n      (rectangle (start {-hw} {-hh}) (end {hw} {hh}) (stroke (width 0.254) (type default)) (fill (type background))))\n'
        s += f'    (symbol "{self.name}_1_1"\n'
        for n, p, side, off in self.pins:
            x, y = self.pin_pos(n)
            rot = {'L': 0, 'R': 180, 'T': 270, 'B': 90}[side]
            # anchor at box edge; pin body extends outward
            if side == 'L': ax, ay = x - 2.54, y
            elif side == 'R': ax, ay = x + 2.54, y
            elif side == 'T': ax, ay = x, y - 2.54
            else: ax, ay = x, y + 2.54
            s += (f'      (pin passive line (at {ax} {ay} {rot}) (length 2.54)'
                  f' (name "{p}" (effects (font (size 1.27 1.27))))'
                  f' (number "{n}" (effects (font (size 1.27 1.27)))))\n')
            # store absolute anchor for wiring: adjust pin_pos to anchor
        s += '    )\n  )\n'
        return s
    def anchor(self, num):
        """symbol-local connection point (pin outer end)."""
        for n, p, side, off in self.pins:
            if n == num:
                hw, hh = self.w/2, self.h/2
                if side == 'L': return (-hw - 2.54, hh - off)
                if side == 'R': return ( hw + 2.54, hh - off)
                if side == 'T': return (-hw + off, hh + 2.54)
                return (-hw + off, -hh - 2.54)
        raise KeyError(num)

# ---------- symbol definitions ----------
# ---------- Z80 pinout (single source of truth) ----------
# Standard Zilog Z80 / NEC uPD780C DIP-40: pins 1-20 run down the left side,
# 40-21 down the right.  Both the symbol geometry and the net names below are
# derived from this table -- hand-maintaining two copies is exactly how an
# off-by-one survived here (pin 11 is +5V and pin 29 is GND, not pin 12/30).
# tools/check_schematics.py now enforces the datasheet pinout.
Z80_LEFT = [
    (1,'A11'),(2,'A12'),(3,'A13'),(4,'A14'),(5,'A15'),(6,'CLK'),(7,'D4'),(8,'D3'),
    (9,'D5'),(10,'D6'),(11,'+5V'),(12,'D2'),(13,'D7'),(14,'D0'),(15,'D1'),(16,'/INT'),
    (17,'/NMI'),(18,'/HALT'),(19,'/MREQ'),(20,'/IORQ')]
Z80_RIGHT = [
    (40,'A10'),(39,'A9'),(38,'A8'),(37,'A7'),(36,'A6'),(35,'A5'),(34,'A4'),(33,'A3'),
    (32,'A2'),(31,'A1'),(30,'A0'),(29,'GND'),(28,'/RFSH'),(27,'/M1'),(26,'/RESET'),
    (25,'/BUSRQ'),(24,'/WAIT'),(23,'/BUSAK'),(22,'/WR'),(21,'/RD')]
Z80NET = dict(Z80_LEFT) | dict(Z80_RIGHT)


# ---------- symbol definitions ----------
def make_z80(name, ref):
    s = Symbol('local', name, ref, 25.4, 106.68)
    for i,(n,p) in enumerate(Z80_LEFT):  s.add(n,p,'L', 5.08 + i*5.08)
    for i,(n,p) in enumerate(Z80_RIGHT): s.add(n,p,'R', 5.08 + i*5.08)
    return s

def make_165(name):
    # 74AHCT165 PISO: latch 8 bus lines at SH//LD strobe; PIO clocks out
    s = Symbol('local', name, 'U', 20.32, 45.72)
    left = [(1,'SH//LD'),(2,'CLK'),(15,'CLK_INH'),(11,'A'),(12,'B'),(13,'C'),(14,'D'),(3,'E'),(4,'F'),(5,'G'),(6,'H')]
    right = [(16,'VCC'),(10,'SER'),(9,'QH'),(7,'/QH'),(8,'GND')]
    for i,(n,p) in enumerate(left):  s.add(n,p,'L', 5.08 + i*5.08)
    for i,(n,p) in enumerate(right): s.add(n,p,'R', 5.08 + i*5.08)
    return s

def make_pico():
    phys = [(1,'GP0'),(2,'GP1'),(3,'GND'),(4,'GP2'),(5,'GP3'),(6,'GP4'),(7,'GP5'),(8,'GND'),(9,'GP6'),(10,'GP7'),(11,'GP8'),(12,'GP9'),(13,'GND'),(14,'GP10'),(15,'GP11'),(16,'GP12'),(17,'GP13'),(18,'GND'),(19,'GP14'),(20,'GP15'),
            (21,'GP16'),(22,'GP17'),(23,'GND'),(24,'GP18'),(25,'GP19'),(26,'GP20'),(27,'GP21'),(28,'GND'),(29,'GP22'),(30,'RUN'),(31,'GP26'),(32,'GP27'),(33,'GND'),(34,'GP28'),(35,'ADC_VREF'),(36,'3V3_OUT'),(37,'3V3_EN'),(38,'GND'),(39,'VSYS'),(40,'VBUS')]
    s = Symbol('local', 'PICO2W', 'U', 25.4, 106.68)
    for i,(n,p) in enumerate(phys[:20]): s.add(n,p,'L', 5.08 + i*5.08)
    for i,(n,p) in enumerate(phys[20:]): s.add(n,p,'R', 5.08 + i*5.08)
    return s

def make_cap():
    s = Symbol('local', 'CAP_100N', 'C', 10.16, 7.62)
    s.add(1,'1','L', 3.81); s.add(2,'2','R', 3.81)
    return s

def make_pwr():
    s = Symbol('local', 'PWR_5V_IN', 'J', 12.7, 7.62)
    s.add(1,'+5V','L', 3.81); s.add(2,'GND','R', 3.81)
    return s
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

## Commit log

2026-10-09 Retarget to Pico 2 W; add floppy interposer, WiFi modem, virtual MX-80 printer
2026-10-09 research: CoPower-88 protocol from Kaypro+Zorba drivers; Zorba extraction (#3 #4, part of #5)
2026-10-09 research: photo survey of CoPower-88 board + O1 Z80 adapter (#9)
2026-10-09 research: CoPower-88 schematic walkthrough 611-0003 sheets 1-4 (#5)
2026-10-09 photo-survey: correct blue component — it is a comparator IC, not a DIP switch (per user)
2026-10-09 docs: agent working agreement (AGENTS.md) — GitHub-only issues, signed-commit + PR workflow
2026-10-09 docs: O1 mainboard memory + I/O map (closes #40)
    Extracted from OCC 1A2011-00 Rev E schematic, cross-checked against the
    O1 Technical Manual (2F00153-01) and MAME osborne1.cpp.
    - 3-bank memory map (main RAM / ROM+I/O shadow / video dim-bit)
    - Full memory-mapped I/O decode: FDC 2100-2103, keyboard 2201-2280,
    IEEE-488 PIA 2900-2903, 6850 ACIA 2A00-2A01, video PIA 2C00-2C03
    - Bank-switch via I/O writes 0x00-0x03 (UD10 LS138, data ignored)
    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
2026-10-09 docs: correct P4 — 24-hole O1A plug (inner 20 used), pin 19 = +12V via J6+R21, open-collector row drive (#47)
2026-10-09 research: archive O1 modem/serial pinout + document P1/DE-9 TTL levels (part of #56)
    Add the O1 Technical Manual ch.4 interface-design extract (kev.pulo.com.au)
    to research/osborne1/modem/ with provenance, and docs/o1-modem-serial.md
    capturing the §4.3 MODEM (P1) pinout: TTL levels (not RS-232), DE-9P pins
    GND/TXD/MSB/CTS/RXD/+12V/MCB/RI, bipolar RXD front-end (LM1458+1N5231B),
    +12V via R21 22ohm, schematic sheet-7 confirmed.
2026-10-09 docs: research-gaps #2 resolved-by-history — all O1s are NMOS Z80; interposer standardized on 74AHCT (#11/#12, #49)
2026-10-09 research: archive WayneVisser Osborne1FloppyAdapter KiCad project + provenance (#20, #49)
    [FloppyAdapter.kicad_pcb, FloppyAdapter.sch]
2026-10-09 docs: update README with progress since writing + define hardware/ device folders
    - README: new 'What\'s changed' section covering closed research issues
    (#2, #31-#57), corrected hardware notes (74AHCT, dedicated 5V feed),
    updated repo layout (docs/, tools/, hardware/ now real)
    - hardware/: one folder per contemplated device, each with a README
    definition linked to its tracking issues:
    - interposer/ (#11-#24, #45): onboard ESP32 vs personality decision;
    Rev B ships with preinstalled SMT Z84C00 (plug and go)
    - front-panel-ui/ (#14): adds second USB-A keyboard port via interposer
    - usb-keyboard-adapter/ (#47): adds no-open-case external power variant
    - wifi-modem-module/ (#56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
2026-10-09 docs: define firmware/ + software/ trees, MX-80 research, inspired-by, blog site
    - firmware/: 11 components across RP2350/ESP32/RP2040, each with a
    README definition (bus analyzer + snoop engine, RT-60A, Virtual Epson
    MX-80, floppy emulator, Drive C GPIB, ScreenPac video, KVM, CoPower-88
    shim, web UI, Zimodem fork w/ baud buffer + SSH, keyboard matrix)
    - software/: Osborne-side CP/M deliverables (MOUNT.COM, FATCOPY,
    CoPower-88 driver, updated boot disk) + no-new-code docs list
    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
2026-10-10 hardware/fw: Rev A engineering sample, Rev B pin map, OCC1+TurboPac personalities, RT-60A software replica
    - hardware/interposer/reva/: active interposer engineering sample
    (2-off, SMD) - SMT Z84C00, /BUSRQ bus mastering, 595/165 SR fabric,
    Pico 2 + ESP32-C3, W25Q flash; generated KiCad schematic + timing-
    criticality partition of Z80 signals. Rev 0 probe superseded (kept).
    - hardware/interposer/revb/: separate product (live-cycle personality
    engine); full RP2350B 48-GPIO map - 74AHCT688 window detect + /WAIT
    stretching replaces direct address pins; HSTX on GP12-19; LEDs/I2C
    offloaded to ESP32; SPI SD+flash.
    - hardware/o1ng/o1ng-lff/: block-level KiCad skeleton (7 sheets);
    SRAM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
    [clock.kicad_sch, cpu_mem.kicad_sch, floppy.kicad_sch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]
2026-10-10 docs: specify switchable Gotek/physical-drive floppy adapter (#62)
2026-10-10 docs: switch floppy adapter to drive A; add DS-A pull-up finding (#62)
2026-10-10 docs/hardware: settle floppy-adapter open questions + capture Rev A schematic (#62)
    - Resolve all seven open questions in docs/floppy-adapter-design.md sec. 8 with
    primary-source evidence (O1 Field Service Manual 2F00040, O1 disk-electronics
    DWG 1A3004, Gotek SFR1M44-U100K manual, FlashFloppy wiki, Omron G6A datasheet,
    Loxley parts 5/12-15).
    - Correct the pinout: pins 2/4/6 are also GND (DWG 1A3004).
    - Add hardware/floppy-adapter/floppy-adapter.kicad_sch (+ .kicad_pro) and the
    gen_floppy_adapter_sch.py generator; J1 female 2x17 socket on O1 P8, J2
    pass-through, J3 Gotek signals, J4 switched Gotek power, J5 panel switch,
    K1 4PDT relay (DS-A + both rails, fail-safe to physical).
    -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
    [floppy-adapter.kicad_sch]
2026-10-10 hardware: fix mirrored pin placement in interposer schematic generators
    The reva/rev0 generators placed a symbol pin at (x + px, y + py), but KiCad
    stores symbol geometry Y-up while the sheet is Y-down, so the pin actually
    lands at (x + px, y - py). Every wire stub and net label was therefore
    attached to the mirror-image pin and the netlist was broken: reva ERC
    reported 93 errors (85 pin_not_connected + 8 label_dangling), rev0 58.
    - reva/rev0: correct the Y transform in place(), and make Symbol.pin_pos()/
    anchor() use `+hh - off` so `off` really counts down from the top of the box
    (the 'T'/'B' sides were inverted too). Label justification flipped so the
    text runs away from the symbol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
    [rev0.kicad_sch, reva.kicad_sch]
2026-10-10 hardware: correct the Z80 DIP-40 pinout in the interposer generators (#62)
    Both generators carried a Z80 pin table shifted by one pin: pin 1 = A10,
    pin 11 = D6, pin 12 = +5V, pin 30 = GND, pin 31 = A0. The real Zilog DIP-40 is
    pin 1 = A11, pin 11 = +5V, pin 29 = GND, pin 30 = A0 (Z80 Microprocessor Family
    Databook, cross-checked against z80.info/zinout.htm). Because J1 plugs into the
    O1's Z80 socket and J2/U1 mate with the CPU, every address, data and control
    line was tapped one pin off -- the netlist put +5V on the D2 net and shorted
    A0 to GND, which would have damaged a real board.
    - reva/rev0: define the pinout once (Z80_LEFT/Z80_RIGHT) and derive both the
    symbol geometry and Z80NET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
    [rev0.kicad_sch, reva.kicad_sch]
2026-10-10 tools: add a netlist/ERC regression checker and CI job (#62)
    A schematic can pass structural ERC and still be electrically wrong. The
    mirrored-pin defect fixed earlier on this branch produced only
    label_dangling / pin_not_connected, and the '595-on-'165 pile-up that shorted
    GND to A3 produced nothing that named the fault. Reading the exported netlist
    pin by pin found both -- so automate exactly that.
    tools/check_schematics.py (standard library only) regenerates each board's
    netlist with kicad-cli and asserts:
    - datasheet pinouts -- the Z80 DIP-40 table on every connector/CPU that
    mates with the O1's Z80 socket (this is what caught the off-by-one);
    - floppy adapter switching -- DS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
    [check_schematics.py]
2026-10-10 research: index the Rev E schematic set, add a sheet renderer and OCR text (#64)
    The 12-page OCC1_1A2011-00 scan is two drawing sets, not one: pages 1-3 are
    DISK ELECTRONICS (DWG 1A3004-00/01 Rev C, sheets 1-3 of 3, the drive's own
    board) and pages 4-12 are the MAIN PC BOARD (DWG 1A2011-00 Rev E, sheets 1-9
    of 9). Its embedded text layer is an unusable early-90s OCR pass. Both facts
    matter: notes in this repo have cited 1A3004 for mainboard facts.
    - docs/o1-mainboard-schematic.md: sheet index for all 12 pages, how to read a
    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
2026-10-10 hardware: pass TG43/EARLY through on the floppy adapter, not to GND (#62)
    Reading the mainboard schematic itself (DWG 1A2011-00 Rev E, sheet 9 of 9,
    DISC CONTROLLER) rather than the drive-side drawing shows P8 pin 4 = TG43 and
    pin 6 = EARLY, both driven by the FDC through 7406 open-collector buffers, with
    GND = 1,2,3,5,9,19,27,29,31,33. The archived Visser adapter that the pin table
    was transcribed from ties 2, 4, 6 and 7 to GND. That is harmless for a
    Gotek-only adapter, but this card switches the OEM cable through to the
    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
    [floppy-adapter.kicad_sch]
2026-10-10 tools/docs: make the Rev E scan readable, and check the map against the machine (#64)
    Two halves of one problem: the schematic has to be read accurately, and what we
    read has to be checkable.
    Reading it:
    - tools/schematic_atlas.sh renders an overview plus a grid of native-resolution
    tiles for every sheet, and writes an index mapping each tile to the pixel box it
    covers, so a region found by eye once can be re-rendered exactly with
    schematic_render.sh --crop. Output goes to build/ (gitignored): the tiles are
    regenerable, the coordinates are the durable part.
    - That immediately showed the first pass was read at the wrong scale. At 300
    dpi LS00 and LS08 are indistinguishable; sheet 2 actual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
2026-10-10 tools: derive the MAME driver from the boot image, and check the ROM is live (#64)
    The 52-/80-/104- prefix on an O1 floppy image is its *video mode*, not a
    version: a 104-column image needs a SCREEN-PAC, an 80-column one a Nuevo Video
    board, and neither will boot a stock machine. check_o1_map.sh hardcoded one
    local filename, so it broke for any other machine's images.
    - Look for a 52-*.imd first (the stock machine), else any *.imd, and derive the
    driver from whatever is picked - osborne1, osborne1sp or osborne1nv - warning
    when it selects anything but the stock machine, since the checks are written
    for that one. O1_FLOPPY and O1_MACHINE override.
    - Accept an osborne1.zip in the ROM path,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
2026-10-10 tools: keep the MAME Lua discovery probe, and fix the tools/ index title (#64)
    The scratch scripts behind the machine-oracle findings were living in /tmp,
    which is where they would have been lost. tools/research/ exists for exactly
    this - "one-shot extraction scripts, protocol probes, validation scratch
    programs, 'figuring it out' scripts" - so the one that is genuinely reusable is
    preserved there, with the header that folder's rules require.
    - tools/research/mame-lua-probe.lua: what MAME's Lua API exposes inside a
    running machine (spaces, address_mask, data_width, and a map.entries list
    whose entry fields are undocumented and come back nil - so the decode has to
    be *measured*, not r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
2026-10-10 site: add the "Why this project?" post and its three photos (#59)
    The first of the planned articles, and the photos it uses.
    - site/_posts/2026-10-10-why.md -- why the project exists at all, meeting Lee
    Felsenstein at a conference 40-odd years after he designed the machine, the
    three-machine fleet (Original / Single / Max, and the CoPower-88 that came
    with Max), the 80-column RCA-jack tell, the planned lunchbox re-implementation
    of the O1, and the 8 MHz "turbo" idea with its three costs.
    - site/assets/ -- jamie-and-lee.jpeg, stack-of-boards.jpeg, swp-8088.jpeg.
    One fix while committing: the post's image references were .jpg while the files
    are .jpeg, so all three would have publish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
2026-10-10 site: size the post's photos for the web, keep full-res for the board shots (#59)
    13 MB of photos in one post is slow on a phone, and site/README.md's own note
    says to keep them reasonably sized. But the board photos are the point of that
    section - "look at this stack, what is in there" - so shrinking them
    irreversibly would throw away exactly the detail a reader wants to examine.
    So: inline at 1400px on the longest side, full resolution kept alongside and
    linked from the image itself.
    file inline full-res kept
    jamie-and-lee.jpeg 1050x1400 446K - (people, 4.3M original not needed)
    stack-of-boards.jpeg 1400x1050 599K stack-of-boards-full.jp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
2026-10-10 site: ignore local Jekyll build output (#59)
    Now that main's Pages workflow builds from site/ (source: ./site,
    destination: ./_site), any local Jekyll run litters the repo with _site/,
    .jekyll-cache/ and a Gemfile.lock from a local bundle install. None of it
    belongs in the tree: the workflow uses actions/jekyll-build-pages@v1, which
    installs its own dependencies, and there is no Gemfile in the repo.
    Gemfile.lock is the arguable one - committing it would pin local builds. It is
    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
2026-10-10 research: archive inventory + provenance for the 2026-10 drop (#71)
    Commits the research-archive portion of the 2026-10 drop (72 files) with
    per-file provenance in research/README.md, and corrects four provenance claims
    that were wrong. The emulator harness (tools/emulator-setup/) follows in a
    separate PR.
    Added:
    - adaptec/ Adaptec ACB-4000 (MD-10/MD-20) utilities + Osborne Hard Disk
    Control Software v2.01 (1984), as raw O1 SSSD images with
    disk-label photos (Internet Archive) - #8
    - diagnostics/ Osborne 1 System Confidence Test 2.04 and OCC1 diag 2.1
    (bitsavers) - the known-good images #29 needs
    - gotek/FF/ The project's own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
    [FF.CFG, IMG.CFG]
2026-10-10 docs: canonical O1 ROM inventory + third-party ROM survey (#70)
    Adds docs/o1-rom-variants.md: every Osborne 1 ROM image we hold, keyed by
    CRC32 and size and cross-referenced against MAME's driver and ROM sets.
    Findings recorded:
    - There are TWO character-generator images, not one. MAME pairs 5297c109
    with BIOS A..1.4 and 6c1eab0d with BIOS 1.43/1.44 - the early/late font
    distinction #44 asks about. Both are now in the repo.
    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
2026-10-10 docs: index the O1 ROM 1.44 / CBIOS source and cross-check the I/O map (#72)
    Adds docs/o1-rom-source.md: an index of Osborne's own firmware source and what
    it confirms about the machine.
    Headline result: the source's own port map agrees with
    docs/o1-memory-io-map.md section 3 on every row - floppy 2100-2103, keyboard
    2200, IEEE-488 PIA 2900-2903, 6850 ACIA 2A00-2A01, video PIA 2C00-2C03. That
    map was derived from the schematic and the running machine; it now has a third,
    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
2026-10-10 tools: research IMD reader + MAME boot probe, and the measured MAME results (#79)
    Adds two working tools to tools/research/ and the results they produced.
    - imdinfo.py -- stdlib-only ImageDisk reader: reports an image's structure
    (mode/density, cylinders, heads, sector size, sectors per track) and can
    reconstruct a raw image. Its reconstructed output is byte-identical to
    disk-analyse's on the same image, which is how the parser was validated.
    Written after a first attempt got the format wrong: IMD has no "sector type
    map" -- the type byte belongs to each sector's data record, and the optional
    cylinder/head maps are flagged in bits 7/6 of the *head* byte. That mistake is
    record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
2026-10-10 research: extract the UA15 char-gen socket off sheet 4 of 9 (#64 #24)
    Gap #3's second half -- and it was pointing at the wrong sheet. UA15 is the
    2716 character-generator ROM on mainboard sheet 4 of 9 (PDF page 7, title
    block "RAM"), not a 74S244 on sheet 5. Read at 1200 dpi.
    - standard Intel 2716 pinout, pin for pin (A8=23, A9=22, A10=19)
    - /CE (18) and /OE (20) are bussed with GND and grounded, so the ROM is
    permanently selected and always driving O0-O7: a socket tap can read it
    but cannot tristate it. That is #24's font-capture constraint.
    - pin 21 strapped +5V -- a 2732-style socket with a 2 KiB part fitted
    - address = (scan<<7)|char, with A7-A10 = SCAN0-SCAN3 from UD17/UD18
    (74LS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
    [check_schematics.py]
2026-10-10 docs: record the Nuevo decision, close #79 as not needed (#79 #24)
    The Nuevo path is not pursued: the video personality is built from the
    ScreenPac design plus OZROM's soft 52/80/104-column switch, and the Nuevo
    board stays prior art (#73). Nothing in the Nuevo design has turned up a
    feature worth the validation cost.
    - docs/mame-emulation.md sec.4: the hang is recorded, with the decision and
    the residual MAME-fidelity question, instead of "Unresolved - see #79"
    - docs/research-gaps.md: B3 rewritten, gap 13 note, the #79 tracker row, and
    the blocker list no longer waits on it
2026-10-10 research: resolve both archive provenance TODOs (#74)
    Unknown 1 - research/copower88/swp/
    Source is kayprojournal.com's "Swp copower 88" page
    (https://kayprojournal.com/index.php/Swp_copower_88). Confirmed by querying
    the wiki API rather than reading the page: prop=images lists all five of our
    files by name - Copower User guide.pdf, Swp ad.jpg, and 73356 {8088,mem,cpu}
    card.jpg, of which the three photos are held as 1600px/866px thumbnails.
    The wiki also carries Copower sch 1..4.pdf, a second copy of the SWP
    schematics we hold from zorba.z80.de.
    Unknown 2 - research/nuevo/NUEVO151.BIN
    Deleted. It is byte-identical to the tracked
    tools/emulator-setup/roms/monrom-rev1.51-12.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

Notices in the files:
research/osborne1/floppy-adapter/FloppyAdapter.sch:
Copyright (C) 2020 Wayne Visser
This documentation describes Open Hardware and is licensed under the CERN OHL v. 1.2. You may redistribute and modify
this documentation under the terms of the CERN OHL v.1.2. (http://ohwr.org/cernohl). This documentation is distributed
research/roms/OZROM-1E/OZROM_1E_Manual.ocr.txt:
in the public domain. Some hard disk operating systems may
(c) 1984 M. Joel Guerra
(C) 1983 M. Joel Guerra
